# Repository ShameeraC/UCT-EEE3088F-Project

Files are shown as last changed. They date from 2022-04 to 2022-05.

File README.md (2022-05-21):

# EEE3088F Group 18 Sensing HAT (Version 1.0)
This project is a group project for the course EEE3088F at UCT. The purpose of the HAT is to detect light and move a motor or another device in the direction of the light.

# Instructions For Use (For Version 1.0)
    
    - Hardware Requirements - 

    To use this HAT, a mini-USB connector is required to interface the HAT with the STM 
    (Or whatever other microcontroller is in use). That being said, an STM32F0 discovery board, 
    or another board containing a microcontroller with read/write/ADC/memory capabilities must be used if 
    the full functionality of the HAT is to be claimed.
    The USB must be capable of data transmission.
    A 5V Li-Ion battery and battery holder are necessary for the powering of the HAT, unless some other 
    power source is to be used. Jumper cables are necessary for the current design, as it does not conform
    to the general standard of board measurements (they are needed to connect the HAT to the board in use).
   
    - Software Requirements -

    The coding of this board can be done via the STM Cube IDE (preferred) or Code Blocks. Other coding
    platforms can work as well. The terminal must be configured to drive the USB ports that connect to the
    discovery board or the HAT. 
    Programs can be uploaded to the STM or to the HAT itself, depending on which method is preferred.
    The EEPROM on the HAT must be coded via the HAT's USB port, as this sends data to and from the FTDI
    and the EEPROM on board the HAT together. 
    Currently the HAT has not been revised, and secondary versions have not yet been created. Because of this,
    the recommended approach to coding is to do so via the STM or the board in use (and not via the HAT).
    The temperature sensor which sends data to and from the HAT's EEPROM was not populated in version 1.0,
    and as such the EEPROM and the FTDI on board the HAT are not needed or useful currently.
    Thus, any code that is written should be uploaded directly to the board in use, after which wiring
    can interface the board with the HAT.

    - Initialization Instructions -

    To initialize the hardware, connect the battery to the HAT to power the STM board (if batteries 
    are not being used, find another way to connect the HAT to power). Connect each 
    pin on the STM to the corresponding pin on the HAT via jumper wires.
    To initialize the software, connect to the board via a USB, and compile and upload the desired 
    code to the board via an appropriate IDE. How to upload code to the board will vary from IDE to
    IDE. Check the IDE's online documentation for further details.

    - Running Your First Program on the HAT - 

    To run your first program on the HAT, refer to the self-explanatory code in the "main.c" file
    in the following directory:
    "Firmware/GROUP18 Microcontroler Interfacing/Core/src/main.c"
    This file can be run to toggle two user connected LEDs based on the strength of light sensed by
    the LDRs on the HAT. To set up the hardware for this basic program, two LEDs should be connected
    in series with 1k resistors which will be connected to GPIOA and GPIOB on the STM (GPIO pin 10 and
    pin 12 respectively). Alternitavely, the LEDs on the STM can be flashed based on the state of the
    LDRs if the STM LEDs are set to "HIGH" in the lightSensingInit() function (this would need to be
    added). Inside of the while loop in the code, the first statement is a call to initialize the light
    sensing sequence, and so everything is set up for ease of use.
    Have fun!! 

# Directories:
This repo has the following subfolders, which provide a useful common structure for custom electronics projects: \
    * Documentation: Project documentation (including submissions) and component datasheets are stored here.\
    * Firmware: Any software developed for the hat will be stored here.\
    * PCB: This includes all KiCad files (schematics, pcb, gerber files, footprints etc.). The main KiCad folder is here. \
    * Production: The gerber files, BOM, Budget, or anything required by JLCPCB will be stored here. \
    * Simulation: Any simulation files (eg SPICE) or design stage generated results (Eg matlab or excel) will be stored here.

# PCB Designers:
JONATHAN APPS \
SHAMEERA CASSIM \
JAHAR PERSAD 

# License
[Creative Commons Attribution 4.0 International license](https://choosealicense.com/licenses/cc-by-4.0/)

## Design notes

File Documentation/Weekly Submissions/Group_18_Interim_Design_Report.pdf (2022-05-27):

UNIVERSITY OF CAPE TOWN

EEE3088F, 2022

INTERIM DESIGN REPORT:

LIGHT TRACKING AND TEMPERATURE SENSING HAT

APRIL 4, 2022

GROUP 18

JONATHAN APPS (APPJON001)

SHAMEERA CASSIM (CSSSHA020)

JAHAR PERSAD (PRSJAH002)

### 1. Executive Summary

The following report documents the design process and current design of a Discovery board HAT intended for use as a light tracking device. For reference, PCB design files are available in the following Gitlab repository:

https://gitlab.com/g5168/eee3088f-group-18-project

The report begins by introducing the HAT concept as well as its use case, design details, and key results. A block diagram is used to overview the final design, after which the specifications for each submodule are detailed (power, microcontroller interfacing, sensing). Power budget analyses for the submodules, as well as for the entire design are then given. The design processes are then overviewed, and lastly conclusions are made.
For further details, including licensing, reusing, and deploying, see the gitlab repository.

### 2. Introduction

The HAT was designed to operate a rotating frame which is intended to sense the direction in which the light is brightest. The HAT will be programmed to rotate the frame, using 2 motors, to point its face in the direction of maximum brightness. This design can be used for many applications, although its primary use case is intended to be to efficiently generate power through solar panels. A small solar panel could be connected to the face of the frame (this will be omitted from the design however, as solar panels will be connected to the frame by the user) and the rotation of the frame will allow for optimal sunlight to be provided to the panel at all times.

The HAT uses 2 sensor types (one digital, one analog) to support this design. The digital sensor is a temperature sensor (LM75B) which monitors the temperature of the HAT to check for overheating (which causes design/solar panel inefficiencies). The analog sensor is made up of 2 photoresistors (GL5549’s), which enable the evaluation of brightness on both sides of the HAT. This in turn enables the controlling of the peripheral device’s rotation.

The HAT’s power module uses batteries to drive the operation of the sensors and the microcontroller interfacing. Under-voltage protection, battery polarity-protection, and input voltage polarity protection are some of the features that operate the HAT in a stable manner. The HAT includes microcontroller interfacing abilities, which enable the transmission of data to and from the STM32.

This design could be implemented for small-scale energy projects. Users who desire the powering of a small device (during load shedding for instance) could use the HAT to generate power for a load. It could also be used for small robots which need to track light.

For this to be a useful design, the power generated by the HAT must exceed the power consumed by the HAT. The power specifications for this design will thus be discussed later in this report. The total cost of the HAT was approximately $62.33, excluding shipping costs.

### 2.1. Project Subsystems Block Diagram

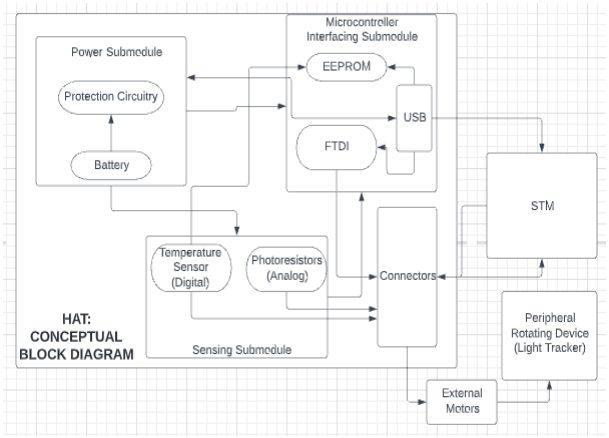
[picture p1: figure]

Figure 1: Projects Subsystem Block Diagram

### 3. Specifications

### 3.1 Power Subsystem Submodule

This submodule delivers 5V, and receives a voltage between 4.5 and 6V. The max current in the circuit is 22mA, the reason it was done this way is that anything above 30mA will blow the LED.

The circuit contains the following circuits/components:
1. A 18650 connector (DNP)
2. A Li-Ion battery charger
3. Input voltage polarity protection
4. Battery polarity protection
5. Battery Under-voltage cutout protection
6. This module will provide an output of 5V

There were 2 ICs used:
1. MT3608L - DC-DC converter, used to step up the voltage to a constant 5V to be outputted from the submodule
2. TP4054 - Used to charge the battery

Parts List
Part | LCSC | Datasheets
R1 | C4177 | https://datasheet.lcsc.com/lcsc/2110251730_UNI-ROYAL-Uniroyal-Elec-0603WAF1801T5E_C4177.pdf (https://datasheet.lcsc.com/lcsc/2110251730_UNI-ROYAL-Uniroyal-Elec-0603WAF1801T5E_C4177.pdf)
R2 | C22775 | https://datasheet.lcsc.com/lcsc/2110252030_UNI-ROYAL-Uniroyal-Elec-0603WAF1000T5E_C22775.pdf (https://datasheet.lcsc.com/lcsc/2110252030_UNI-ROYAL-Uniroyal-Elec-0603WAF1000T5E_C22775.pdf)
R3 | C22775
R4 | C22775
R5 | C22765 | https://datasheet.lcsc.com/lcsc/2110252030_UNI-ROYAL-Uniroyal-Elec-0603WAF1201T5E_C22765.pdf (https://datasheet.lcsc.com/lcsc/2110252030_UNI-ROYAL-Uniroyal-Elec-0603WAF1201T5E_C22765.pdf)
R6 | C25805 | https://datasheet.lcsc.com/lcsc/2110260030_UNI-ROYAL-Uniroyal-Elec-0603WAF1103T5E_C25805.pdf (https://datasheet.lcsc.com/lcsc/2110260030_UNI-ROYAL-Uniroyal-Elec-0603WAF1103T5E_C25805.pdf)
R7 | C22809 | https://datasheet.lcsc.com/lcsc/2110252030_UNI-ROYAL-Uniroyal-Elec-0603WAF1502T5E_C22809.pdf (https://datasheet.lcsc.com/lcsc/2110252030_UNI-ROYAL-Uniroyal-Elec-0603WAF1502T5E_C22809.pdf)
Charging IC(TP4054) | C32574 | https://datasheet.lcsc.com/lcsc/1809261814_TOPPO WER-Nanjing-Extension-Microelectronics-TP4054-42- (https://datasheet.lcsc.com/lcsc/1809261814_TOPPOWER-Nanjing-Extension-Microelectronics-TP4054-42-SOT25R_C32574.pdf)

| | SOT25R_C32574.pdf (https://datasheet.lcsc.com/lcsc/1809261814_TOPPOWER-Nanjing-Extension-Microelectronics-TP4054-42-SOT25R_C32574.pdf)
DC-DC Converter(MT3608L) | C2932326 | https://datasheet.lcsc.com/lcsc/2201121530_XI-AN-Aerosemi-Tech-MT3608L_C2932326.pdf (https://datasheet.lcsc.com/lcsc/2201121530_XI-AN-Aerosemi-Tech-MT3608L_C2932326.pdf)
C1 | C15849 | https://datasheet.lcsc.com/lcsc/1811061822_FH-Guan gdong-Fenghua-Advanced-Tech-0603CG6R0C500NT _C37474.pdf (https://datasheet.lcsc.com/lcsc/1811061822_FH-Guangdong-Fenghua-Advanced-Tech-0603CG6R0C500NT_C37474.pdf)
C2 | C45783 | https://datasheet.lcsc.com/lcsc/1811151152_Samsung-Electro-Mechanics-CL21A226MAQNNNE_C45783.p df (https://datasheet.lcsc.com/lcsc/1811151152_Samsung-Electro-Mechanics-CL21A226MAQNNNE_C45783.pdf)
D1 | C84256 | https://datasheet.lcsc.com/lcsc/1810010213_Everlight-Elec-PT17-21C-L41-TR8_C100090.pdf (https://datasheet.lcsc.com/lcsc/1810010213_Everlight-Elec-PT17-21C-L41-TR8_C100090.pdf)
D2 | C84256
D3 | C191023 | https://datasheet.lcsc.com/lcsc/1810202112_Guangdong-Hottech-1N5819WS_C191023.pdf (https://datasheet.lcsc.com/lcsc/1810202112_Guangdong-Hottech-1N5819WS_C191023.pdf)
L1 | C383376 | https://datasheet.lcsc.com/lcsc/1912111437_TDK-MLP2012V4R7MT0S1_C383376.pdf (https://datasheet.lcsc.com/lcsc/1912111437_TDK-MLP2012V4R7MT0S1_C383376.pdf)
Q1 | C118536 | https://datasheet.lcsc.com/lcsc/1912111437_Foshan-Blue-Rocket-Elec-2N2222A_C358533.pdf (https://datasheet.lcsc.com/lcsc/1912111437_Foshan-Blue-Rocket-Elec-2N2222A_C358533.pdf)

### 3.1.1 Power Subsystem Schematic

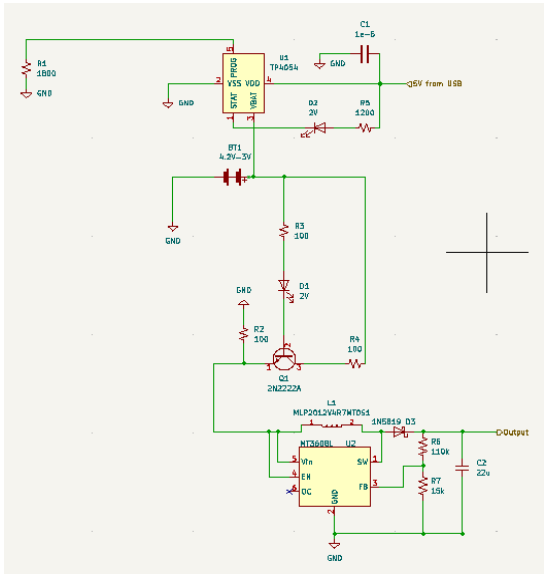
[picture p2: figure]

Figure 2: Power Subsystem Schematic

Location in git:
https://gitlab.com/g5168/eee3088f-group-18-project/-/blob/main/PCB/main/power.kicad_sch

### 3.1.2 Conclusion

This design is deemed safe, there is a bit of uncertainty when it comes to the calculations of how much current is flowing through this module, but otherwise it seems safe. It is not the most efficient design since a lot of parts that have a power dissipation associated were used. But the design should be able to perform its duties.

### 3.2 Microcontroller Interfacing Submodule

### 3.2.1 Specifications

The specifications for this submodule have been tabulated below:
Item | Requirement | Specification | Additional Notes and Documentation Links
| Memory
| This subsection includes communication protocols, both the ICs used for memory and their power specifications.
M1 | Key configuration data must be kept in a non-volatile medium and data from the temperature sensor must be time-stamped and stored alongside this throughout the operational period | EEPROM needs to be used to store configuration data and to read in and store data from the temperature sensor. The AT24C256C-SSHL-T is a 256-Kbit EEPROM chip with a SOIC-8_3.9x4.9x1.27P package. Memory can be retrieved from the line connected to the WP pin of the EEPROM. This IC operates between 1.7V and 5.5V with a maximum current of 2mA for reading data and 3mA for writing data at V=5V. | Datasheet: https://datasheet.lcsc.com/lcsc/1809151932_Microchip-Tech-AT24C256C-SSHL-T_C6482.pdf (https://datasheet.lcsc.com/lcsc/1809151932_Microchip-Tech-AT24C256C-SSHL-T_C6482.pdf)
M2 | Translate USB to UART to be written to the STM | A CH340C chip can be used to interface between the USB and memory. The chip “translates” the data from USB to USART in the form of an array. The typical operating conditions for this IC is a 5V supply voltage and a 7mA current. It has a maximum current of 20mA. | Datasheet: https://www.mpja.com/download/35227cpdata.pdf (https://www.mpja.com/download/35227cpdata.pdf)
| Clock
C1 | Measure at a minimum of 1/60 Hz which is required to be soft-configurable. | PA8 connected to the STM32F051 will be used. The pin will be programmed to output the relevant clock signal.

| USB
U1a | Transfer data and provide power. The USB provides 5V (VCC_in). | A MicroXNJ USB Surface Mount Micro-B/USB Connector is used for power and data transfer. | Datasheet: https://datasheet.lcsc.com/lcsc/2204151400_SHOU-HAN-MicroXNJ_C404969.pdf (https://datasheet.lcsc.com/lcsc/2204151400_SHOU-HAN-MicroXNJ_C404969.pdf) https://gitlab.com/g5168/eee3088f-group-18-project/-/blob/main/Documentation/Datasheets/2204151400_SHOU-HAN-MicroXNJ_C404969%20TRANSLAT ED.pdf (https://gitlab.com/g5168/eee3088f-group-18-project/-/blob/main/Documentation/Datasheets/2204151400_SHOU-HAN-MicroXNJ_C404969%20TRANSLATED.pdf) (both used in conjunction as translation is not fully clear)
U1b | | A USB-MicroB cable is needed to connect the microcontroller to the HAT. | These may be reused from the equipment given out for EEE2046F.

Parts List
Component | LCSC | Datasheet
EEPROM -AT24C256C-SSHL-T | C6482 | https://datasheet.lcsc.com/lcsc/1809151932_Microchip-Tech-AT24C256C-SSHL-T_C6482.pdf (https://datasheet.lcsc.com/lcsc/1809151932_Microchip-Tech-AT24C256C-SSHL-T_C6482.pdf)
FTDI - CH340C | C84681 | https://www.mpja.com/download/35 227cpdata.pdf (https://www.mpja.com/download/35227cpdata.pdf)
MicroXNJ | C404969 | https://datasheet.lcsc.com/lcsc/2204151400_SHOU-HAN-MicroXNJ_C 404969.pdf (https://datasheet.lcsc.com/lcsc/2204151400_SHOU-HAN-MicroXNJ_C404969.pdf)
R14 | C25804 | https://datasheet.lcsc.com/lcsc/2110260030_UNI-ROYAL-Uniroyal-Elec-0603WAF1002T5E_C25 804.pdf (https://datasheet.lcsc.com/lcsc/2110260030_UNI-ROYAL-Uniroyal-Elec-0603WAF1002T5E_C25804.pdf)
R15 | C21190 | https://datasheet.lcsc.com/lcsc/2110252030_UNI-ROYAL-Uniroyal-Elec-0603WAF1001T5E_C21 190.pdf (https://datasheet.lcsc.com/lcsc/2110252030_UNI-ROYAL-Uniroyal-Elec-0603WAF1001T5E_C21190.pdf)
R16 | C21190
R17 | C21190
R18 | C23162 | https://datasheet.lcsc.com/lcsc/2110252130_UNI-ROYAL-Uniroyal-Elec-0603WAF4701T5E_C23 162.pdf (https://datasheet.lcsc.com/lcsc/2110252130_UNI-ROYAL-Uniroyal-Elec-0603WAF4701T5E_C23162.pdf)

R19 | C21189 | https://datasheet.lcsc.com/lcsc/2 110252030_UNI-ROYAL-Uniroy al-Elec-0603WAF0000T5E_C21 189.pdf (https://datasheet.lcsc.com/lcsc/2110252030_UNI-ROYAL-Uniroyal-Elec-0603WAF0000T5E_C21189.pdf)
R20 | C21189
D4 (SS14) | C2480 | https://datasheet.lcsc.com/lcsc/2 105061432_MDD-Microdiode-El ectronics--SS14_C2480.pdf (https://datasheet.lcsc.com/lcsc/2105061432_MDD-Microdiode-Electronics--SS14_C2480.pdf)
C4 | C14663 | https://datasheet.lcsc.com/lcsc/1 809301912_YAGEO-CC0603KR X7R9BB104_C14663.pdf (https://datasheet.lcsc.com/lcsc/1809301912_YAGEO-CC0603KRX7R9BB104_C14663.pdf)

### 3.2.2 Microcontroller Interfacing Subsystem Schematic

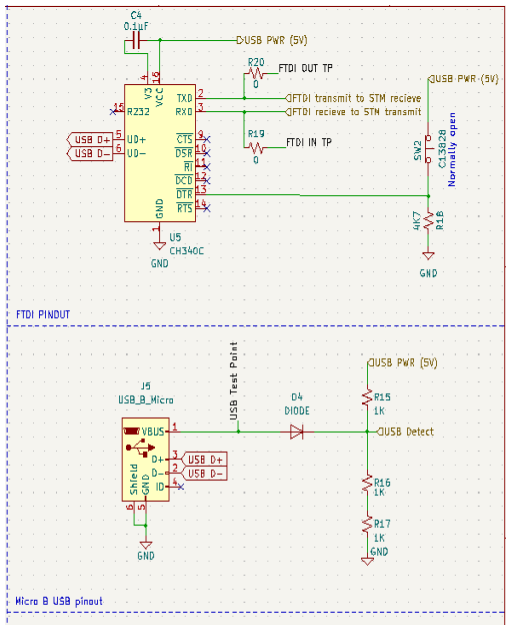
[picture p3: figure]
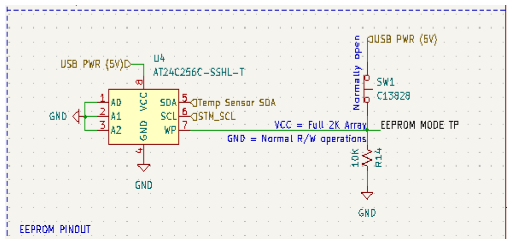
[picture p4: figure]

Figure 3: Microcontroller Interfacing Subsystem Schematic

Location in git:
https://gitlab.com/g5168/eee3088f-group-18-project/-/blob/main/PCB/main/microcontroller_interfacing.kicad_sch (https://gitlab.com/g5168/eee3088f-group-18-project/-/blob/main/PCB/main/microcontroller_interfacing.kicad_sch)

### 3.2.3 Conclusion:

The design is safe, sufficient and largely should work. An outstanding issue that was picked up after submitting the gerbers was that the output of the EEPROM is not connected to an STM pin and hence is not writing to anything. Thus, the information being stored in the EEPROM cannot be seen. Fixing this will require the soldering of a wire to the PCB and using that to connect to the STM to write the data to I2C (this will be done when the PCB is returned). It has also been noted that the schottky diode used was replaced by an LED when gerbers and assembly documentation was uploaded to jlcpcb. This will also be rectified when the PCBs are returned. The documentation in this report takes into account the schottky diode and not the LED.

### 3.3 Sensing submodules

The specifications for this submodule have been tabulated below:

### 3.3.1 Digital Sensor Specification

Item | Specifications | Additional Notes | Datasheet Links
1 | One LM75BD Temperature sensor is used. | This operates at 2.8V - 5.5V, and as such is perfect for the HAT as a digital sensor. Further operating conditions can be found in the attached datasheet. | https://datasheet.lcsc.com/lcs c/2110111830_UMW-Youtai- Semiconductor-Co---Ltd--LM 75BD_C725792.pdf (https://datasheet.lcsc.com/lcsc/2110111830_UMW-Youtai-Semiconductor-Co---Ltd--LM75BD_C725792.pdf)
2 | One red LED (BL-HUE35A-AV-TRE) is used to indicate that the temperature is outside optimal functioning conditions.

This is connected to a pin which reads the LM75. The
temperature data register
will be polled to ensure that when the temperature
exceeds a specified limit, the LED is lit up.

https://datasheet.lcsc.com/szlcsc/1809192334_BrtLed-Brig ht-LED-Elec-BL-HUE35A-AV-TRE_C138549.pdf (https://datasheet.lcsc.com/szlcsc/1809192334_BrtLed-Bright-LED-Elec-BL-HUE35A-AV-TRE_C138549.pdf)

3 | 20mA of forward current through the LED must not be exceeded. | Thus, a resistor in place to ensure correct operation (see Item 4). | N/A
4 | Items 2 and 3 necessitate the use of a 300Ω resistor. Unfortunately this was overlooked during the design process, and a 10kΩ resistor was used | Performing a KVL analysis on a 5V power supply in series with a 300Ω resistor (with a forward voltage | N/A

| instead. This will be corrected when the PCB is returned. | drop of 3V) and a 2V LED, shows that the current through the LED will be: I = V/R = 3/300 = 10mA. This is a correct operating current for the LED.
5 | One C45783 capacitor was used, to decouple the signal at the Vcc pin. | This adds safety from undesirable noise signals. | https://datasheet.lcsc.com/lcsc/1809291518_TORCH-CT4 1G-0402-2X1-16V-0-1-F-K-N _C141382.pdf (https://datasheet.lcsc.com/lcsc/1809291518_TORCH-CT41G-0402-2X1-16V-0-1-F-K-N_C141382.pdf)
6 | Three RCT0310KJLF 0.1W, 10KΩ resistors are used. No more than 0.1W is dissipated by each resistor. | These act as pull-ups for the temperature sensors. Pull-up resistors are necessary for this temperature circuit configuration at the bus output and the interrupt line. | https://datasheet.lcsc.com/lcsc/1810161330_HKR-Hong-K ong-Resistors-RCT0310KJL F_C177337.pdf (https://datasheet.lcsc.com/lcsc/1810161330_HKR-Hong-Kong-Resistors-RCT0310KJLF_C177337.pdf)

### 3.3.2 Analog Sensor Specification

Item | Specifications | Additional Notes | Datasheet Links
1 | The HAT uses 2 GL48516 photoresistors (LDRs). | These assume values of 5-10 KΩ at 10 LUX, and approximately 0.2 MΩ in the dark. | https://datasheet.lcsc.com/lcsc/2009121137_JCHL-She nzhen-Jing-Chuang-He-Li-T ech-GL48516_C779572.pdf (https://datasheet.lcsc.com/lcsc/2009121137_JCHL-Shenzhen-Jing-Chuang-He-Li-Tech-GL48516_C779572.pdf)
2 | Two RCT0310KJLF 0.1W, 10KΩ resistors were used. No more than 0.1W is dissipated by each resistor. | These were placed in series with the LDRs in 2 separate voltage divider configurations. | https://datasheet.lcsc.com/lcsc/1810161330_HKR-Hon g-Kong-Resistors-RCT0310 KJLF_C177337.pdf (https://datasheet.lcsc.com/lcsc/1810161330_HKR-Hong-Kong-Resistors-RCT0310KJLF_C177337.pdf)
3 | The LDRs were placed on opposite sides of the HAT to ensure that the light on each of them is slightly different. | The photoresistors cannot be placed very closely together on the final HAT pcb. | N/A
4 | The outputs from the voltage divider configurations operate between 2.4V and 3.6V. | GPIO pins in analog mode operate between 2.4V and 3.6V. ADC pins will be | N/A

| | needed when the software is implemented.
5 | Item 4 implies that the input voltage should lie at around 5V. Thus the input voltage to the photoresistor voltage divider configuration was connected to the STM32F0’s 5V pin. | This was an important design decision for the pcb’s routing. | N/A

### 3.3.3 Sensing Submodule Schematic

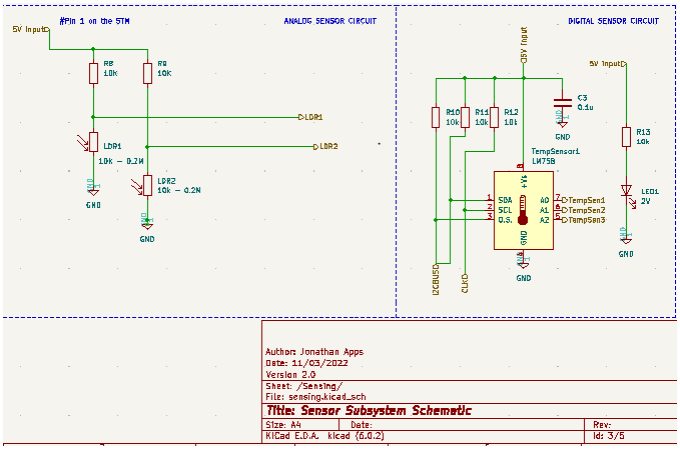
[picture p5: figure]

Figure 4: Sensing Subsystem Schematic

Location on git:
https://gitlab.com/g5168/eee3088f-group-18-project/-/blob/main/PCB/main/sensing.kicad_sch (https://gitlab.com/g5168/eee3088f-group-18-project/-/blob/main/PCB/main/sensing.kicad_sch)

### 3.3.4 Conclusion

This module relies heavily on the power and microcontroller interfacing modules to function. Provided that those modules function correctly, the sensing submodule should function correctly as it is very simple in terms of design and components. The sensors are adequately designed and thus sufficient for the purposes they are needed for. There is one clear error in the design of this module, which is the use of a 10kΩ resistor in place of the necessary 300Ω. The 10kΩ resistor will be replaced with the 300Ω resistor once the pcb is returned.

### 4. Power Budget Analysis

### 4.1 Power Submodule Budget Analysis

Component | Supply Voltage (nominal V) | Min Current (mA) | Typical Current (mA) | Max Current (mA) | Min Power (mW) | Typical Power (mW) | Max Power (mW)
TP4054 | 5 | 90 | 100 | 110 | 450 | 500 | 550
R1 | 3-4.2 | 10 | 22 | 30 | 36 | 79.2 | 108
R2 | 3-3.5 | 10 | 22 | 30 | 32.5 | 71.5 | 97.5
R3 | 3-4.2 | 10 | 22 | 30 | 36 | 79.2 | 108
R4 | 5 | 10 | 22 | 30 | 50 | 110 | 150
R5 | 5 | 10 | 22 | 30 | 50 | 110 | 150
R6 | 5 | 10 | 22 | 30 | 50 | 110 | 150
R7 | 5 | 10 | 22 | 30 | 50 | 110 | 150
C1 | 5 | 10 | 22 | 30 | 50 | 110 | 150
C2 | 5 | 10 | 22 | 30 | 50 | 110 | 150
D1 | 3-4.2 | 10 | 22 | 30 | 36 | 79.2 | 108
D2 | 5 | 10 | 22 | 30 | 50 | 110 | 150
D3 | 5 | 10 | 22 | 30 | 50 | 110 | 150
L1 | 5 | 10 | 22 | 30 | 50 | 110 | 150
MT3608L | 0.01-1.5 | - | 1.6 | 2.2 | - | 2.4 | 3.3
Total | | | | | 998.5 | 1709.1 | 2198.8

### 4.2 Microcontroller Interfacing Submodule Budget Analysis

Component | Supply Voltage (nominal V) | Min Current (mA) | Typical Current (mA) | Max Current (mA) | Min Power (mW) | Typical Power (mW) | Max Power (mW)
EEPROM -AT24C256C -SSHL-T (read/write) | 5.0 | - | 1 | 2 | - | 5 | 10
| 5.0 | - | 2 | 3 | - | 10 | 15
FTDI -CH340C | 3.3 | - | 7 | 20 | - | 23.10 | 66
R14 | 5 | 10 | 22 | 30 | 50 | 110 | 150
R15 | 5 | 10 | 22 | 30 | 50 | 110 | 150
R16 | 5 | 10 | 22 | 30 | 50 | 110 | 150
R17 | 5 | 10 | 22 | 30 | 50 | 110 | 150
R18 | 5 | 10 | 22 | 30 | 50 | 110 | 150
R19 | 5 | 10 | 22 | 30 | 50 | 110 | 150
R20 | 5 | 10 | 22 | 30 | 50 | 110 | 150
D4 (SS14) | 5 | 10 | 22 | 30 | 50 | 110 | 150
C4 | 5 | 10 | 22 | 30 | 50 | 110 | 150
Total | | | | | 450.00 | 1028.10 | 1441.00

### 4.3 Sensing Submodules Budget Analysis

Component | Supply Voltage (nominal V) | Min Current (mA) | Typical Current (mA) | Max Current (mA) | Min Power (mW) | Typical Power (mW) | Max Power (mW)
R8 | 5 | 0.025 | 0.2 | 0.25 | 0.125 | 1 | 1.25
R9 | 5 | 0.025 | 0.2 | 0.25 | 0.125 | 1 | 1.25

R10 | 5 | 0.14 | 0.2 | 0.5 | 0.7 | 1 | 2.5
R11 | 5 | 0.14 | 0.2 | 0.5 | 0.7 | 1 | 2.5
R12 | 5 | 0.14 | 0.2 | 0.5 | 0.7 | 1 | 2.5
R13 | 5 | 9 | 10 | 11 | 45 | 50 | 55
C3 | 5 | 0 | 0.2 | 0.5 | 0 | 1 | 2.5
LED1 | 2 | 9 | 10 | 11 | 18 | 20 | 22
LDR1 | 2.4-3.6 | 0.025 | 0.0476 | 0.25 | 0.06 | 0.14 | 0.216
LDR2 | 2.4-3.6 | 0.025 | | 0.25 | 0.06 | 0.14 | 0.216
LM75B | 5 | 0.004 | 0.28 | 0.4 | 0.02 | 1.4 | 2
Total | | | | | 65.49 | 77.68 | 91.932

### 4.4 System Total

Submodule | Minimum Power(mW) | Typical Power(mW) | Maximum Power(mW)
Power | 984.50 | 1678.30 | 2156.80
Sensing | 65.49 | 77.68 | 91.932
Microcontroller Interfacing | 450.00 | 1028.10 | 1441.00
Totals | 1499.99 | 2784.08 | 3689.73

### 5. Design process

The design process for this board was as follows:
Each team member developed a design for their respective submodule, after which the team met and discussed whether the designs would work well in conjunction with each other and revisions of each submodule were made. The design process was iterative, it started off with a base design which was improved each week to get the final product.

Key decisions relating to the schematics that were made include:

- The removal of the operational amplifier after the first revision as it would drain the battery even after the under voltage cut out protection kicked in (power module).
- The step down dc-dc converter was swapped out for a step up dc-dc converter as this mitigated the need to amplify the voltage after the transistor before entering the previously used step down dc-dc converter. This also resulted in the final design of the power submodule using less components overall. (power module)
- The initial EEPROM chosen was changed to match that suggested by the lecturers. This EEPROM IC matched the specifications of the project better and there are more resources available on how to use it effectively. (microcontroller interfacing module)
- The FTDI chip was chosen specifically to include an internal crystal oscillator so that one would not have to be included on the board. This allows for the design of an individual oscillator to be avoided (microcontroller interfacing module).
- Initially, there were 4 photoresistors, 2 of which enabled the HAT to rotate the peripheral module based on the light strengths on it. This, along with a push button controlling whether on-HAT or on-peripheral LDRs would be used to sense light, was removed. This removal was done to save power and remove complexity from the design (sensor module).

Key decisions that were made with regards to the PCB include:

- The GND plane was chosen to be on the front copper layer(top) and the +5V plane on the back copper layer(bottom), as this allowed for more efficient tracing (more components required ground connections than power connections)
- The LDRs were specifically chosen to be on opposite sides of the board to ensure that light could be tracked from multiple directions.
- Distance was intentionally put between the pushbuttons and the temperature sensor to avoid the user’s body heat affecting the sensor’s output.
- The MicroXNJ USB port was chosen to be on the opposite side of the board as the STM USB port to avoid the two being on top of each other and preventing the HAT and STM from connecting as they should.

### 6. Conclusion

The HAT is intended to control the rotation of an external frame based on the direction of the light detected. This could be used in several contexts but this design largely focused on the use case of rotating solar panels to optimize the amount of energy produced. The design process was iterative and in some parts components were chosen and tested via trial and error.
The iterative nature of the decisions made contributed to the simplicity of the final design. Many design paths could have been taken, but the choices made minimized the complexity and inefficiencies in the final PCB. Although some errors remain, these will be mitigated or fixed by soldering additional components to the HAT when it is returned.
Overall, the completed design was under-budget both in terms of cost (before shipping) and power. The expected power consumption of the HAT is approximately 2.8W and the price of the 5 PCBs is expected to be $62.33 excluding shipping and customs. In theory, the individual modules are all expected to work and therefore it is expected that they will work well in conjunction with each other in reality.

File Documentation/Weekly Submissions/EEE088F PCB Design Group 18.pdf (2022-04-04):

UNIVERSITY OF CAPE TOWN

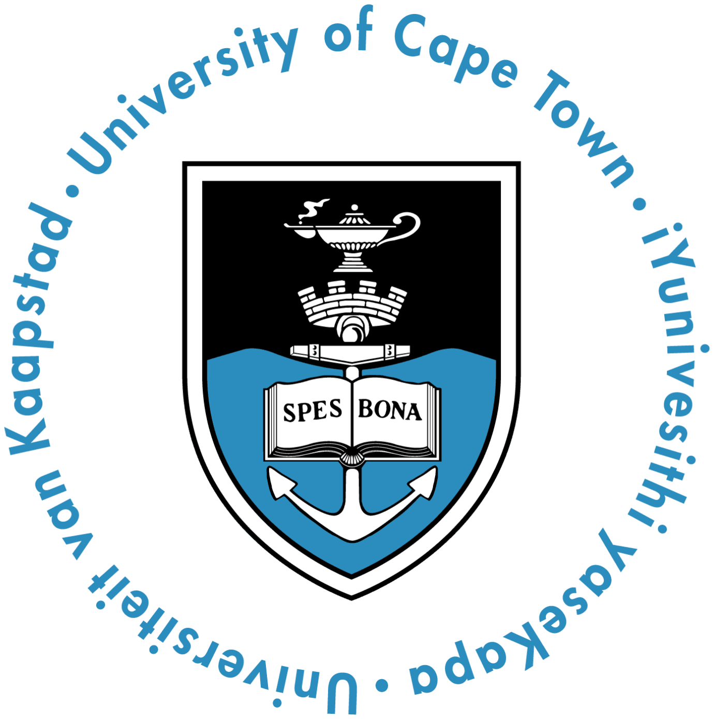
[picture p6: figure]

EEE3088F

PCB DESIGN ASSIGNMENT

MARCH 2022

GROUP 18

JONATHAN APPS (APPJON001)

SHAMEERA CASSIM (CSSSHA020)

JAHAR PERSAD (PRSJAH002)

### GIT

### 1. Github [1]

GitLab link: https://gitlab.com/g5168/eee3088f-group-project

The Gitlab branch “/Schematics Week 5” contains all relevant material for this assignment. Past versions of the design/schematics can be found in the “/main” branch.

### FAILURE MANAGEMENT

Note: All changes highlighted in red.

### 2. Power Subsystem Failure Management [2]

I have decided to order extra components and add traces in parallel to where the original components should be but leave it as an open circuit. In the event of trace damage or a component malfunction, I can utilize these traces in parallel. I have chosen multiple components (for each component) that could work if jlcpcb are out of stock at the time of ordering, then I can just use one of the alternatives. If there is an error in my circuit that I only detect post manufacture, I can make use of the parallel traces that I made to alter the values of components or even design a new circuit, I would just have to sever some of the other traces to make this work. Components that are large enough to re-solder, should one come off or break, have been chosen for this subsystem. Minimum component sizes of “0603” (metric) were chosen for this purpose. The failure management for this subsystem has not changed otherwise (since the last assignment), since it was approved and no modifications seem necessary.

### 3. Sensing Subsystem Failure Management [2]

The sensing subsystem will provide additional traces to connect to through-holes that can be used in the case of trace/component destruction. Should a component fail or be destroyed, additional components can be soldered on the through-holes of the pcb. As in the power subsystem, the traces will be connected in parallel to where the original components were set. Additional components will likely be collected from other sources that can replace the ones used in the pcb, so that component replacements can be done when/where necessary. While there are no over-voltage/power preventing mechanisms in the sensing subsystem, the module is powered directly from the discovery board which has power/voltage regulators internally.

Providing that the STM is operating properly, the sensing subsystem should be safe from failure. Components that are large enough to re-solder, should one come off or break, have been chosen for this subsystem. Minimum sizes of “0603” (metric) were chosen for this purpose. The failure management for this subsystem has not changed otherwise (since the last assignment), since it was approved and no modifications seem necessary.

### 4. Microcontroller interfacing Failure Management [2]

A diode is used to prevent surging to the USB mount from any external source the USB is connected to. Further, alternative EEPROM and FTDI chips have been considered and researched to ensure that in the event that the original component choices are unavailable at the time of PCB assembly, the schematics and gerbers can be updated for manufacturing. In the event that the AT24C256C-SSHL-T EEPROM is not available, there are M24C02-WMN6TP chips available which have the same amount of storage space and are also cheaper and will fit into the budget. In the case that the CH340C FTDI chip is unavailable, it is likely that the CH340G will be available. However, this chip would also require the addition of a clock as it has no integrated clock. There is also a decoupling capacitor to the input of the FTDI pin to ensure a stable DC supply. The microcontroller subsystem will provide additional traces to connect to through-holes that can be used in the case of trace/component destruction. Should a component fail or be destroyed, additional components can be soldered on the through-holes of the PCB. As in the other subsystems, the traces will be connected in parallel to where the original components were set. Components that are large enough to re-solder have been chosen for this subsystem. Minimum component sizes of “0603” (metric) were chosen for this purpose. If any components fail, replacements can be soldered onto the pcb easily. The code that will be uploaded onto the microcontroller will be stored on GitLab/GitHub in case the code is wiped from the microcontroller’s memory. Every time that the code for the STM is manipulated critically, it will be committed via Git. This ensures the security of code in the case of system failure.

### SCHEMATICS

### 5. Power Subsystem Schematic [2]

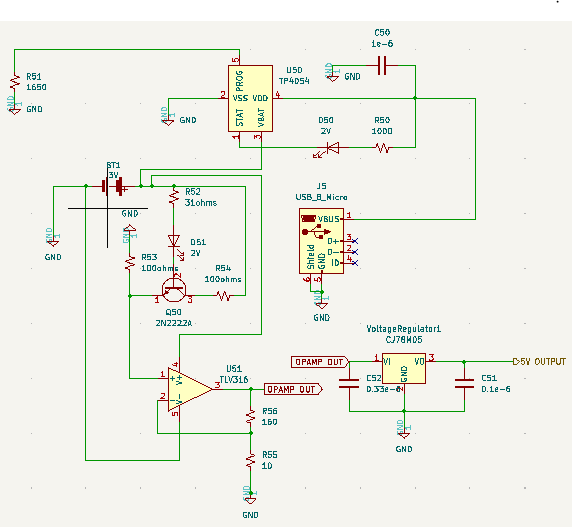
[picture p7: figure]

No changes were made from last week’s schematic, as it was approved and no inefficiencies/problems were discovered.

### 6. Sensing Subsystem Schematics [2]

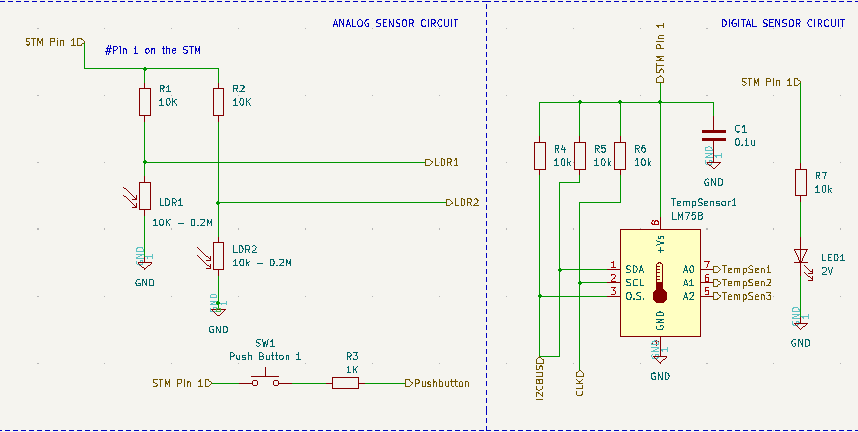
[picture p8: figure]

This schematic was changed by removing 2 LDRs and the corresponding resistors. The price of hand-soldering 4 LDRs made the BOM exceed the project budget, so only 2 LDRs were used. Jlcpcb had no non-hand-soldered photoresistors available to replace the photoresistors chosen. These adjustments mean that the peripheral system will be able to rotate in only two directions, rather than being multi-directional.

### 7. Microcontroller interfacing Schematic [2]

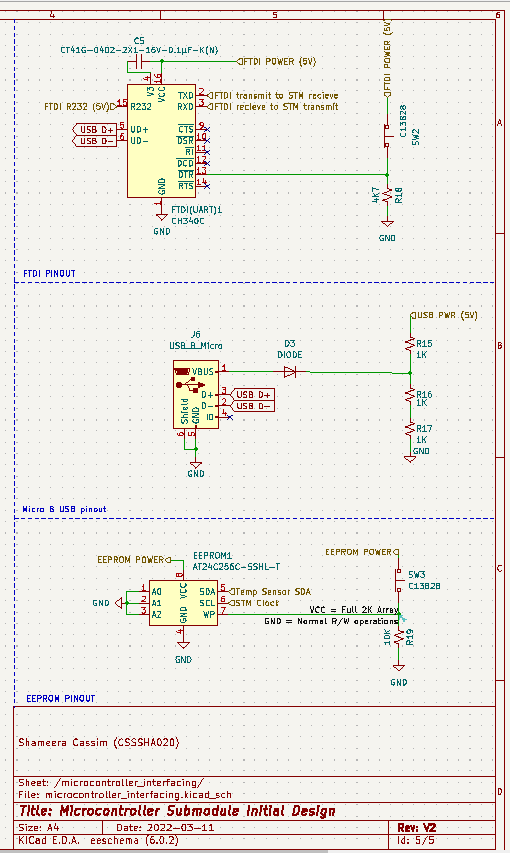
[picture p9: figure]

No changes were made from last week’s schematic, as it was approved and no inefficiencies/problems were discovered.

### ERROR CHECKING

### 8. Updated ERCs [2]

The built-in KiCad Error Report Checking function is being used for this assignment. This ERC alone is necessary to validate the schematics and circuitry.

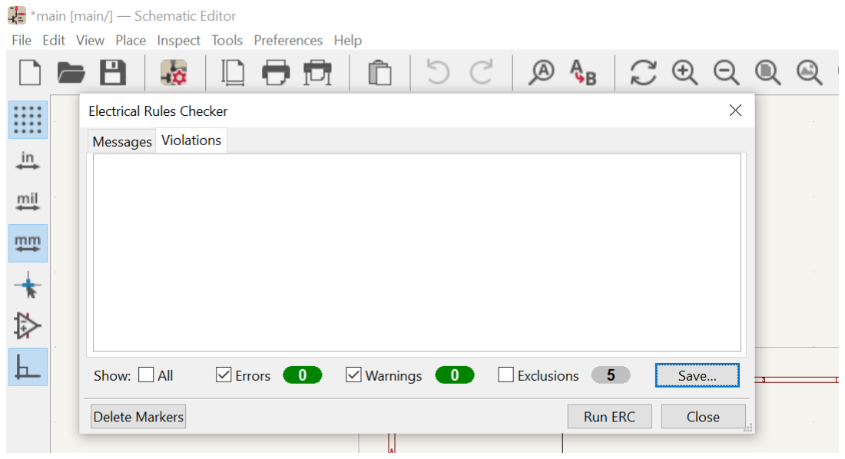
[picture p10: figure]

Five warnings and errors were excluded as they had no impact on the actual workings of the circuit.

### 9. DRCs [2]

The built-in KiCad Design Report Checking function is being used for this assignment. This DRC alone is necessary to validate the schematics and circuitry.

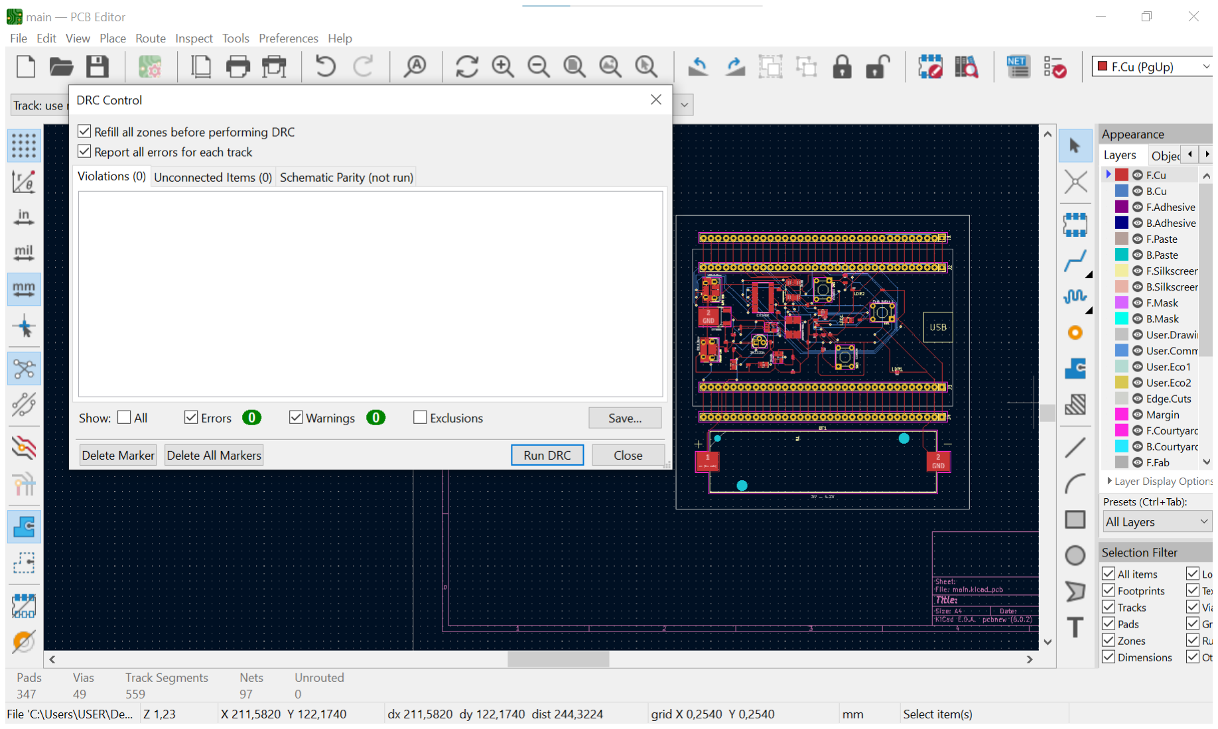
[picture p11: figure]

There were no errors or exclusions needed for the DRC.

### BILL OF MATERIALS

10.Updated BOM [5]

Link to Git documentation folder: https://gitlab.com/g5168/eee3088f-group-project/-/tree/main/Week%205%20Documentation

Both the BOM generated on KiCad and the one that was compiled on Excel are included here. Below is a complete budget for our HAT including assembly costs:

Unit | Description | Multiplier | Cost per unit ($) | Total Cost ($)

SENSOR

LM75BD | Temperature Sensor | 1 | 0,5734 | 0,5734
BL-HUE35A-AV-TRE | Red LED | 1 | 0,0234 | 0,0234
RCT02300RFLF | 300Ω Resistor | 1 | 0,0028 | 0,0028
CT41G-0402-2X1-16V-0.1μ F-K(N) | 0.1uF Capacitor | 1 | 0,0034 | 0,0034
RCT0310KJLF | 10KΩ Resistor | 7 | 0,0016 | 0,0112
GL48516 | Photoresistor | 4 | 0,0527 | 0,2108
C13828 | Push Button | 1 | 0,0382 | 0,0382

POWER

| Resistor | 7 | 0,0007 | 0,0049
| microusb in | 1 | 0,3 | 0,3
BL-HUE35A-TRE | LED | 2 | 0,1305 | 0,261
TP4054 | Charger IC | 1 | 0,2523 | 0,2523
2n2222A | NPN transistor | 1 | 0,1736 | 0,1736

78L05FS | Voltage regulator | 1 | 0,21 | 0,21
Tlv316 | op amp | 1 | 1,2 | 1,2
N/A | Capacitors | 3 | 0,001 | 0,003

MICROCONTROLLER

C404969 | Surface Mount
Micro-B SMD USB
Connector
1 | 0,048 | 0,048
CH340C | FTDI USB-to-UART
chip
1 | 0,7311 | 0,7311
M24128-BRMN6TP | EEPROM | 1 | 0,2052 | 0,2052
STM32F051 | Microcontroller chip & discovery kit | 1 | 0 | 0
USB to microB cable | USB to microB cable | 1 | 0 | 0

COMPONENT COST PER
BOARD

4,2523

TOTAL COMPONENT COSTS (5 BOARDS) | 21,2615

ASSEMBLY COSTS

Item | Multiplier | Unit Cost ($) | Cost ($)
SMT components | 36 | 0,0017 | 0,0612

Hand soldered
components
3 | 1,5 | 4,5

Extended parts [ once off
fee]
14 | 3 | 42

ASSEMBLY COST PER
BOARD

9,31224

TOTAL ASSEMBLY COST (5
BOARDS)

46,5612

TOTAL COST PER
BOARD

13,56454

TOTAL COST (5
BOARDS)

67,8227

### PCB DESIGN

11.PCB [15]

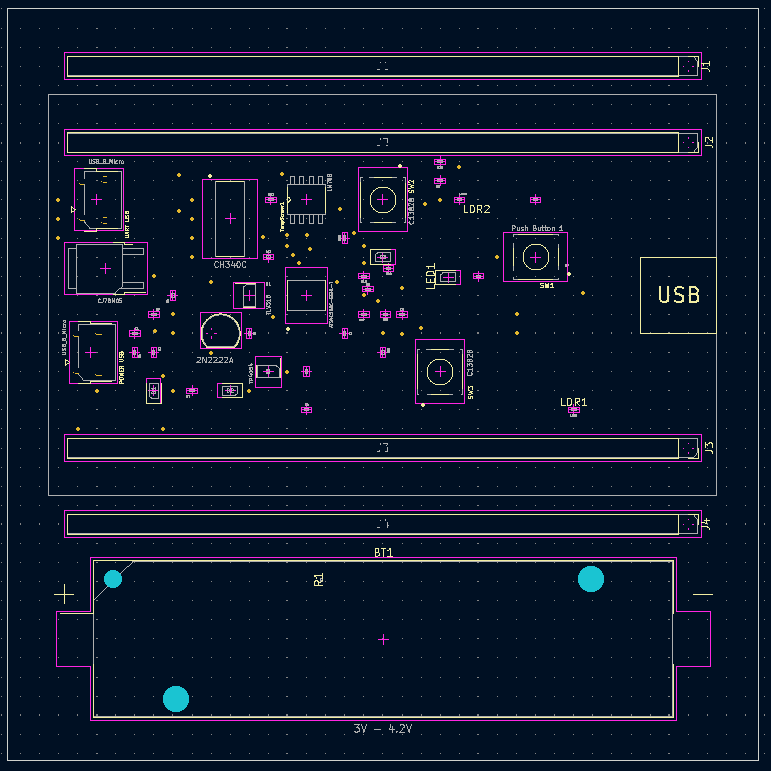
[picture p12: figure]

Edgecuts, Front: Courtyard, Fab & Silkscreen

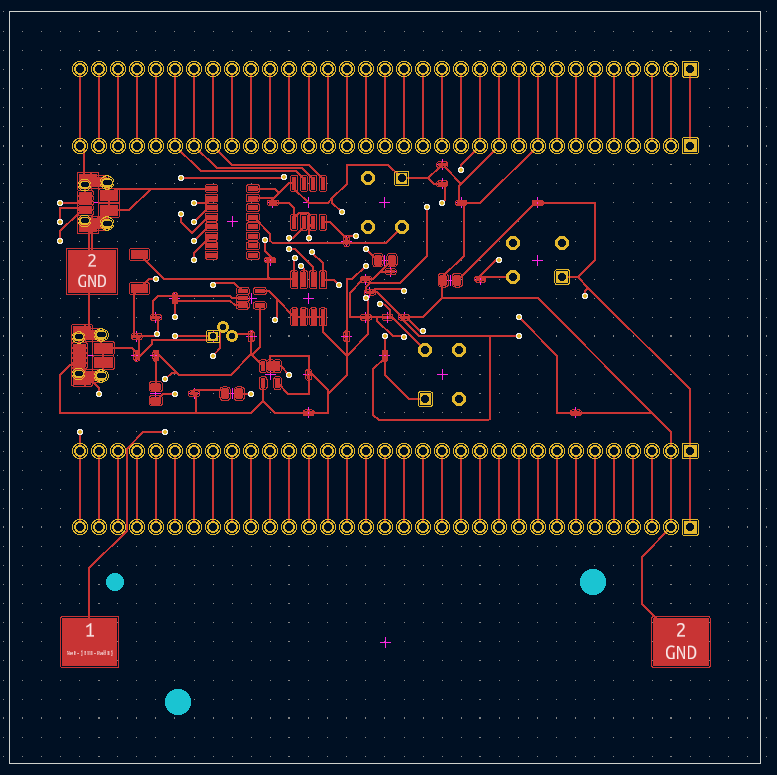
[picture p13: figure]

Front copper

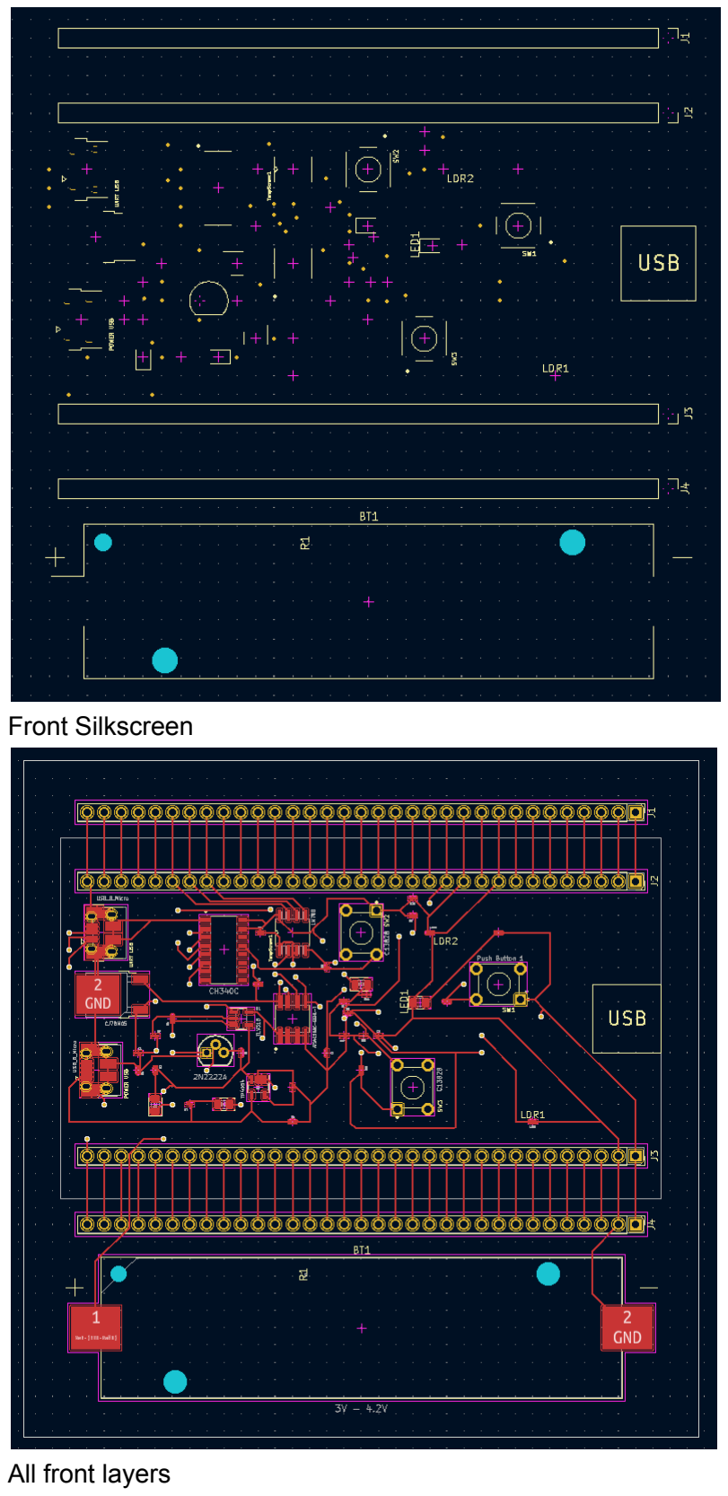
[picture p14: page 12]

Front Silkscreen

All front layers

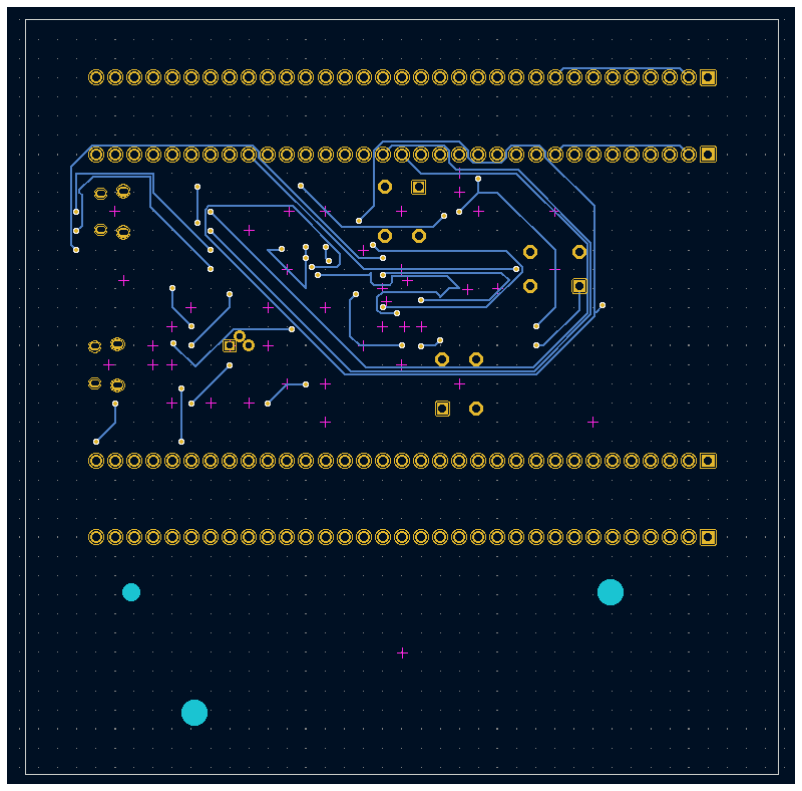
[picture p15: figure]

All back layers

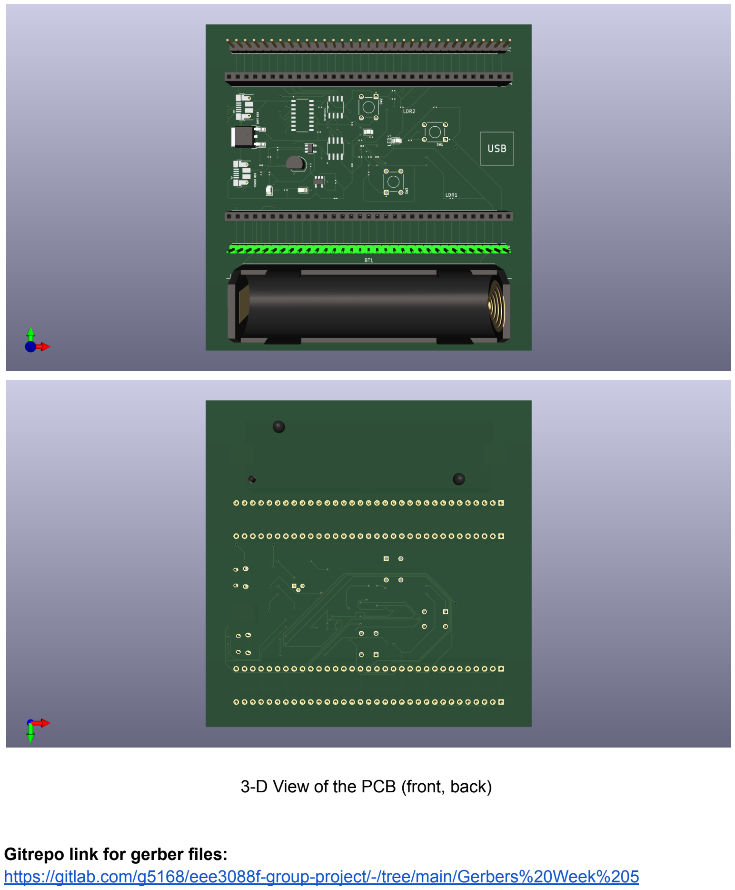
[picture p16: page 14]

3-D View of the PCB (front, back)

Gitrepo link for gerber files: https://gitlab.com/g5168/eee3088f-group-project/-/tree/main/Gerbers%20Week%205

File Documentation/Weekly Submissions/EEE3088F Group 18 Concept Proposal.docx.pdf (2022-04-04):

UNIVERSITY OF CAPE TOWN

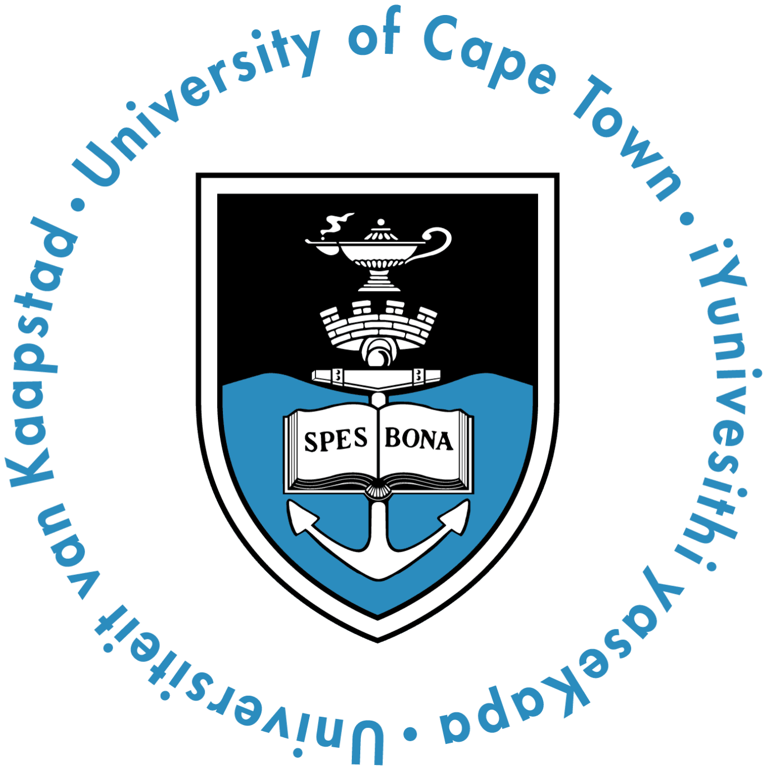
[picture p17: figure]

EEE3088F

CONCEPT PROPOSAL

FEBRUARY 2022

GROUP 18

JONATHAN APPS (APPJON001)

SHAMEERA CASSIM (CSSSHA020)

JAHAR PERSAD (PRSJAH002)

## 1. Environment Sensing HAT Concept

The HAT will be designed to operate a rotating frame which is intended to sense the direction in which the sunlight is brightest. The HAT will be programmed to rotate the frame, using 2 motors, to point its face in the direction of maximum brightness. This design is intended to be used to charge solar panels efficiently. A small solar panel would ideally be connected to the face of the frame thereby allowing for optimal sunlight to be provided to the panel at all times.

The HAT will be powered by the discovery board (STM32 series) and it will drive the operation of the rotating frame; it will thus be connected to both the discovery board and the frame.

This design could be implemented for energy projects. Those who desire efficient off-the-grid power generation could broadly replicate this design and adjust it depending on their requirements. It could also be the basis for complex light tracking systems and numerous home-automation designs.

## 2. Requirements

User Role/Scenario 1

The HAT could be scaled and used in an agricultural context. Often different plants require different amounts of sunlight and too much or too little sunlight can damage the plant. Further, temperature can also have an effect on the wellness of plants (while the system does not necessarily track temperature, the amount of sunlight can correlate to temperature and can be used in conjunction with other information to extrapolate whether any action should be taken). Thus, tracking the amount of sunlight the plant is receiving can be useful. This would allow someone to move plants if they feel the environment is not suitable or could cover plants/windows to provide shade or reduce temperature where necessary.

- R1.1: Suitable interfacing so that the HAT either triggers shading mechanisms and/or alerts the person responsible when a change needs to be made for plant health.
- R1.2: A suitable space for the system to be set up so that it is not shaded by the plant but is also receiving the same amount of sunlight as the plant.
- R1.3: The system needs to be weather-proof and sturdy for outside use.

User Role/Scenario 2

The HAT could be used to generate power for a home. Those in rural areas that lack either the infrastructure or finances to be connected to the power grid could use this HAT system to generate power efficiently. Homes in urban areas could likewise use the system for power generation purposes. Modifications would clearly need to be made to the system depending on the exact usage conditions.

- R2.1: A suitable place to install the solar panels and the (modified) HAT system.
- R2.2: Enough liquidity to be able to afford the initial system investment.
- R2.3: The infrastructure for the solar panels. This includes setting up the electrical side of things to ensure that the user benefits from the system.

User Role/Scenario 3

The HAT design could be scaled for powering shopping centres or other commercial spaces. Specifically in South Africa, where the sun is available all year round, we should be making use of alternative power generation methods like solar panels wherever possible to alleviate some of the pressure on the energy crisis.These spaces could utilise mechanisms like the HAT to directionally track the sunlight and use solar panels for energy generation. This could also increase the effectiveness of energy generation for businesses (like a Makro who uses carport solar systems at some locations) with existing renewable energy systems.

- R3.1: A suitable environment for the solar panels and (modified) HAT system
- R3.2: The system must be weather-proof and sturdy for outside use.
- R3.3: The system must be set up alongside a connection to the national power grid or an alternative energy source. While solar panels are a reliable source of energy, there may be periods of time in which there is insufficient sunlight to generate the power required for operations.

Alternative User Roles

While we understand that this project is largely centred around the functional uses of the proposed HAT, we also recognize that it could be used to make products for hobbyists and for commercial sale. These uses include:

User Role/Scenario 4

The HAT could be used to estimate the time based on the position of the sun. This would require interfacing with another device to display the time (this could be a screen or a physical clock) as well as additional coding to determine the time based on the position of the sun.

- R4.1: Interfacing with an additional device to tell the time.
- R4.2: Additional capabilities to run code to extrapolate the time from the position of the sun.
- R4.3: Given that this would be used more as decoration and enjoyment, the HAT and the discovery board should be concealed to make the “clock” visually appealing.

User Role/Scenario 5

Sensor-controlled cars and robots are popular among hobbyists. The HAT could be used as a control mechanism for such projects. For example, it could be placed on top of a pre-built car or system on wheels that is programmed to move in the direction of a light. The HAT would essentially be used as part of a larger project. This would require additional interfacing and code depending on what the project it is being used for.

- R5.1: Ability and instructions to interface with other systems.
- R5.2: An additional power source would need to be used as it would not be practical to have to be connected to a power source via a wire for moving components.

- R5.3: The HAT and its power source would need to be encased to avoid damage and to allow for compatibility with the broader system. The bottom of this casing should have clips or an adhesive for easy attachment.

## 3. Project Subsystems Block Diagram

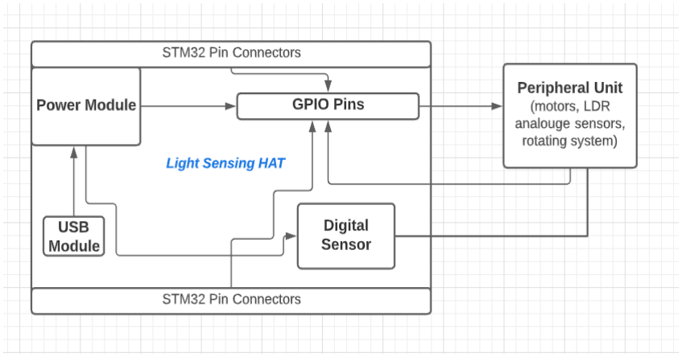
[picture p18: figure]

### 1. Power Module

Contains the following components:

- 18650 connector (DNP)
- Li-Ion battery charger
- Input voltage polarity protection
- Battery polarity protection
- Battery Under-voltage cutout protection

### 2. USB Module

Contains a USB micro connector port, an onboard FTDI, and has detect and input capabilities. Powers the power module and thus charges the batteries.

### 3. GPIO Pins

Contains pins that redirect GPIO capabilities from the STM32F051 to the HAT. These are connected to the development board via the STM32 pin connectors.

### 4. Digital Sensor

Temperature sensor included here. This monitors the temperature of the peripheral unit.

### 5. Peripheral Unit

Contains 2 DC motors which drive the rotation of the system. 4 LDR sensors will be included to monitor the direction of brightest sunlight. The system will likely be held together with a plastic/metal frame.

## 4. Link to Our Team’s Git Repository

GitHub link: https://github.com/ShameeraC4/EEE3088F-Group18

GitLab link: https://gitlab.com/g5168

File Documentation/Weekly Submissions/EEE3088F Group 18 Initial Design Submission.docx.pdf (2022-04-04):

UNIVERSITY OF CAPE TOWN


EEE3088F

Initial Design

MARCH 2022

GROUP 18

JONATHAN APPS (APPJON001)

SHAMEERA CASSIM (CSSSHA020)

JAHAR PERSAD (PRSJAH002)

## Git Repository

### 1. Github

Link to Git Repository: https://gitlab.com/g5168/eee3088f-group-project
See “Initial Design Assignment” for schematics and BOM relevant to this assignment.

## Failure Management

### 2. Power Subsystem Failure Management

I have decided to order extra components and add traces in parallel to where the original components should be but leave it as an open circuit. In the event of trace damage or a component malfunction, I can utilise these traces in parallel. I have chosen multiple components(for each component) that could work if jlcpcb are out of stock at the time of ordering, then I can just use one of the alternatives. If there is an error in my circuit that I only detect post manufacture, I can make use of the parallel traces that I made to alter the values of components or even design a new circuit, I would just have to sever some of the other traces to make this work.

### 3. Sensing Subsystem Failure Management

The sensing subsystem will provide additional traces to connect to through-holes that can be used in the case of trace/component destruction. Should a component fail or be destroyed, additional components can be soldered on the through-holes of the pcb. As in the power subsystem, the traces will be connected in parallel to where the original components were set. Additional components will likely be collected from other sources that can replace the ones used in the pcb, so that component replacements can be done when/where necessary. While there are no over-voltage/power preventing mechanisms in the sensing subsystem, the module is powered directly from the discovery board which has power/voltage regulators internally. Providing that the STM is operating properly, the sensing subsystem should be safe from failure.

### 4. Microcontroller Interfacing Failure Management

A diode is used to prevent surging to the USB mount from any external source the USB is connected to. Further, alternative EEPROM and FTDI chips have been considered and researched to ensure that in the event that the original component choices are unavailable at the time of PCB assembly, the schematics and gerbers can be updated for manufacturing. In the event that the AT24C256C-SSHL-T EEPROM is not available, there are M24C02-WMN6TP chips available which have the same amount of storage space and are also cheaper and will fit into the budget. In the case that the CH340C FTDI chip is unavailable, it is likely that the CH340G will be available. However, this chip would also require the addition of a clock as it has no integrated clock. There is also a decoupling capacitor to the input of the FTDI pin.

# Schematics

### 5. Power Subsystem Schematic

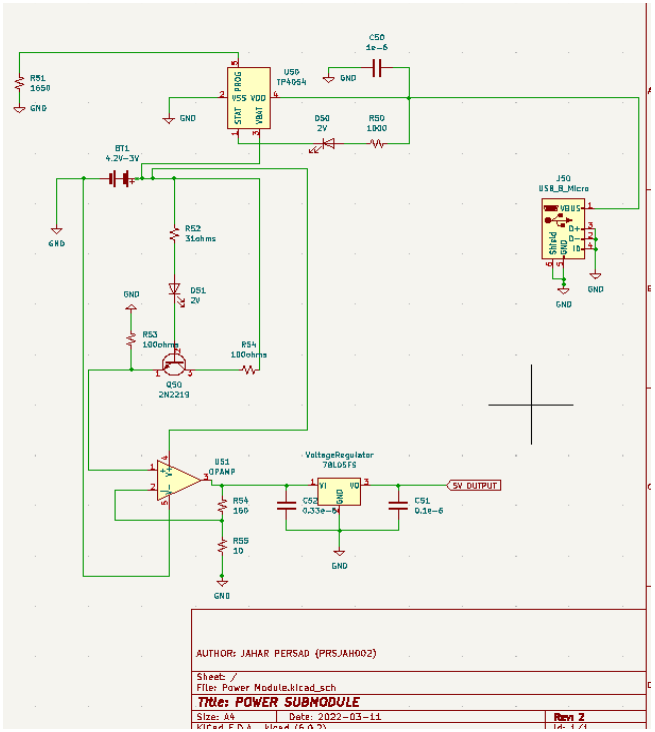
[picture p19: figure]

As you may have noticed, the power submodule circuit for this assignment is different from the last. This is because the last circuit did not have a method of charging the battery. I also changed the configuration of the voltage regulator as I decided to use a different part (voltage regulator part). The input to the power module also changed, it is now getting power from a usb input. The polarity protection is covered by the LED which only allows current to flow in one direction, And no current will flow if the battery voltage drops below 3V (which is the recommended discharge maximum), since the voltage at the base of the transistor will be equal to or less than 0.7V, therefore the voltage at the emitter will be 0V, so the output will be zero. In that way undervoltage lockout is also dealt with.

### 6. Sensing Subsystem Schematic

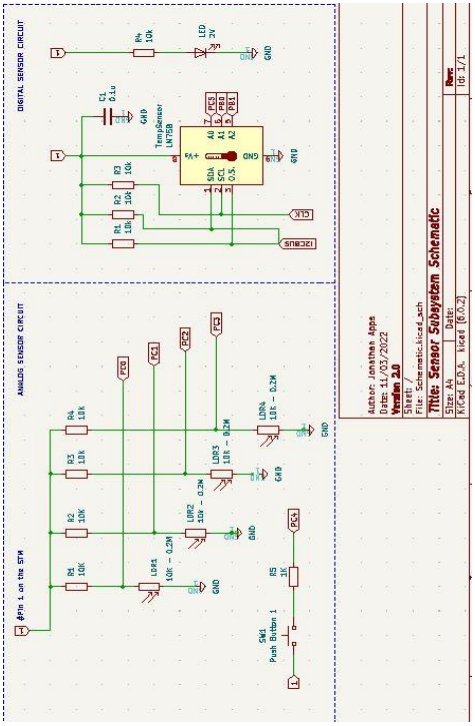
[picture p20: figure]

### 7. Microcontroller Interfacing Schematic

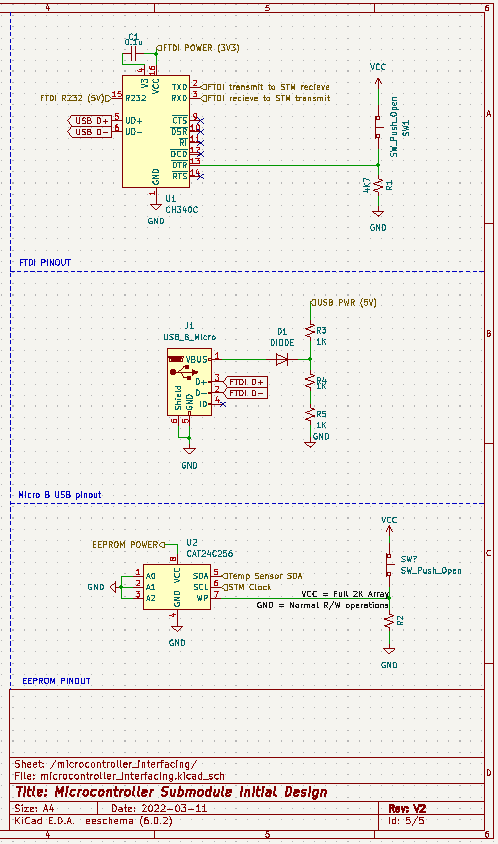
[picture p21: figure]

### 8. Planned ERCs

We plan to use KiCad’s internal ERC feature. There are additional Spice ERCs that could be useful, and thus these will be considered as well.

### 9. Updated BOM

A table of the BOM is included below for ease of reference and the generated version from KiCad is available in the git repository under the directory “Initial Design Assignment” in the zipfile ‘main’.

Unit | Description | Multiplier | Cost per unit ($) | Total Cost ($) | Notes
C404969 | Surface Mount Micro-B SMD USB Connector | 2 | 0,048 | 0,096
CH340C | FTDI
USB-to-UART
chip
1 | 0,7311 0,7311
M24128-BRMN6TP | EEPROM | 1 | 0,2052 | 0,2052
STM32F051 | Microcontroller chip & discovery kit
1 | 0 | 0 | (retained
from
EEE2046
F)
USB to microB cable | USB to microB cable
2 | 0 | 0 | (retained
from
EEE2046
F)
LM75BD | Temperature Sensor
1 | 0,5734 0,5734
BL-HUE35A-AV-TR E | Red LED | 1 | 0,0234 | 0,0234
RCT02300RFLF | 300Ω Resistor | 1 | 0,0028 0,0028

CT41G-0402-2X1-1
6V-0.1μF-K(N)

0.1uF
Capacitor
| | 1 | 0,0034 | 0,0034
RCT0310KJLF | 10KΩ Resistor | 7 | 0,0016 0,0112
GL48516 | Photoresistor | 4 | 0,0527 | 0,2108
C13828 | Push Button | 2 | 0,0382 0,0764
| Resistors | 7 | 0,0007 | 0,0049
BL-HUE35A-TRB | LED | 2 | 0,1305 0,261
TP4054 | Charger IC | 1 | 0,2523 | 0,2523
2n2222A | NPN transistor | 1 | 0,1736 0,1736
78L05FS | Voltage regulator | 1 | 0,21 | 0,21
Tlv316 | Opamp | 1 | 0,2 | 0,2
| Capacitors | 3 | 0,001 | 0,003

TOTAL (PER
BOARD)

3,0385

TOTAL (5
BOARDS)

15,1925

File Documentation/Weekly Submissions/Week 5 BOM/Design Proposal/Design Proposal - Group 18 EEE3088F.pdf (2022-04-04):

UNIVERSITY OF CAPE TOWN


EEE3088F

DESIGN PROPOSAL

MARCH 2022

GROUP 18

JONATHAN APPS (APPJON001)

SHAMEERA CASSIM (CSSSHA020)

JAHAR PERSAD (PRSJAH002)

## 1. Power Subsystem

### 1.1 Specification

This submodule must be able to receive 3-3.6V, and deliver 5 volts. It will contain the following components/circuits:

- A 18650 connector (DNP)
- A Li-Ion battery charger
- Input voltage polarity protection
- Battery polarity protection
- Battery Under-voltage cutout protection
- This module will provide an output of 5V, The current and power required havent yet been decided on, but these can easily be altered by using cheap analog components

In terms of the charger for the battery, we are still undecided as to how we wish to power it, but one of our ideas is to not power from the discovery board but from an external source, and then use this part/circuit.

https://datasheet.lcsc.com/lcsc/1809261820_TOPPOWER-Nanjing-Extension-Microelectronics-TP4056-42-ESOP8_C16581.pdf (https://datasheet.lcsc.com/lcsc/1809261820_TOPPOWER-Nanjing-Extension-Microelectronics-TP4056-42-ESOP8_C16581.pdf)

These are some of the components we are looking to use for this part of the circuit. In the next section there isn't a parts list as we haven't fully decided on the power rating, and how much current the other modules need at this point. The only point of looking at parts was to get an idea of prices.

PMOSFET:

https://datasheet.lcsc.com/lcsc/1810171817_Alpha---Omega-Semicon-AO3401A_C15127.pdf

Voltage Regulator:

https://datasheet.lcsc.com/lcsc/1810231832_Advanced-Monolithic-Systems-AMS1117-5-0_C6 187.pdf (https://datasheet.lcsc.com/lcsc/1810231832_Advanced-Monolithic-Systems-AMS1117-5-0_C6187.pdf)

LED:

https://datasheet.lcsc.com/lcsc/2006301912_TOGIALED-TJ-L3FYTGCGMCGLFLC2G-A5_C3 31056.pdf (https://datasheet.lcsc.com/lcsc/2006301912_TOGIALED-TJ-L3FYTGCGMCGLFLC2G-A5_C331056.pdf)

https://datasheet.lcsc.com/lcsc/2006301911_TOGIALED-TJ-L3FYTGCTCGSFLC2G-A5_C330 751.pdf (https://datasheet.lcsc.com/lcsc/2006301911_TOGIALED-TJ-L3FYTGCTCGSFLC2G-A5_C330751.pdf)

Resistors:

https://datasheet.lcsc.com/lcsc/2007151113_YAGEO-RC0402FR-0710R5L_C477603.pdf

https://datasheet.lcsc.com/lcsc/1810231425_YAGEO-RC0603FR-07100RL_C105588.pdf

https://datasheet.lcsc.com/lcsc/2110252130_UNI-ROYAL-Uniroyal-Elec-0603WAF332JT5E_C 23004.pdf (https://datasheet.lcsc.com/lcsc/2110252130_UNI-ROYAL-Uniroyal-Elec-0603WAF332JT5E_C23004.pdf)

https://datasheet.lcsc.com/lcsc/1810161313_HKR-Hong-Kong-Resistors-RCT0330R1FLF_C17 7931.pdf (https://datasheet.lcsc.com/lcsc/1810161313_HKR-Hong-Kong-Resistors-RCT0330R1FLF_C177931.pdf)

https://datasheet.lcsc.com/lcsc/1810241340_YAGEO-AC0402JR-0750RL_C227387.pdf

https://datasheet.lcsc.com/lcsc/1810241325_YAGEO-AC0402FR-0760R4L_C144744.pdf

NOT Gate:

https://datasheet.lcsc.com/lcsc/1809172025_Texas-Instruments-SN74HC14PWR_C6821.pdf

### 1.2 Bill Of Materials (BOM)

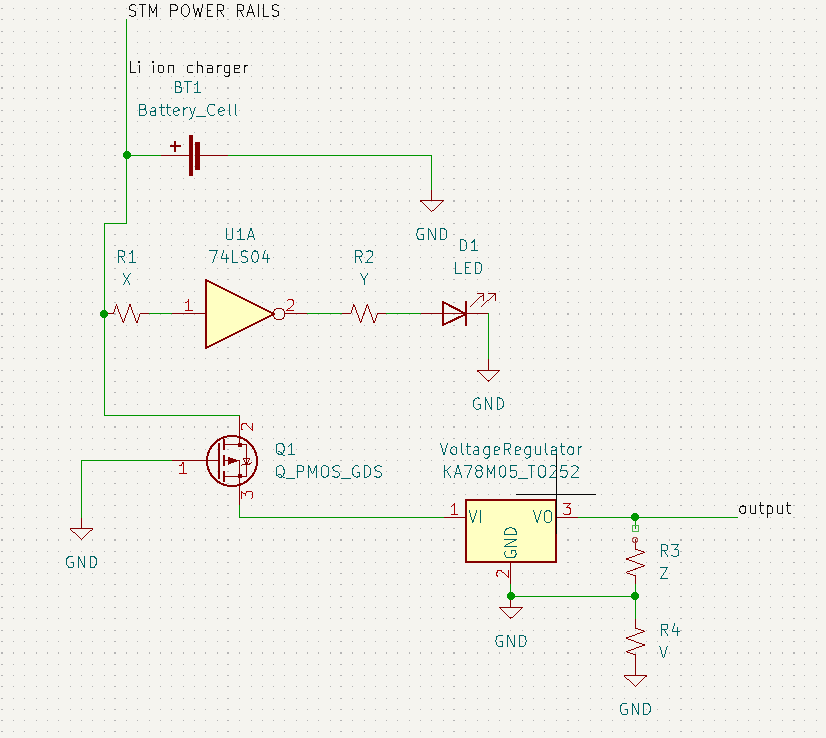
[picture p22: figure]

Figure 1: Power Module Schematic

The estimated cost of this circuit excluding the battery is 1.2$. The reason that parts weren't chosen from JLCPCB yet is that the availability of the parts will change as time passes, so an approximate cost for each part was taken from JLCPCB just to give us an idea of the cost. The battery that we are using (18650 LIPO battery) did not appear on JLCPCBs library so we excluded it from the approximate cost for now.

https://gitlab.com/g5168/eee3088f-group-project/-/blob/main/Design%20Proposal%20Assignment/Bill_Of_Materials_Power_Submodule.xlsx (https://gitlab.com/g5168/eee3088f-group-project/-/blob/main/Design%20Proposal%20Assignment/Bill_Of_Materials_Power_Submodule.xlsx)

Q1.3 Define this submodule’s interface(s) [10]

The power module is responsible for powering the microcontroller. It ensures that the correct voltage is sent to the microcontroller. The power module is protected against reverse polarity via the PMOSFET, it ensures that if the user puts the battery in the wrong way or something that current won't flow to the microcontroller, and an LED will be switched on to notify the user. The voltage regulator is the part of the power module that ensures that the required voltage is sent to the microcontroller. The power module also indirectly powers the HAT via the microcontroller.

## 2. Microcontroller interfacing

Q2.1 Specification [10]

Item | Requirement | Specification | Additional Notes and Documentation Links
| Memory
M1a | Key configuration data must be kept in a non-volatile medium and data from the temperature sensor must be time-stamped and stored alongside this throughout the operational period | EEPROM needs to be used to store configuration data and to read in and store data from the temperature sensor. The M24128-BRMN6TP is a 128Kb chip which is compatible and costs $0.2052. The 64Kb M24C64-RMN6TP and the 2Kb M24C02-WMN6TP chip cost $0.2029 and $0.1355 respectively per component.
M1b | | Pins PF6 and PF7 on the discovery board are used for I2C to connect the EEPROM.
| Clock
C1 | Measure at a minimum of 1/60 Hz which is required to be soft-configurable. | The STM32F051’s internal RTC will be used.
| USB
U1a | On USB plug-in event | A C404969 Surface Mount Micro-B SMD USB Connector that costs $0.048 is needed so that a Micro-B USB can be used. | Datasheet: https://datasheet.lcsc.com/lcsc/1912111437_SHOU-HAN-MicroXNJ_C404969.pdf (https://datasheet.lcsc.com/lcsc/1912111437_SHOU-HAN-MicroXNJ_C404969.pdf)

Datasheets:
https://datasheet.lcsc.com/lcsc/1809061818_STMicroelectronics-M24C02-WMN6TP_C7
562.pdf (https://datasheet.lcsc.com/lcsc/1809061818_STMicroelectronics-M24C02-WMN6TP_C7562.pdf)

Here it is important to note that there have been huge
fluctuations of both price and stock over the week so
multiple options have been listed but a final decision will
be | made | based | on
availability, | price | and
required usage once the
memory required to be
stored | is | more | clear.
However, the 128Kb chip is preferred as it likely has enough memory and has a
small | price | increase
compared to the 64Kb chip, it does not have large stock
currently available and an alternative may be required.

U1b | | A USB-MicroB cable is needed to connect the microcontroller to the HAT. | These may be reused from the equipment given out for EEE2046F.
U2a | Data captured by the temperature sensor should be written to EEPROM. | Pins PA2 and PA3 on the microcontroller are required for the FTDI chip. | The data needs to be transferred from the sensor to a FTDI chip via USB to be “translated” into USART which is then written to the external EEPROM in the form of an array. CH340C Datasheet: https://www.mpja.com/download/35227cpdata.pdf (https://www.mpja.com/download/35227cpdata.pdf)
U2b | | A CH340C chip can be used to interface between the sensor and memory. The chip “translates” the data from USB to USART. This chip costs $0.7311 and has a built-in clock generator so requires no external crystal source.
| Pin Interfacing
PI1 | Analog Sensors(LDRs) should output to the microcontroller | 9 GPIO pins need to be made available for the analog sensing unit. These should be configured in analog input mode.
PI2 | The microcontroller must receive power from a power module powered by a Li ion battery. | A 5V-tolerant GPIO pin on the STM32F051 Discovery Board must be used as a power input. | https://www.st.com/content/ccc/resource/technical/document/application_note/group0/13/c0/f6/6c/29/3b/47/b3/DM00315319/files/DM00315319.pdf/jcr:content/translations/e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. DM00315319.pdf (https://www.st.com/content/ccc/resource/technical/document/application_note/group0/13/c0/f6/6c/29/3b/47/b3/DM00315319/files/DM00315319.pdf/jcr:content/transla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) (section 5.2)
PI3 | The microcontroller must output 5V to HAT. | The 5V pin needs to be available to output 5V to the HAT to charge the battery.

Q2.2 Draft Bill Of Materials (BOM) [10]

- Link to spreadsheet in gitlab:

https://gitlab.com/g5168/eee3088f-group-project/-/blob/main/Design%20Proposal%20Assignment/Draft_Bill_Of_Materials_Microcontroller_Submodule.xlsx (https://gitlab.com/g5168/eee3088f-group-project/-/blob/main/Design%20Proposal%20Assignment/Draft_Bill_Of_Materials_Microcontroller_Submodule.xlsx)

- Component cost:

A single board costs $0,9843 and hence, the total cost for the 5 boards is $4,9215.

- Screenshot of draft schematic:

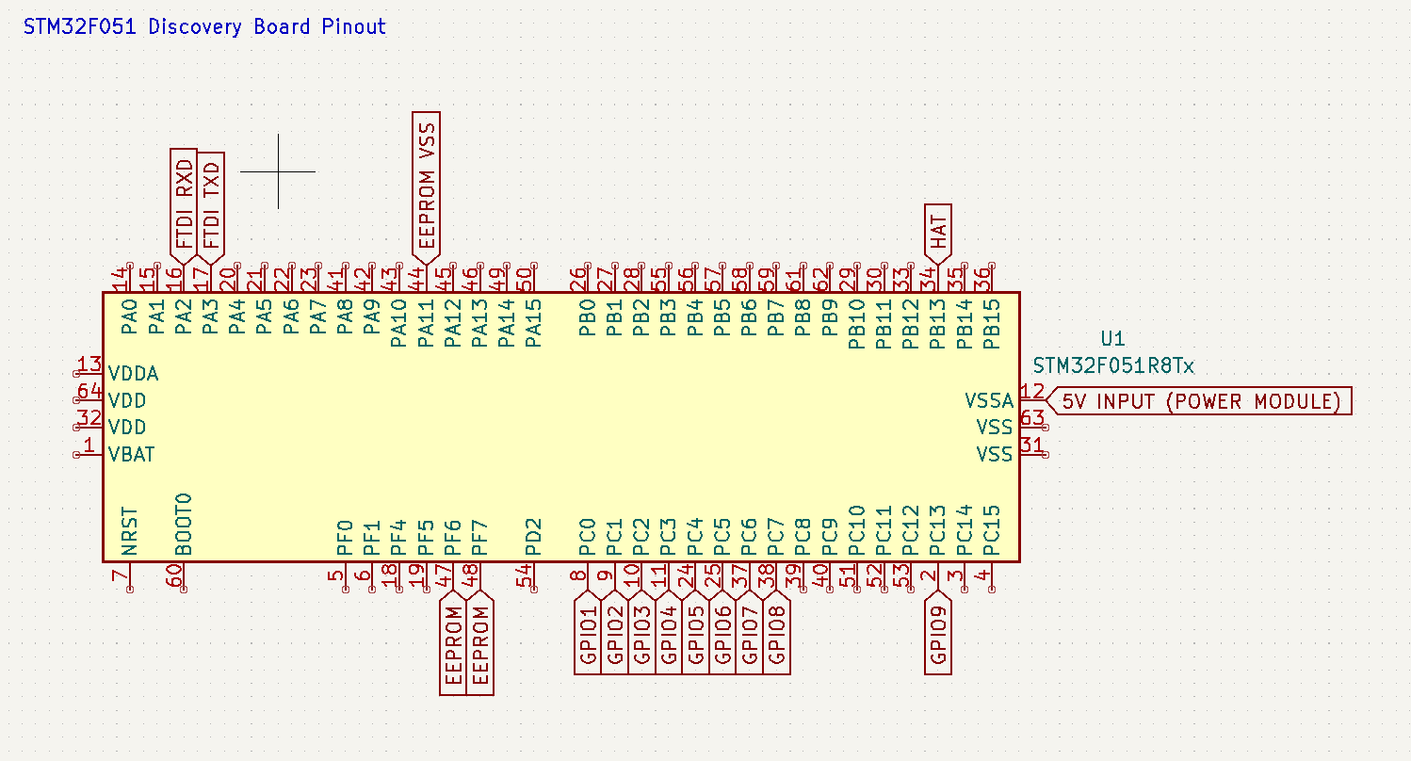
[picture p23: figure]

Figure 2: STM32F051 Microcontroller Module Pinouts

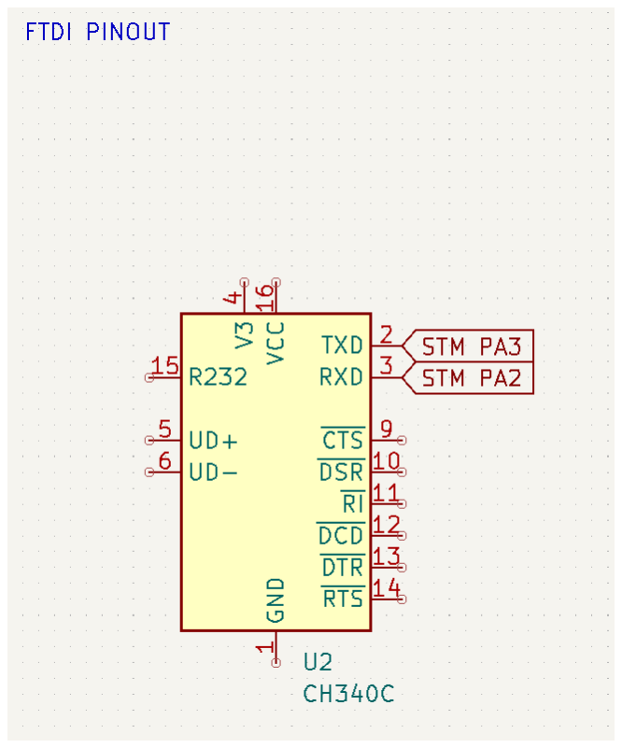
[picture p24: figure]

Figure 3: FTDI Microcontroller Module Pinouts


Figure 4: EEPROM Microcontroller Module Pinouts

Q2.3 Define this submodule’s interface(s) [10]

Interface | Description
Power Module | The power module is responsible for powering the microcontroller. These 2 submodules are interfaced via a 5V-tolerant GPIO pin.
HAT power supply | The microcontroller is responsible for providing power to the HAT. The HAT and the microcontroller are interfaced via the 5V output pin.
Analog Sensors | The 4 LDRs on the HAT as well as the 4 LDRs on the peripheral device are interfaced with the microcontroller via GPIO pins.
Digital Sensor | The digital temperature sensor is interfaced with the microcontroller module via the USB connection to the FTDI chip.
LED on microcontroller | Red LED LD1 (PWR) and LD2 (COM) light up and green LED LD3 blinks to indicate the microcontroller is powered on.

## 3. Sensing Subsystem

Q3.1 Specification

### 3.1.1 Digital Sensor Specification

Item | Specifications | Additional Notes | Datasheet Links
1 | One LM75BD Temperature sensor is required. | This operates at 2.8V - 5.5V, and as such is perfect for the HAT as a digital sensor. Further operating conditions can be found in the attached datasheet. | https://datasheet.lcsc.com/lc sc/2110111830_UMW-Youtai -Semiconductor-Co---Ltd--L M75BD_C725792.pdf (https://datasheet.lcsc.com/lcsc/2110111830_UMW-Youtai-Semiconductor-Co---Ltd--LM75BD_C725792.pdf)
2 | One red LED (BL-HUE35A-AV-TRE) to indicate that the temperature is outside optimal functioning conditions. | This will be connected to a pin which reads the LM75. The temperature data register will be polled to ensure that when the temperature exceeds a specified limit, the LED is lit up. | https://datasheet.lcsc.com/sz lcsc/1809192334_BrtLed-Bri ght-LED-Elec-BL-HUE35A-A V-TRE_C138549.pdf (https://datasheet.lcsc.com/szlcsc/1809192334_BrtLed-Bright-LED-Elec-BL-HUE35A-AV-TRE_C138549.pdf)
3 | 20mA of forward current through the LED must not be exceeded. | Put a resistor in place to ensure correct operation (see Item 4). | N/A
4 | Items 2 and 3 necessitate the use of a 300Ω resistor. The | Performing a KVL analysis on a 5V power supply in series with a 300Ω resistor (with a forward voltage drop of 3V) and a 2V LED, shows that the current through the LED will be: I = V/R = 3/300 = 10mA. This is a correct operating current for the LED. | https://datasheet.lcsc.com/lcsc/1810162030_HKR-Hong-Kong-Resistors-RCT02300RFLF_C173569.pdf (https://datasheet.lcsc.com/lcsc/1810162030_HKR-Hong-Kong-Resistors-RCT02300RFLF_C173569.pdf)

RCT02300RFLF seems to be
perfect for this use case.

5 One CT41G-0402-2X1-16V-0.1μF-K(

N) capacitor, to decouple the
| signal at the Vcc pin.

This adds safety from undesirable noise signals.

https://datasheet.lcsc.com/lcsc/1809291518_TORCH-CT
41G-0402-2X1-16V-0-1-F-K-N_C141382.pdf (https://datasheet.lcsc.com/lcsc/1809291518_TORCH-CT41G-0402-2X1-16V-0-1-F-K-N_C141382.pdf)

6 Three RCT0310KJLF 0.1W, 10KΩ resistors are required. No more than 0.1W can be dissipated by each resistor.

These act as pull-ups for the temperature sensors. Pull-up resistors are necessary for this temperature circuit configuration at the bus output and the interrupt line.

https://datasheet.lcsc.com/lcsc/1810161330_HKR-Hong-Kong-Resistors-RCT0310KJ
LF_C177337.pdf (https://datasheet.lcsc.com/lcsc/1810161330_HKR-Hong-Kong-Resistors-RCT0310KJLF_C177337.pdf)

### 3.1.2 Analog Sensor Specification

Item | Specifications | Additional Notes | Datasheet Links
1 | The HAT requires four GL48516 photoresistors (LDRs). | These assume values of 5-10 KΩ at 10 LUX, and approximately 0.2 MΩ in the dark. | https://datasheet.lcsc.com/lcsc/2009121137_JCHL-Shen zhen-Jing-Chuang-He-Li-Tec h-GL48516_C779572.pdf (https://datasheet.lcsc.com/lcsc/2009121137_JCHL-Shenzhen-Jing-Chuang-He-Li-Tech-GL48516_C779572.pdf)
2 | Four RCT0310KJLF 0.1W, 10KΩ resistors are required. No more than 0.1W can be dissipated by each resistor.

These will be placed in series with the LDRs in 4 separate voltage divider configurations.

https://datasheet.lcsc.com/lcsc/1810161330_HKR-Hong-Kong-Resistors-RCT0310KJ
LF_C177337.pdf (https://datasheet.lcsc.com/lcsc/1810161330_HKR-Hong-Kong-Resistors-RCT0310KJLF_C177337.pdf)

3 One C13828 push-button is required. It operates at ≤ 12VDC and ≤ 50mA.

This will be used to toggle the control of the rotation of the peripheral device from the photoresistors on the HAT to those on the peripheral unit.

https://datasheet.lcsc.com/szlcsc/1912111437_Dongguan
-Guangzhu-Industrial-C1382 8_C13828.pdf (https://datasheet.lcsc.com/szlcsc/1912111437_Dongguan-Guangzhu-Industrial-C13828_C13828.pdf)
4 | The photoresistors cannot be placed very closely together on the final HAT pcb. | The four photoresistors on the HAT and on the peripheral unit need to be separated using plastic slats, to separate the LUX reading on each. They thus cannot be placed too closely together. | N/A
5 | The outputs from the voltage divider configurations must operate between 2.4V and 3.6V. | GPIO pins in analog mode operate between 2.4V and 3.6V. ADC pins will likely be needed when the software is implemented. | N/A
6 | Item 5 implies that the input voltage should lie at around 5V. Thus the input voltage to the photoresistor voltage divider configuration should be connected to the STM32F0’s 5V pin. | This is very important for the pcb’s dimensions and tracks. | N/A
7 | There need to be connectors on the HAT to interface with the photoresistors/resistors on the peripheral module. Connectors should include +5V pins, and 4 GPIO pins with uninterrupted ADC capabilities. | The peripheral module is not part of the HAT system directly, but it should be allowed to operate via the pins on the HAT that can be connected to. | N/A

### 3.2 Draft Bill Of Materials (BOM)

- Link to spreadsheet in gitlab:

https://gitlab.com/g5168/eee3088f-group-project/-/blob/main/Design%20Proposal%20Assignment/Draft_Bill_of_Materials__Sensing_Submodule.xlsx (https://gitlab.com/g5168/eee3088f-group-project/-/blob/main/Design%20Proposal%20Assignment/Draft_Bill_of_Materials__Sensing_Submodule.xlsx)

- Component cost:

A single board costs $0.8632 and hence, the total cost for the 5 boards is $4.316.

- Screenshot of draft schematic:


Figure 5: Digital Sensor Schematic


Figure 6: Analog Sensor Schematic

### 3.3. Sensor Submodule Interfaces

### 3.3.1 Digital Sensor Interface

Microcontroller Interface:

The temperature sensor will need to closely interact with the microcontroller, since the sensor runs off an external CLK signal. The sensor also sends data via an I^2*C BUS. The BUS will transmit data to the HAT’s memory module, which will then send the data via the HAT’s USB module to the STM32 microcontroller. The temperature sensor will thus interact with the memory on board the hat, as well as the input and output pins (GPIO) on the STM32.

Power Interface:

The sensors will also interface with the power module, via the discovery board. The batteries will power the discovery board which will provide GPIO pins and microcontroller interface abilities to the HAT. The power module is thus crucial in the operation of the HAT.

### 3.3.2 Analog Sensor Interface

The analog sensors - the photoresistors - will interface with the following submodules:

Microcontroller Interface:

The photoresistors will be connected to the GPIO pins of the STM32, and to its 5V pin, as shown in the schematic (Figure 6) above. The pushbutton will also interface with the microcontroller on board the STM32 as its state will control whether the photoresistors are reading data from the peripheral device or from the HAT. This requires interfacing with 9 GPIO pins on the microcontroller and 1 power pin.

Power Interface:

The photoresistors and the push-button will operate from the discovery board which will be powered by the batteries on board the HAT (in the usual case). The power module will not directly interface with the sensors, but it will enable the functioning of this module.

Peripheral Unit Interface:

The exact schematic in Figure 6 will be replicated for the peripheral device. The operation of this unit will rely on the microcontroller and power submodules in precisely the same way as the on board photoresistors do. The photoresistors and circuitry connected to the peripheral device will only be activated if the pushbutton is in the correct state (every push of the pushbutton will change the mode of operation from HAT-controlled to Peripheral-controlled, and vice versa). Both the sensors on the HAT and the peripheral device will control the rotating frame (this is part of the peripheral device), one at a time of course (depending on the users preference).

ASSEMBLY COSTS/TOTAL COST

24 SMT components x 0.0017= $0.0408
4 hand soldered components= 3.5x4 =$14
4 extended parts [ once off fee] = $12

Therefore the total cost of manufacturing one board: $29.0883
Therefore the total cost of manufacturing 5 boards: $97.4415
[This is excluding the actual cost of the pcb, we didn't include this cost because we have not decided on a size or colour yet]

https://gitlab.com/g5168/eee3088f-group-project/-/blob/main/Design%20Proposal%20Assignment/Draft_ASSEMBLY_COSTS.xlsx (https://gitlab.com/g5168/eee3088f-group-project/-/blob/main/Design%20Proposal%20Assignment/Draft_ASSEMBLY_COSTS.xlsx)

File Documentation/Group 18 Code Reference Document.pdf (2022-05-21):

## Group 18 Code Reference Document

The following functions are used in the firmware for Group 18’s HAT. Please note that the bulk of this code is taken from the Coding Help slides by Jane Wyngaard[1]:

Function name | debugPrintln
Function description | General purpose Function to send a char array over the UART and to automatically send a new line character after it
Parameters | uart_handle: pointer to a UART_HandleTypeDef structure that contains the configuration information for the UART being used _out[ ] : array of characters to be sent
Return values | None
Function name | demoDataTransfer
Function description | Demonstration of sending data over UART to laptop. “Hello, this is STMF0 Discovery board” should be printed to the laptop and the blue LED should be flashed once this is completed
Parameters | None
Return values | None
Function name | checkAddress
Function description | This function checks that the correct address has been chosen
Parameters | huart: pointer to a UART_HandleTypeDef structure that contains the configuration information for the UART being used All other parameters are used to call the HAL_I2C_IsDeviceReady function. Thus, the following is copied from the HAL reference sheet[2]: hi2c: Pointer to a I2C_HandleTypeDef structure that contains the configuration information for the specified I2C. DevAddress: Target device address: The device 7 bits address value in datasheet must be shift at right before call interface Trials: Number of trials Timeout: Timeout duration
Return values | None
Function name | writeToI2C
Function description | This function is used to read data from the EEPROM
Parameters | EEPROM_DEVICE_ADDR: pointer to the address of the EEPROM device on the I2C bus madd: starting memory address for the location of memory to read from Data: starting value of data to write to memory
Return values | None
Function name | readToI2C

Function description | This function is used to write data to the EEPROM
Parameters | EEPROM_DEVICE_ADDR: pointer to the address of the EEPROM device on the I2C bus madd: starting memory address for the location of memory to read from Result: address of stored value to read back from memory in
Return values | None
Function name | lightSensingInit
Function description | Blink 2 LEDs based on the output of the LDRs from the HAT
Parameters | None
Return values | None
[1] J. Wyngaard, Coding Help. 2022, pp. 1-16.
[2] STMicroelectronics, Description of STM32F0 HAL and low-layer drivers. STMicroelectronics, 2022, pp. 217-218.

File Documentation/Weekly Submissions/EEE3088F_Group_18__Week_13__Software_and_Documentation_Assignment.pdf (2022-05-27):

### UNIVERSITY OF CAPE TOWN


### EEE3088F

### SOFTWARE AND DOCUMENTATION ASSIGNMENT

### MAY, 2022

### GROUP 18

### JONATHAN APPS (APPJON001)

### SHAMEERA CASSIM (CSSSHA020)

### JAHAR PERSAD (PRSJAH002)

### SECTION 1: SOFTWARE

### 1.1. Code Structure


### Figure 1: Code Basic Structure

### The basic structure of the code for the HAT is outlined in the block diagram above. A

simple set of functions initialize the different modules needed in the code (labeled “unit

initializations” in the diagram above). The main method calls the functions when necessary, as it runs the main logic of the program. The lightSensinginit() function is a one that can be run to display the light sensing functionality of the LDRs on board the HAT. All the other functions deal with data transfer from the HAT to the STM and vice

versa.

### 1.2. Code Reference

### Link: https://gitlab.com/g5168/eee3088f-group-18-project/-/blob/main/README.md

## Group 18 Code Reference Document

The following functions are used in the firmware for Group 18’s HAT. Please note that the bulk of this code is taken from the Coding Help slides by Jane Wyngaard [1]:

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

Function description | This function is used to read data from the EEPROM
Parameters | EEPROM_DEVICE_ADDR: pointer to the address of the EEPROM device on the I2C bus madd: starting memory address for the location of memory to read from Data: starting value of data to write to memory
Return values | None
Function name | readToI2C
Function description | This function is used to write data to the EEPROM
Parameters | EEPROM_DEVICE_ADDR: pointer to the address of the EEPROM device on the I2C bus madd: starting memory address for the location of memory to read from Result: address of stored value to read back from memory in
Return values | None
Function name | lightSensingInit
Function description | Blink 2 LEDs based on the output of the LDRs from the HAT
Parameters | None
Return values | None
[1] J. Wyngaard, Coding Help. 2022, pp. 1-16.
[2] STMicroelectronics, Description of STM32F0 HAL and low-layer drivers. STMicroelectronics, 2022, pp. 217-218.

### SECTION 2: LEARNING DOCUMENTATION

### 2.1. PCB Getting Started README

### Link: https://gitlab.com/g5168/eee3088f-group-18-project/-/blob/main/README.md

## EEE3088F Group 18 Sensing HAT (Version 1.0)

This project is a group project for the course EEE3088F at UCT. The purpose of the HAT is to detect light and move a motor or another device in the direction of the light.

## Instructions For Use (For Version 1.0)

### - Hardware Requirements -

To use this HAT, a mini-USB connector is required to interface the HAT with the STM (Or whatever other microcontroller is in use).The USB must be capable of data transmission. That being said, an STM32F0 discovery board, or another board containing a microcontroller with read/write/ADC/memory capabilities must be used if the full functionality of the HAT is to be claimed. The USB must be capable of data transmission.

A 5V Li-Ion battery and battery holder are necessary for the powering of the HAT, unless some other power source is to be used. Jumper cables are necessary for the current design, as it does not conform to the general standard of board measurements (the wires are needed to connect the HAT to the board in use).

### - Software Requirements -

The coding of this board can be done via the STM Cube IDE (preferred) or Code Blocks. Other coding platforms can work as well. The terminal must be configured to drive the USB ports that connect to the discovery board or the HAT.

Programs can be uploaded to the STM or to the HAT itself, depending on which method is preferred.

The EEPROM on the HAT must be coded via the HAT's USB port, as this sends data to and from the FTDI and the EEPROM on board the HAT together.

Currently the HAT has not been revised, and secondary versions have not yet been created. Because of this, the recommended approach to coding is to do so via the STM or the board in use (and not via the HAT).

The temperature sensor which sends data to and from the HAT's EEPROM was not populated in version 1.0, and as such the EEPROM and the FTDI on board the HAT are not needed or useful currently.

Thus, any code that is written should be uploaded directly to the board in use, after which wiring can interface the board with the HAT.

### - Initialization Instructions -

To initialize the hardware, connect the battery to the HAT to power the STM board (if batteries are not being used, find another way to connect the HAT to power). Connect each pin on the STM to the corresponding pin on the HAT via jumper wires.

To initialize the software, connect to the board via a USB, and compile and upload the desired code to the board via an appropriate IDE. How to upload code to the board will vary from IDE to IDE. Check the IDE's online documentation for further details.

### - Running Your First Program on the HAT -

To run your first program on the HAT, refer to the self-explanatory code in the "main.c" file in the following directory:

"Firmware/GROUP18 Microcontroller Interfacing/Core/src/main.c"

This file can be run to toggle two user connected LEDs based on the strength of light sensed by the LDRs on the HAT. To set up the hardware for this basic program, two LEDs should be connected in series with 1k resistors which will be connected to GPIOA and GPIOB on the STM (GPIO pin 10 and pin 12 respectively).

Alternatively, the LEDs on the STM can be flashed based on the state of the LDRs if the STM LEDs are set to "HIGH" in the lightSensingInit() function (this would need to be added). Inside of the while loop in the code, the first statement is a call to initialize the light sensing sequence, and so everything is set up for ease of use.

Have fun!!

### 2.2. CONTRIBUTING How-To Guide

Contribute To Group 18’s HAT

DESIGNERS:

Shameera Cassim (CSSSHA020@myuct.ac.za)

Jonathan Apps (APPJON001@myuct.ac.za)

Jahar Persad (PRSJAH002@myuct.ac.za)

All contributions to this project are welcome, however, the guide below must be read and adhered to.

- How To Contribute

First, email one of the designers ( Shameera Cassim, Jonathan Apps or Jahar Persad), detailing what is wished to change/contribute. Once approval has been received from one of the designers, submit a pull request. A branch will be created in GitLab where contributions and changes can be worked on,once the changes/contributions are complete, submit a merge request and the contributions will be evaluated and either used or discarded.

- Finding Issues (Repository, Documentation, PCB)

If issues are found in the GitLab repository, be it to do with the PCB, Documentation or even just the way the repository is structured, please raise an issue on GitLab or email one of the designers so that they can take a look at the problem.

- Extending Repository, Contributing to the PCB/Code

When contributing to the repository, please ensure that all contributions are in well-written English, that is in a well set out document format.

When contributing to the PCB, onlyKiCAD software may be used, alongside KiCADs standard library. If there is a footprint or anything that is missing from the KiCAD library, please seek approval by emailing one of the designers, detailing what you would like to use and from which library you will use it from.

When contributing to the code please ensure that it is well commented and follows the same format that the original code was written in. The code compiler/editer that must be used is STM32CubeIDE.

- Lastly, ensure that all changes are well documented and easy to understand.

### The GitLab repository link: https://gitlab.com/g5168/eee3088f-group-18-project/-/blob/main/Documentation/CONTR

IBUTING_HOW-TO_GUIDE.pdf (https://gitlab.com/g5168/eee3088f-group-18-project/-/blob/main/Documentation/CONTRIBUTING_HOW-TO_GUIDE.pdf)

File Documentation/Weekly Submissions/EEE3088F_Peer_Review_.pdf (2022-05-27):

UNIVERSITY OF CAPE TOWN


EEE3088F

PEER REVIEW OF GROUP 19’S PCB DISCOVERY HAT

MARCH 2022

GROUP 18

JONATHAN APPS (APPJON001)

SHAMEERA CASSIM (CSSSHA020)

JAHAR PERSAD (PRSJAH002)

### 1. Adherence to Mr. Pead’s Basic Requirements

Unacceptable 1 | Ok attempt 2 | Reasonable 3 | Good 4 | Excellent 5
| | | 4.8

Comment:

Requirement | Met?
1. (at least) 1x digital sensor (some communication port) | Yes
2. (at least) 1x analog sensor (ADC input) | Yes
3. An 18650 connector (Do Not Populate - Link provided on Padlet) | Yes
4. A Li-Ion battery charger | Yes
5. Input voltage polarity protection | Yes
6. Battery polarity protection | Yes

7. Battery Under-voltage cutout protection | Yes
8. (Soft requirement) Modularity between perceived elements to allow for bypassing to ensure you meet partial mark requirements in the event of module failure. | Yes, the 3 modules are connected by a single wire and can be disconnected. They also have several 0 ohm resistors.
9. USB micro connector, detect and input and have an onboard FTDI -USB connector LCSC number provided on Padlet | Yes
10. Working in teams of 3 each team will have a budget of R1500 for all components, manufacture, assembly and shipping. Currently, this is approximately $100 (useful to think in USD as the part prices are listed in such) | The BOM appears to be accurate and the team comes in under budget for the total including extended parts. It was assumed that the $24 for the extended parts is not included in the $26.999 for the 5 boards and that assembly costs will be added at a later stage.

(costs of assembling SMT parts need to be added).

11. Each team member must take the lead in 1 submodule:
- Power management
- Microcontroller interfacing
- Sensing

Yes

Comment: The team has met the requirements well and their documentation is good.

2. ￼Adherence to Mr Pead’s Debugger Requirements
Unacceptable 1 | Ok attempt 2 | Reasonable 3 | Good 4 | Excellent 5
| | | 4.6

Comment:

Requirement | Met?
1. Input 5V - This is to provide high level power to your board. | No test point
2. Analog Data - This is to both see what your sensor outputs and to push a signal into your board. If we are to push an analog voltage you need to ensure we don't destroy your sensor (So maybe a jumper to disconnect) | Yes
3. Depending on what digital communication port you chose, I allowed for 4 pins. | Yes
4. Plug Detect is your USB detect line - which we can control and monitor to change your devices operation | Yes

5. The data the device is sending out. (will need to disconnect the FTDI -Think Jumpers) | Yes
6. GND | Yes

### 3. Schematic

Unacceptable 1 | Ok attempt 2 | Reasonable 3 | Good 4 | Excellent 5
| | | | 5

Comment:

The schematic was well laid out and had clear explanations for each part of each submodule. It’s easy to follow and very well labeled.

### 4. PCB Layout

Is the PCB neatly laid out, does it appear care has been taken regarding trace location, routing, and thickness?

Unacceptable 1 | Ok attempt 2 | Reasonable 3 | Good 4 | Excellent 5
| | | 4.5

Comment:

Overall, the pcb looks good. There are long traces that could be shortened. Shortening the traces would have provided the design with enhanced predictability, since power losses are minimized with short traces. It is clear that the thickness of the tracks have been considered, and that the routing is done in such a way as to simplify the HAT layout.

### 5. Silk Screen

Unacceptable 1 | Ok attempt 2 | Reasonable 3 | Good 4 | Excellent 5
| | 3

Comment:

There is a silkscreen that would make an engineer’s life easier, since it includes annotation of components and test points that can be compared to the schematic. However, it will not be very useful for a user without technical knowledge of the circuit. A few of the labels are also underneath traces which will be an issue.

### 6. Low Voltage Protection Circuit

Unacceptable 1 | Ok attempt 2 | Reasonable 3 | Good 4 | Excellent 5
| | | | 5

Comment:

Nicely done!

### 7. Physical Board Design

Unacceptable 1 | Ok attempt 2 | Reasonable 3 | Good 4 | Excellent 5
| | | 4

Comment:

Space could’ve been used more efficiently!

### 8. Test Points and Recovery Approaches

Unacceptable 1 | Ok attempt 2 | Reasonable 3 | Good 4 | Excellent 5
| | | 4.8

Comment:

There are sufficient test points which give access to important parts of the circuit for debugging. It would be valuable to have an additional test point to monitor the 5V line out of the voltage regulator (power submodule).

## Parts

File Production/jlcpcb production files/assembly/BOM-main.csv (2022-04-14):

Comment | Designator | Footprint | LCSC
2N2222A | Q1 | TO-92 | C118536
C13828 | SW1,SW2 | SW_1825910-6-4 | C13828
0.1u | C3,C4 | C_0201_0603Metric | C141382
1e-6 | C1 | C_0201_0603Metric | C15849
1N5819 | D3 | D_SOD-323 | C191023
0 | R19,R20 | R_0603_1608Metric | C21189
1K | R15,R16,R17 | R_0603_1608Metric | C21190
1200 | R5 | R_0603_1608Metric | C22765
100 | R2,R3,R4 | R_0603_1608Metric | C22775
15k | R7 | R_0603_1608Metric | C22809
4K7 | R18 | R_0603_1608Metric | C23162
DIODE | D4 | LED_0805_2012Metric | C2480
10k | R10,R11,R12,R13,R14,R8,R9 | R_0603_1608Metric | C25804
110k | R6 | R_0603_1608Metric | C25805
LM75B | U3 | SOIC127P600X175-8N | C2837470
MT3608L | U2 | SOT-23-6 | C2932326
TP4054 | U1 | SOT-23-5 | C32574
MLP2012V4R7MT0S1 | L1 | L_0805_2012Metric | C383376
USB_B_Micro | J5 | USB_Micro-B_Amphenol_10103594-0001LF_Horizontal | C404969
1800 | R1 | R_0603_1608Metric | C4177
22u | C2 | C_0805_2012Metric | C45783
AT24C256C-SSHL-T | U4 | EEPROM | C6482
10K - 0.2M | LDR1,LDR2 | R_Axial_DIN0204_L3.6mm_D1.6mm_P1.90mm_Vertical | C779572
2V | D1,D2,LED1 | LED_0805_2012Metric | C84256
CH340C | U5 | SOP-16_3.9x9.9mm_P1.27mm | C84681
4.2V-3V | BT1 | BatteryHolder_Keystone_1042_1x18650
Conn_01x33_Female | J2 | PinSocket_1x33_P2.54mm_Vertical
Conn_01x33_Female | J1 | PinHeader_1x33_P2.54mm_Vertical
Conn_01x33_Female | J4 | PinHeader_1x33_P2.54mm_Vertical
Conn_01x33_Female | J3 | PinSocket_1x33_P2.54mm_Vertical

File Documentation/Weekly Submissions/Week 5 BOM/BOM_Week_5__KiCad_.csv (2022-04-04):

Source: | C:\Users\USER\Desktop\eee3088f-group-project\Schematics\main\main.kicad_sch
Date: | 2022/03/18 20:51:39
Tool: | Eeschema (6.0.2)
Generator: | C:\Program Files\KiCad\6.0\bin\scripting\plugins/bom_csv_grouped_by_value_with_fp.py
Component Count: | 47
Ref | Qnty | Value | Cmp name | Footprint | Description | Vendor
BT1, | 1 | 3V | Battery | Battery:BatteryHolder_Keystone_1042_1x18650 | Multiple-cell battery
C1, | 1 | 0.33e-6 | C | Capacitor_SMD:C_0201_0603Metric | Unpolarized capacitor
C2, | 1 | 1e-6 | C | Capacitor_SMD:C_0201_0603Metric | Unpolarized capacitor
C3, | 1 | 0.1e-6 | C | Capacitor_SMD:C_0201_0603Metric | Unpolarized capacitor
C4, | 1 | 0.1u | C | Capacitor_SMD:C_0201_0603Metric | Unpolarized capacitor
C5, | 1 | CT41G-0402-2X1-16V-0.1Î¼F-K(N) | C_Small | Capacitor_SMD:C_0201_0603Metric | Unpolarized capacitor, small symbol
D1, D2, | 2 | 2V | LED | LED_SMD:LED_0805_2012Metric | Light emitting diode
D3, | 1 | DIODE | DIODE | LED_SMD:LED_0805_2012Metric | Diode, anode on pin 1, for simulation only!
EEPROM1, | 1 | AT24C256C-SSHL-T | CAT24C256 | SOIC127P600X175-8N:EEPROM | 256 kb CMOS Serial EEPROM, DIP-8/SOIC-8/TSSOP-8/DFN-8
FTDI(UART)1, | 1 | CH340C | CH340C | CH340C:SOIC127P600X180-16N | USB serial converter, UART, SOIC-16
J1, J4, | 2 | Conn_01x33_Female | Conn_01x33_Female | Connector_PinHeader_2.54mm:PinHeader_1x33_P2.54mm_Vertical | Generic connector, single row, 01x33, script generated (kicad-library-utils/schlib/autogen/connector/)
J2, J3, | 2 | Conn_01x33_Female | Conn_01x33_Female | Connector_PinSocket_2.54mm:PinSocket_1x33_P2.54mm_Vertical | Generic connector, single row, 01x33, script generated (kicad-library-utils/schlib/autogen/connector/)
J5, J6, | 2 | USB_B_Micro | USB_B_Micro | Connector_USB:USB_Micro-B_Amphenol_10103594-0001LF_Horizontal | USB Micro Type B connector
LDR1, | 1 | 10K - 0.2M | R_Photo | Resistor_SMD:R_0201_0603Metric | Photoresistor
LDR2, | 1 | 10k - 0.2M | R_Photo | Resistor_SMD:R_0201_0603Metric | Photoresistor
LED1, | 1 | 2V | LED | LED_SMD:LED_0805_2012Metric | Light emitting diode
Q1, | 1 | 2N2222A | 2N2219 | Package_TO_SOT_THT:TO-92 | 800mA Ic, 50V Vce, NPN Transistor, TO-39
R1, | 1 | 1650 | R_Small_US | Resistor_SMD:R_0201_0603Metric | Resistor, small US symbol
R2, R6, | 2 | 100ohms | R_Small_US | Resistor_SMD:R_0201_0603Metric | Resistor, small US symbol
R3, | 1 | 31ohms | R_Small_US | Resistor_SMD:R_0201_0603Metric | Resistor, small US symbol
R4, | 1 | 160 | R_Small_US | Resistor_SMD:R_0201_0603Metric | Resistor, small US symbol
R5, | 1 | 10 | R_Small_US | Resistor_SMD:R_0201_0603Metric | Resistor, small US symbol
R7, | 1 | 1000 | R_Small_US | Resistor_SMD:R_0201_0603Metric | Resistor, small US symbol
R8, R10, R19, | 3 | 10K | R_Small_US | Resistor_SMD:R_0201_0603Metric | Resistor, small US symbol
R9, R15, R16, R17, | 4 | 1K | R_Small_US | Resistor_SMD:R_0201_0603Metric | Resistor, small US symbol
R11, R12, R13, R14, | 4 | 10k | R | Resistor_SMD:R_0201_0603Metric | Resistor
R18, | 1 | 4K7 | R_Small_US | Resistor_SMD:R_0201_0603Metric | Resistor, small US symbol
SW1, | 1 | Push Button 1 | SW_Push | 1825910-6:SW_1825910-6-4 | Push button switch, generic, two pins
SW2, SW3, | 2 | C13828 | SW_Push_Open | 1825910-6:SW_1825910-6-4 | Push button switch, push-to-open, generic, two pins
TempSensor1, | 1 | LM75B | LM75B | LM75BD:SOIC127P600X175-8N | Digital Temperature Sensor & Thermal Watchdog with LP on I2C and bus fault timeout, SOIC-8 and VSSOP-8
U1, | 1 | TLV316 | OPAMP | Package_TO_SOT_SMD:SOT-23-5 | OPAmp symbol for simulation only
U2, | 1 | TP4054 | MCP73831-2-OT | Package_TO_SOT_SMD:SOT-23-5 | Single cell, Li-Ion/Li-Po charge management controller, 4.20V, Tri-State Status Output, in SOT23-5 package
VoltageRegulator1, | 1 | CJ78M05 | KA78M05_TO252 | Package_TO_SOT_SMD:TO-252-2 | Positive 500mA 35V Linear Regulator, Fixed Output 5V, TO-252 (D-PAK)

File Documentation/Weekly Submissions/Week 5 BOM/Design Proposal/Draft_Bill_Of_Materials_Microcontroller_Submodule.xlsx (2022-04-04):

Unit | Description | Multiplier | Cost per unit ($) | Total Cost ($) | Notes
C404969 | Surface Mount Micro-B SMD USB Connector | x1 | 0.048 | 0.048
CH340C | FTDI USB-to-UART chip | x1 | 0.7311 | 0.7311
M24128-BRMN6TP | EEPROM | x1 | 0.2052 | 0.2052
STM32F051 | Microcontroller chip & discovery kit | x1 | 0 | 0 | (retained from EEE2046F)
USB to microB cable | USB to microB cable | x1 | 0 | 0 | (retained from EEE2046F)
Total Cost: |  |  |  | 0.9843

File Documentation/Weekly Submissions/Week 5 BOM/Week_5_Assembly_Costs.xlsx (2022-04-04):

ASSEMBLY COSTS
Item | Multiplier | Unit Cost ($) | Cost ($)
SMT components | 36 | 0.0017 | 0.0612
Hand soldered components | 3 | 1.5 | 4.5
Extended parts [ once off fee] | 14 | 3 | 42
TOTAL COST PER BOARD |  |  | 9.31224
TOTAL COST (5 BOARDS) |  |  | 46.5612

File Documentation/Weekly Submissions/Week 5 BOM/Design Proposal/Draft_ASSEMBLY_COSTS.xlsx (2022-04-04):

ASSEMBLY COSTS
Item | Multiplier | Unit Cost ($) | Cost ($)
SMT components | 24 | 0.0017 | 0.0408
Hand soldered components | 4 | 1.5 | 14
Extended parts [ once off fee] | 4 | 3 | 12
TOTAL COST PER BOARD |  |  | 29.0883
TOTAL COST (5 BOARDS) |  |  | 97.4415

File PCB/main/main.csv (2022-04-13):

Source: | C:\Users\USER\Desktop\eee3088f-group-18-project\PCB\main\main.kicad_sch
Date: | 2022/04/12 22:40:36
Tool: | Eeschema (6.0.2)
Generator: | C:\Program Files\KiCad\6.0\bin\scripting\plugins/bom_csv_grouped_by_value.py
Component Count: | 51
Individual Components:
Item | Qty | Reference(s) | Value | LibPart | Footprint | Datasheet | Alt_LCSC | LCSC | Populate | Price | Spice_Netlist_Enabled | Spice_Primitive
 |  | BT1 | 4.2V-3V | Device:Battery | Battery:BatteryHolder_Keystone_1042_1x18650 | ~ |  |  | DNP
 |  | C1 | 1e-6 | Device:C | Capacitor_SMD:C_0201_0603Metric | ~ |  | C15849 | P | 0.0055
 |  | C2 | 22u | Device:C_Small | Capacitor_SMD:C_0805_2012Metric | https://datasheet.lcsc.com/lcsc/1811151152_Samsung-Electro-Mechanics-CL21A226MAQNNNE_C45783.pdf |  | C45783 | P | 0.0361
 |  | C3 | 0.1u | Device:C | Capacitor_SMD:C_0201_0603Metric | ~ |  | C141382 | P | 0.0032
 |  | C4 | 0.1μF | Device:C_Small | Capacitor_SMD:C_0201_0603Metric | https://datasheet.lcsc.com/lcsc/1809291616_TORCH-CT41-0603-2X1-25V-0-1-F-K-N_C139738.pdf |  | C141382 | P | 0.0032
 |  | D1 | 2V | Device:LED | LED_SMD:LED_0805_2012Metric | ~https://datasheet.lcsc.com/lcsc/2008201032_Foshan-NationStar-Optoelectronics-NCD0805R1_C84256.pdf |  | C84256 | P | 0.0136
 |  | D2 | 2V | Device:LED | LED_SMD:LED_0805_2012Metric | ~ |  | C84256 | P | 0.0136
 |  | D3 | 1N5819 | Diode:1N5819 | Diode_SMD:D_SOD-323 | https://datasheet.lcsc.com/lcsc/1810202112_Guangdong-Hottech-1N5819WS_C191023.pdf |  | C191023 | P | 0.0279
 |  | D4 | DIODE | Simulation_SPICE:DIODE | LED_SMD:LED_0805_2012Metric | https://datasheet.lcsc.com/lcsc/2105061432_MDD-Microdiode-Electronics--SS14_C2480.pdf |  | C2480 | P | 0.0179 | Y | D
 |  | EEPROM1 | AT24C256C-SSHL-T | Memory_EEPROM:CAT24C256 | SOIC127P600X175-8N:EEPROM | https://www.onsemi.cn/PowerSolutions/document/CAT24C256-D.PDF |  | C6482 | P | 1.4287
 |  | FTDI(UART)1 | CH340C | Interface_USB:CH340C | CH340C:SOIC127P600X180-16N | https://datasheet.lcsc.com/szlcsc/Jiangsu-Qin-Heng-CH340C_C84681.pdf |  | C84681 | P | 0.5589 | Center | Center
 |  | J1 | Conn_01x33_Female | Connector:Conn_01x33_Female | Connector_PinHeader_2.54mm:PinHeader_1x33_P2.54mm_Vertical | ~ |  |  | DNP | 0
 |  | J2 | Conn_01x33_Female | Connector:Conn_01x33_Female | Connector_PinSocket_2.54mm:PinSocket_1x33_P2.54mm_Vertical | ~ |  |  | DNP | 0
 |  | J3 | Conn_01x33_Female | Connector:Conn_01x33_Female | Connector_PinSocket_2.54mm:PinSocket_1x33_P2.54mm_Vertical | ~ |  |  | DNP | 0
 |  | J4 | Conn_01x33_Female | Connector:Conn_01x33_Female | Connector_PinHeader_2.54mm:PinHeader_1x33_P2.54mm_Vertical | ~ |  |  | DNP | 0
 |  | J5 | USB_B_Micro | Connector:USB_B_Micro | Connector_USB:USB_Micro-B_Amphenol_10103594-0001LF_Horizontal | ~ |  | C404969 | P | 0.047
 |  | L1 | MLP2012V4R7MT0S1 | Custom:MLP2012V4R7MT0S1 | 3088HAT:INDC2012X87N | https://datasheet.lcsc.com/lcsc/1912111437_TDK-MLP2012V4R7MT0S1_C383376.pdf |  | C383376 | P | 0.0425
 |  | LDR1 | 10K - 0.2M | Device:R_Photo | Resistor_SMD:R_0201_0603Metric | ~ |  | C779572 | P | 0.0503
 |  | LDR2 | 10k - 0.2M | Device:R_Photo | Resistor_SMD:R_0201_0603Metric | ~ |  | C779572 | P | 0.0503
 |  | LED1 | 2V | Device:LED | LED_SMD:LED_0805_2012Metric | ~ |  | C84256 | P | 0.0136
 |  | Q1 | 2N2222A | Transistor_BJT:2N2219 | Package_TO_SOT_THT:TO-92 | http://www.onsemi.com/pub_link/Collateral/2N2219-D.PDF |  | C118536 | P | 0.0214
 |  | R1 | 1800 | Device:R_Small_US | Resistor_SMD:R_0201_0603Metric | ~ |  | C4177 | P | 0.0013
 |  | R2 | 100ohms | Device:R_Small_US | Resistor_SMD:R_0201_0603Metric | ~ |  | C22775 | P | 0.0012
 |  | R3 | 100ohms | Device:R_Small_US | Resistor_SMD:R_0201_0603Metric | ~ |  | C22775 | P | 0.0012
 |  | R4 | 100ohms | Device:R_Small_US | Resistor_SMD:R_0201_0603Metric | ~ |  | C22775 | P | 0.0012
 |  | R5 | 1200 | Device:R_Small_US | Resistor_SMD:R_0201_0603Metric | ~ |  | C22765 | P | 0.0013
 |  | R6 | 110k | Device:R_US | Resistor_SMD:R_0201_0603Metric | https://datasheet.lcsc.com/lcsc/2110260030_UNI-ROYAL-Uniroyal-Elec-0603WAF1103T5E_C25805.pdf |  | C25805 | P | 0.0014
 |  | R7 | 15k | Device:R_US | Resistor_SMD:R_0201_0603Metric | https://datasheet.lcsc.com/lcsc/2110252030_UNI-ROYAL-Uniroyal-Elec-0603WAF1502T5E_C22809.pdf |  | C22809 | P | 0.0013
 |  | R8 | 10K | Device:R | Resistor_SMD:R_0201_0603Metric | https://datasheet.lcsc.com/lcsc/2110260030_UNI-ROYAL-Uniroyal-Elec-0603WAF1002T5E_C25804.pdf |  | C25804 | P | 0.0012
 |  | R9 | 10K | Device:R | Resistor_SMD:R_0201_0603Metric | https://datasheet.lcsc.com/lcsc/2110260030_UNI-ROYAL-Uniroyal-Elec-0603WAF1002T5E_C25804.pdf |  | C25804 | P | 0.0012
 |  | R10 | 10k | Device:R | Resistor_SMD:R_0201_0603Metric | https://datasheet.lcsc.com/lcsc/2110260030_UNI-ROYAL-Uniroyal-Elec-0603WAF1002T5E_C25804.pdf |  | C25804 | P | 0.0012
 |  | R11 | 10k | Device:R | Resistor_SMD:R_0201_0603Metric | https://datasheet.lcsc.com/lcsc/2110260030_UNI-ROYAL-Uniroyal-Elec-0603WAF1002T5E_C25804.pdf |  | C25804 | P | 0.0012
 |  | R12 | 10k | Device:R | Resistor_SMD:R_0201_0603Metric | https://datasheet.lcsc.com/lcsc/2110260030_UNI-ROYAL-Uniroyal-Elec-0603WAF1002T5E_C25804.pdf |  | C25804 | P | 0.0012
 |  | R13 | 10k | Device:R | Resistor_SMD:R_0201_0603Metric | https://datasheet.lcsc.com/lcsc/2110260030_UNI-ROYAL-Uniroyal-Elec-0603WAF1002T5E_C25804.pdf |  | C25804 | P | 0.0012
 |  | R14 | 10K | Device:R_Small_US | Resistor_SMD:R_0201_0603Metric | https://datasheet.lcsc.com/lcsc/2110260030_UNI-ROYAL-Uniroyal-Elec-0603WAF1002T5E_C25804.pdf |  | C25804 | P | 0.0012
 |  | R15 | 1K | Device:R_Small_US | Resistor_SMD:R_0201_0603Metric | https://datasheet.lcsc.com/lcsc/2110252030_UNI-ROYAL-Uniroyal-Elec-0603WAF1001T5E_C21190.pdf |  | C21190 | P | 0.0012
 |  | R16 | 1K | Device:R_Small_US | Resistor_SMD:R_0201_0603Metric | https://datasheet.lcsc.com/lcsc/2110252030_UNI-ROYAL-Uniroyal-Elec-0603WAF1001T5E_C21190.pdf |  | C21190 | P | 0.0012
 |  | R17 | 1K | Device:R_Small_US | Resistor_SMD:R_0201_0603Metric | https://datasheet.lcsc.com/lcsc/2110252030_UNI-ROYAL-Uniroyal-Elec-0603WAF1001T5E_C21190.pdf |  | C21190 | P | 0.0012
 |  | R18 | 4K7 | Device:R_Small_US | Resistor_SMD:R_0201_0603Metric | https://datasheet.lcsc.com/lcsc/2110252130_UNI-ROYAL-Uniroyal-Elec-0603WAF4701T5E_C23162.pdf |  | C23162 | P | 0.0012
 |  | R19 | 0 | Device:R_Small_US | Resistor_SMD:R_0201_0603Metric | https://datasheet.lcsc.com/lcsc/2110252030_UNI-ROYAL-Uniroyal-Elec-0603WAF0000T5E_C21189.pdf |  | C21189 | P | 0.0012
 |  | R20 | 0 | Device:R_Small_US | Resistor_SMD:R_0201_0603Metric | https://datasheet.lcsc.com/lcsc/2110252030_UNI-ROYAL-Uniroyal-Elec-0603WAF0000T5E_C21189.pdf |  | C21189 | P | 0.0012
 |  | SW1 | C13828 | Switch:SW_Push_Open | 1825910-6:SW_1825910-6-4 | https://datasheet.lcsc.com/szlcsc/1912111437_Dongguan-Guangzhu-Industrial-C13828_C13828.pdf |  | C13828 | P | 0.0394
 |  | SW2 | C13828 | Switch:SW_Push_Open | 1825910-6:SW_1825910-6-4 | https://datasheet.lcsc.com/szlcsc/1912111437_Dongguan-Guangzhu-Industrial-C13828_C13828.pdf |  | C13828 | P | 0.0394
 |  | TempSensor1 | LM75B | Sensor_Temperature:LM75B | LM75BD:SOIC127P600X175-8N | http://www.ti.com/lit/ds/symlink/lm75b.pdf | C2837470 | C2837470 | P | 0.4002
 |  | TP1 | CLK TestPoint | Connector:TestPoint | TestPoint:TestPoint_2Pads_Pitch2.54mm_Drill0.8mm | ~ |  |  | DNP
 |  | TP2 | USB TestPoint | Connector:TestPoint | TestPoint:TestPoint_2Pads_Pitch2.54mm_Drill0.8mm | ~ |  |  | DNP
 |  | TP3 | TestPoint | Connector:TestPoint | TestPoint:TestPoint_2Pads_Pitch2.54mm_Drill0.8mm | ~ |  |  | DNP
 |  | TP4 | TestPoint | Connector:TestPoint | TestPoint:TestPoint_2Pads_Pitch2.54mm_Drill0.8mm | ~ |  |  | DNP
 |  | TP5 | TestPoint | Connector:TestPoint | TestPoint:TestPoint_2Pads_Pitch2.54mm_Drill0.8mm | ~ |  |  | DNP
 |  | U1 | TP4054 | Battery_Management:MCP73831-2-OT | Package_TO_SOT_SMD:SOT-23-5 | http://ww1.microchip.com/downloads/en/DeviceDoc/20001984g.pdf |  | C32574 | P | 0.1555
 |  | U2 | MT3608L | Custom:MT3608L | Package_TO_SOT_SMD:SOT-23-6 | https://datasheet.lcsc.com/lcsc/2201121530_XI-AN-Aerosemi-Tech-MT3608L_C2932326.pdf |  | C2932326 | P | 0.0693
Collated Components:
Item | Qty | Reference(s) | Value | LibPart | Footprint | Datasheet | Alt_LCSC | LCSC | Populate | Price | Spice_Netlist_Enabled | Spice_Primitive
1 | 1 | BT1 | 4.2V-3V | Device:Battery | Battery:BatteryHolder_Keystone_1042_1x18650 | ~ |  |  | DNP
2 | 1 | C1 | 1e-6 | Device:C | Capacitor_SMD:C_0201_0603Metric | ~ |  | C15849 | P | 0.0055
3 | 1 | C2 | 22u | Device:C_Small | Capacitor_SMD:C_0805_2012Metric | https://datasheet.lcsc.com/lcsc/1811151152_Samsung-Electro-Mechanics-CL21A226MAQNNNE_C45783.pdf |  | C45783 | P | 0.0361
4 | 1 | C3 | 0.1u | Device:C | Capacitor_SMD:C_0201_0603Metric | ~ |  | C141382 | P | 0.0032
5 | 1 | C4 | 0.1μF | Device:C_Small | Capacitor_SMD:C_0201_0603Metric | https://datasheet.lcsc.com/lcsc/1809291616_TORCH-CT41-0603-2X1-25V-0-1-F-K-N_C139738.pdf |  | C141382 | P | 0.0032
6 | 3 | D1, D2, LED1 | 2V | Device:LED | LED_SMD:LED_0805_2012Metric | ~https://datasheet.lcsc.com/lcsc/2008201032_Foshan-NationStar-Optoelectronics-NCD0805R1_C84256.pdf |  | C84256 | P | 0.0136
7 | 1 | D3 | 1N5819 | Diode:1N5819 | Diode_SMD:D_SOD-323 | https://datasheet.lcsc.com/lcsc/1810202112_Guangdong-Hottech-1N5819WS_C191023.pdf |  | C191023 | P | 0.0279
8 | 1 | D4 | DIODE | Simulation_SPICE:DIODE | LED_SMD:LED_0805_2012Metric | https://datasheet.lcsc.com/lcsc/2105061432_MDD-Microdiode-Electronics--SS14_C2480.pdf |  | C2480 | P | 0.0179 | Y | D
9 | 1 | EEPROM1 | AT24C256C-SSHL-T | Memory_EEPROM:CAT24C256 | SOIC127P600X175-8N:EEPROM | https://www.onsemi.cn/PowerSolutions/document/CAT24C256-D.PDF |  | C6482 | P | 1.4287
10 | 1 | FTDI(UART)1 | CH340C | Interface_USB:CH340C | CH340C:SOIC127P600X180-16N | https://datasheet.lcsc.com/szlcsc/Jiangsu-Qin-Heng-CH340C_C84681.pdf |  | C84681 | P | 0.5589 | Center | Center
11 | 2 | J1, J4 | Conn_01x33_Female | Connector:Conn_01x33_Female | Connector_PinHeader_2.54mm:PinHeader_1x33_P2.54mm_Vertical | ~ |  |  | DNP | 0
12 | 2 | J2, J3 | Conn_01x33_Female | Connector:Conn_01x33_Female | Connector_PinSocket_2.54mm:PinSocket_1x33_P2.54mm_Vertical | ~ |  |  | DNP | 0
13 | 1 | J5 | USB_B_Micro | Connector:USB_B_Micro | Connector_USB:USB_Micro-B_Amphenol_10103594-0001LF_Horizontal | ~ |  | C404969 | P | 0.047
14 | 1 | L1 | MLP2012V4R7MT0S1 | Custom:MLP2012V4R7MT0S1 | 3088HAT:INDC2012X87N | https://datasheet.lcsc.com/lcsc/1912111437_TDK-MLP2012V4R7MT0S1_C383376.pdf |  | C383376 | P | 0.0425
15 | 1 | LDR1 | 10K - 0.2M | Device:R_Photo | Resistor_SMD:R_0201_0603Metric | ~ |  | C779572 | P | 0.0503
16 | 1 | LDR2 | 10k - 0.2M | Device:R_Photo | Resistor_SMD:R_0201_0603Metric | ~ |  | C779572 | P | 0.0503
17 | 1 | Q1 | 2N2222A | Transistor_BJT:2N2219 | Package_TO_SOT_THT:TO-92 | http://www.onsemi.com/pub_link/Collateral/2N2219-D.PDF |  | C118536 | P | 0.0214
18 | 1 | R1 | 1800 | Device:R_Small_US | Resistor_SMD:R_0201_0603Metric | ~ |  | C4177 | P | 0.0013
19 | 3 | R2, R3, R4 | 100ohms | Device:R_Small_US | Resistor_SMD:R_0201_0603Metric | ~ |  | C22775 | P | 0.0012
20 | 1 | R5 | 1200 | Device:R_Small_US | Resistor_SMD:R_0201_0603Metric | ~ |  | C22765 | P | 0.0013
21 | 1 | R6 | 110k | Device:R_US | Resistor_SMD:R_0201_0603Metric | https://datasheet.lcsc.com/lcsc/2110260030_UNI-ROYAL-Uniroyal-Elec-0603WAF1103T5E_C25805.pdf |  | C25805 | P | 0.0014
22 | 1 | R7 | 15k | Device:R_US | Resistor_SMD:R_0201_0603Metric | https://datasheet.lcsc.com/lcsc/2110252030_UNI-ROYAL-Uniroyal-Elec-0603WAF1502T5E_C22809.pdf |  | C22809 | P | 0.0013
23 | 2 | R8, R9 | 10K | Device:R | Resistor_SMD:R_0201_0603Metric | https://datasheet.lcsc.com/lcsc/2110260030_UNI-ROYAL-Uniroyal-Elec-0603WAF1002T5E_C25804.pdf |  | C25804 | P | 0.0012
24 | 4 | R10, R11, R12, R13 | 10k | Device:R | Resistor_SMD:R_0201_0603Metric | https://datasheet.lcsc.com/lcsc/2110260030_UNI-ROYAL-Uniroyal-Elec-0603WAF1002T5E_C25804.pdf |  | C25804 | P | 0.0012
25 | 1 | R14 | 10K | Device:R_Small_US | Resistor_SMD:R_0201_0603Metric | https://datasheet.lcsc.com/lcsc/2110260030_UNI-ROYAL-Uniroyal-Elec-0603WAF1002T5E_C25804.pdf |  | C25804 | P | 0.0012
26 | 3 | R15, R16, R17 | 1K | Device:R_Small_US | Resistor_SMD:R_0201_0603Metric | https://datasheet.lcsc.com/lcsc/2110252030_UNI-ROYAL-Uniroyal-Elec-0603WAF1001T5E_C21190.pdf |  | C21190 | P | 0.0012
27 | 1 | R18 | 4K7 | Device:R_Small_US | Resistor_SMD:R_0201_0603Metric | https://datasheet.lcsc.com/lcsc/2110252130_UNI-ROYAL-Uniroyal-Elec-0603WAF4701T5E_C23162.pdf |  | C23162 | P | 0.0012
28 | 2 | R19, R20 | 0 | Device:R_Small_US | Resistor_SMD:R_0201_0603Metric | https://datasheet.lcsc.com/lcsc/2110252030_UNI-ROYAL-Uniroyal-Elec-0603WAF0000T5E_C21189.pdf |  | C21189 | P | 0.0012
29 | 2 | SW1, SW2 | C13828 | Switch:SW_Push_Open | 1825910-6:SW_1825910-6-4 | https://datasheet.lcsc.com/szlcsc/1912111437_Dongguan-Guangzhu-Industrial-C13828_C13828.pdf |  | C13828 | P | 0.0394
30 | 1 | TempSensor1 | LM75B | Sensor_Temperature:LM75B | LM75BD:SOIC127P600X175-8N | http://www.ti.com/lit/ds/symlink/lm75b.pdf | C2837470 | C2837470 | P | 0.4002
31 | 1 | TP1 | CLK TestPoint | Connector:TestPoint | TestPoint:TestPoint_2Pads_Pitch2.54mm_Drill0.8mm | ~ |  |  | DNP
32 | 1 | TP2 | USB TestPoint | Connector:TestPoint | TestPoint:TestPoint_2Pads_Pitch2.54mm_Drill0.8mm | ~ |  |  | DNP
33 | 3 | TP3, TP4, TP5 | TestPoint | Connector:TestPoint | TestPoint:TestPoint_2Pads_Pitch2.54mm_Drill0.8mm | ~ |  |  | DNP
34 | 1 | U1 | TP4054 | Battery_Management:MCP73831-2-OT | Package_TO_SOT_SMD:SOT-23-5 | http://ww1.microchip.com/downloads/en/DeviceDoc/20001984g.pdf |  | C32574 | P | 0.1555
35 | 1 | U2 | MT3608L | Custom:MT3608L | Package_TO_SOT_SMD:SOT-23-6 | https://datasheet.lcsc.com/lcsc/2201121530_XI-AN-Aerosemi-Tech-MT3608L_C2932326.pdf |  | C2932326 | P | 0.0693

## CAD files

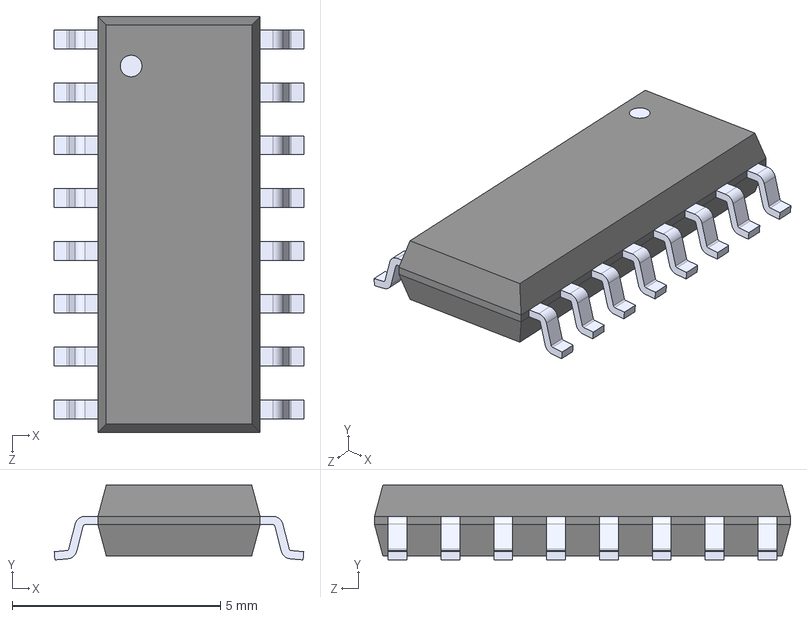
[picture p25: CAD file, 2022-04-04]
PCB/Footprints/Footprints/PCB/Footprints/CH340C/CH340C.step
6.00 x 1.80 x 10.0 mm

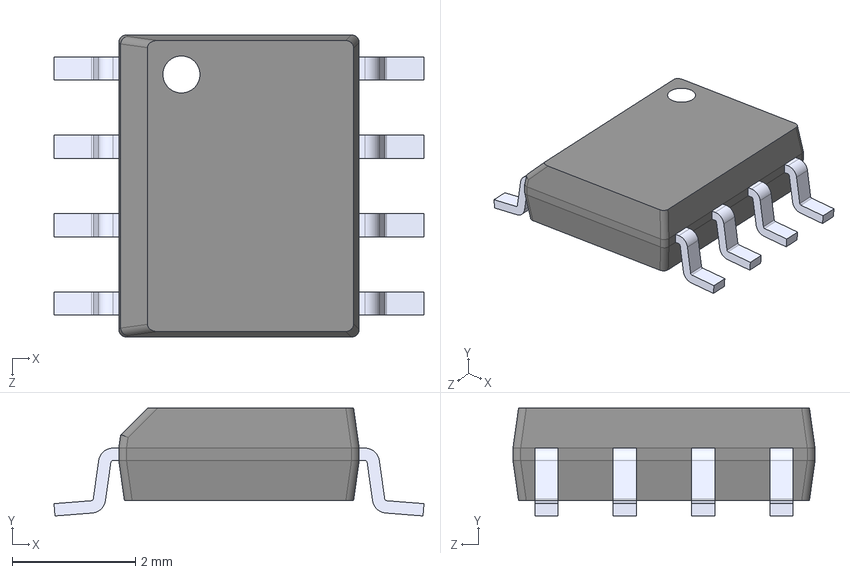
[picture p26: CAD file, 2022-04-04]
PCB/Footprints/Footprints/PCB/Footprints/SOIC127P600X175-8N/SOIC127P600X175-8N.step
6.00 x 1.75 x 4.90 mm

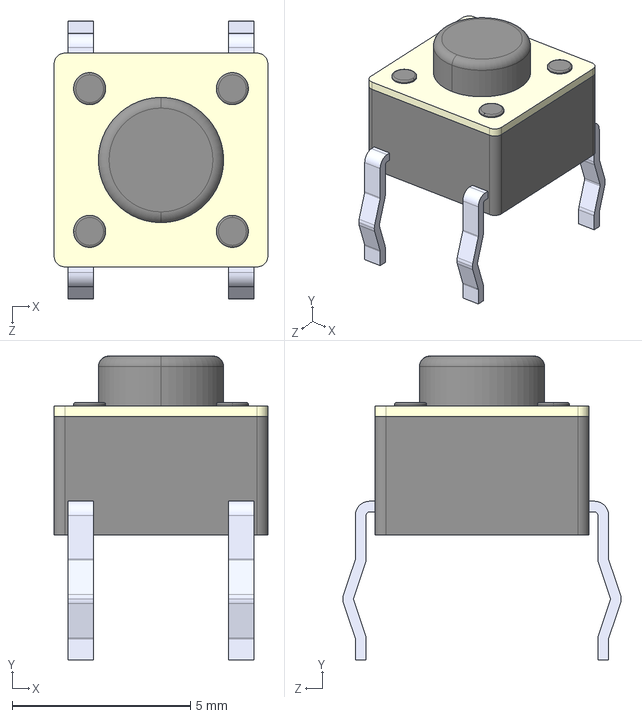
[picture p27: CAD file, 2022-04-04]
PCB/Footprints/Footprints/PCB/Footprints/1825910-6/1825910-6.step
5.99 x 8.52 x 7.80 mm

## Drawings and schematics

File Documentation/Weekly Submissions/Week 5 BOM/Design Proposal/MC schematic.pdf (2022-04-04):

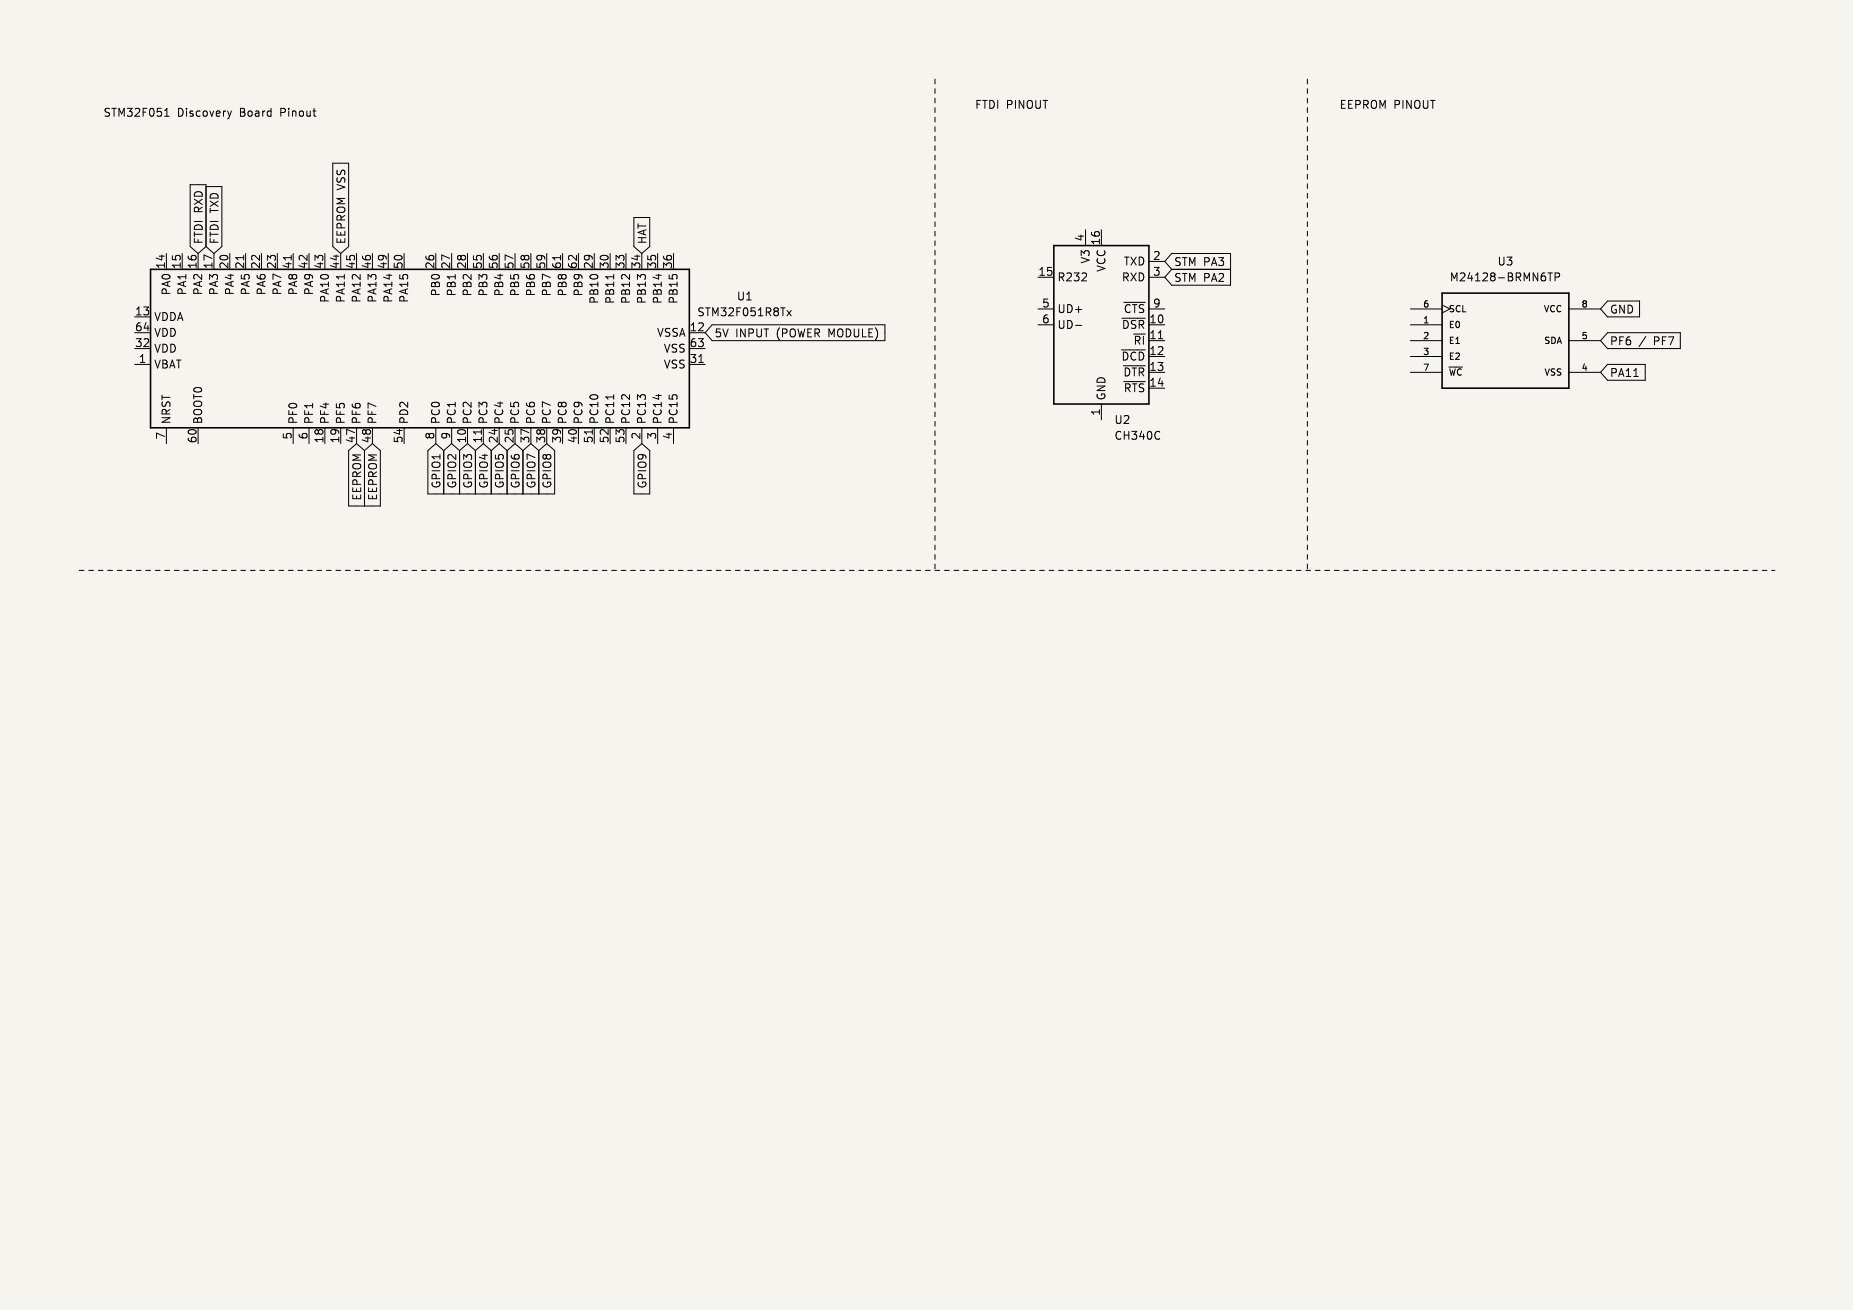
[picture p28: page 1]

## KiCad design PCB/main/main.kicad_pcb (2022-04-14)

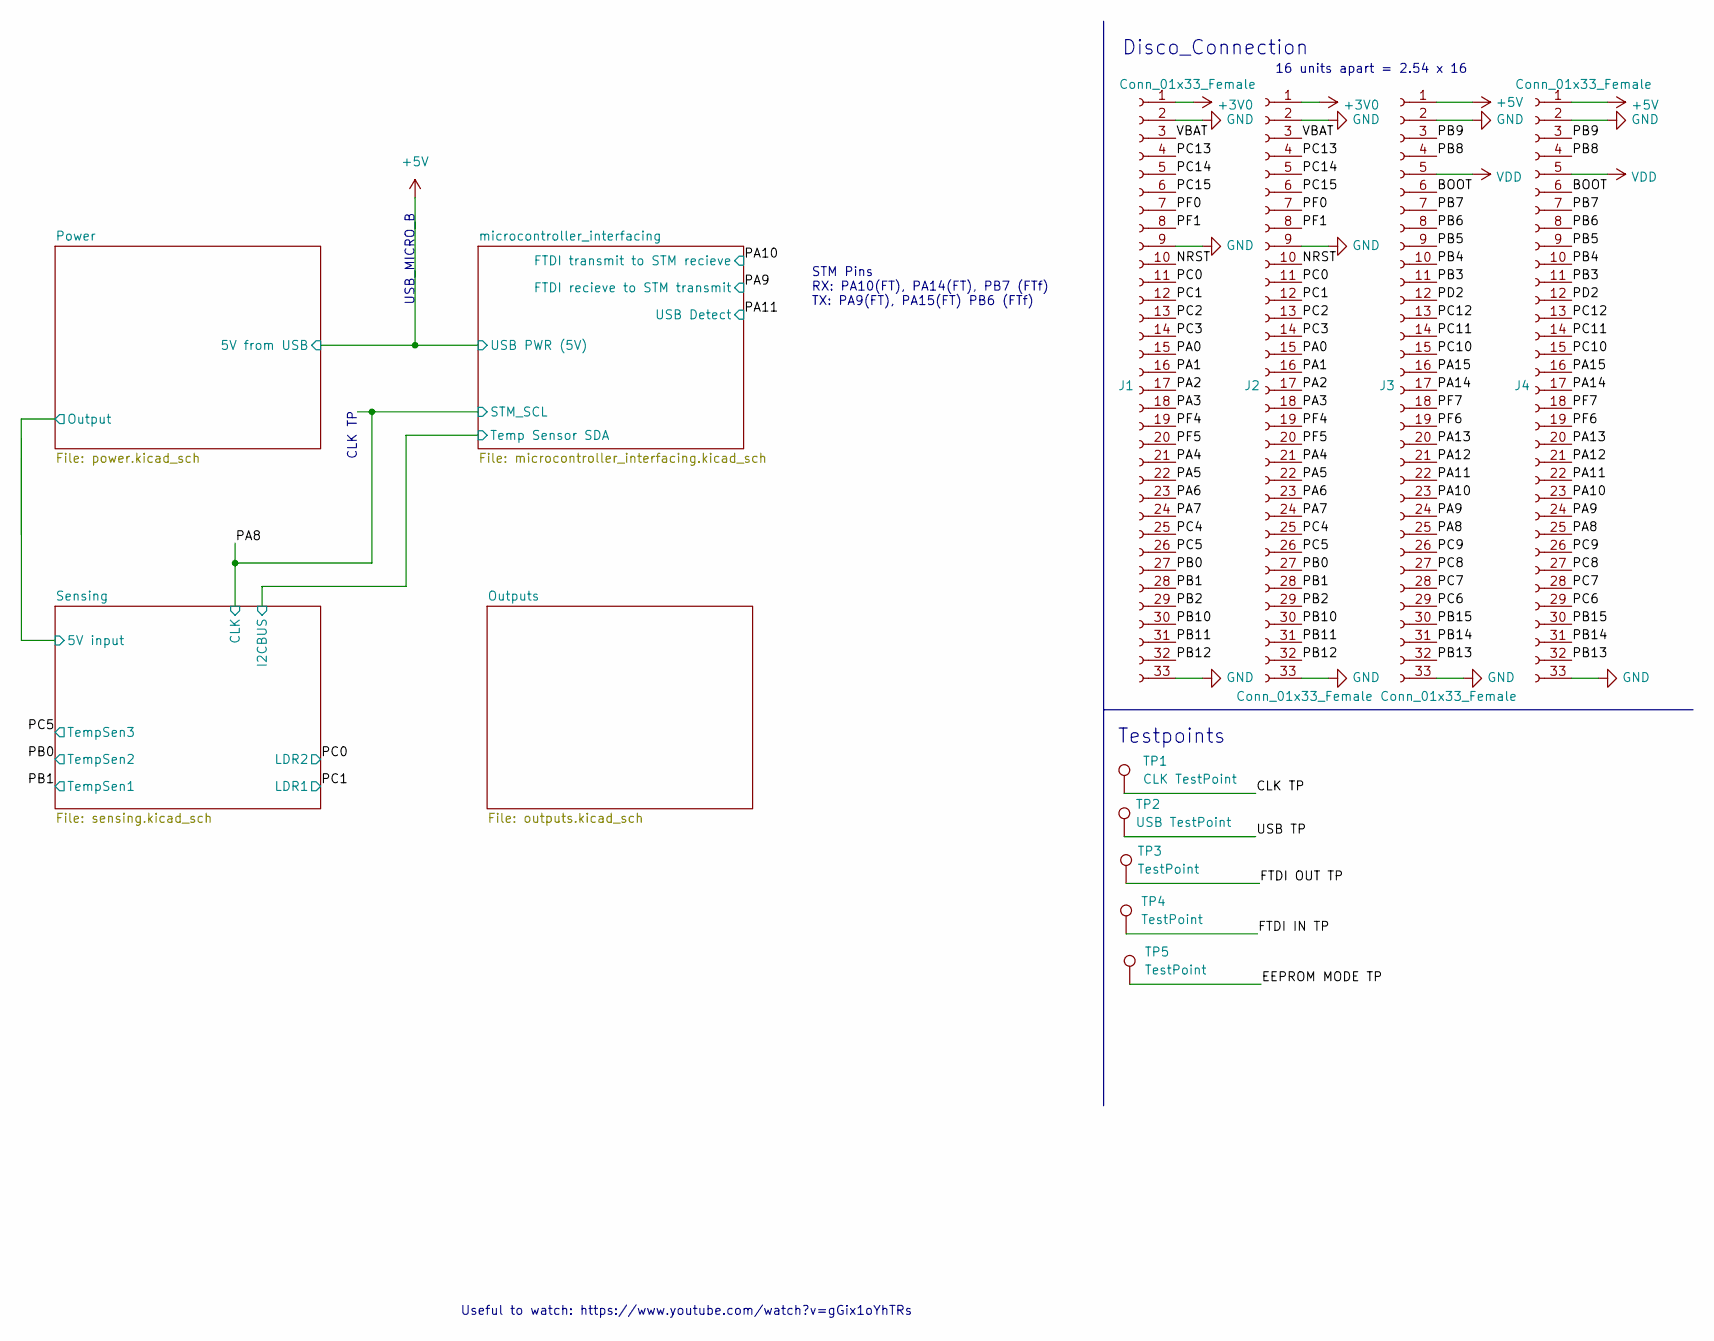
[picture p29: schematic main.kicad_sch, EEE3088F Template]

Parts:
J1, J4: Conn_01x33_Female; PinHeader_1x33_P2.54mm_Vertical
J2, J3: Conn_01x33_Female; PinSocket_1x33_P2.54mm_Vertical
TP1: CLK TestPoint; TestPoint_2Pads_Pitch2.54mm_Drill0.8mm
TP2: USB TestPoint; TestPoint_2Pads_Pitch2.54mm_Drill0.8mm
TP3, TP4, TP5: TestPoint; TestPoint_2Pads_Pitch2.54mm_Drill0.8mm

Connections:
+3V0: J1.1, J2.1
+5V: J3.1, J4.1; also elsewhere on the board
/BOOT: J3.6, J4.6
/NRST: J1.10, J2.10
/PA0: J1.15, J2.15
/PA1: J1.16, J2.16
/PA2: J1.17, J2.17
/PA3: J1.18, J2.18
/PA4: J1.21, J2.21
/PA5: J1.22, J2.22
/PA6: J1.23, J2.23
/PA7: J1.24, J2.24
/PA8: J3.25, J4.25; also elsewhere on the board
/PA9: J3.24, J4.24; also elsewhere on the board
/PA10: J3.23, J4.23; also elsewhere on the board
/PA11: J3.22, J4.22; also elsewhere on the board
/PA12: J3.21, J4.21
/PA13: J3.20, J4.20
/PA14: J3.17, J4.17
/PA15: J3.16, J4.16
/PB0: J1.27, J2.27; also elsewhere on the board
/PB1: J1.28, J2.28; also elsewhere on the board
/PB2: J1.29, J2.29
/PB3: J3.11, J4.11
/PB4: J3.10, J4.10
/PB5: J3.9, J4.9
/PB6: J3.8, J4.8
/PB7: J3.7, J4.7
/PB8: J3.4, J4.4
/PB9: J3.3, J4.3
/PB10: J1.30, J2.30
/PB11: J1.31, J2.31
/PB12: J1.32, J2.32
/PB13: J3.32, J4.32
/PB14: J3.31, J4.31
/PB15: J3.30, J4.30
/PC0: J1.11, J2.11; also elsewhere on the board
/PC1: J1.12, J2.12; also elsewhere on the board
/PC2: J1.13, J2.13
/PC3: J1.14, J2.14
/PC4: J1.25, J2.25
/PC5: J1.26, J2.26; also elsewhere on the board
/PC6: J3.29, J4.29
/PC7: J3.28, J4.28
/PC8: J3.27, J4.27
/PC9: J3.26, J4.26
/PC10: J3.15, J4.15
/PC11: J3.14, J4.14
/PC12: J3.13, J4.13
/PC13: J1.4, J2.4
/PC14: J1.5, J2.5
/PC15: J1.6, J2.6
/PD2: J3.12, J4.12
/PF0: J1.7, J2.7
/PF1: J1.8, J2.8
/PF4: J1.19, J2.19
/PF5: J1.20, J2.20
/PF6: J3.19, J4.19
/PF7: J3.18, J4.18
/VBAT: J1.3, J2.3
GND: J1.2, J1.9, J1.33, J2.2, J2.9, J2.33, J3.2, J3.33, J4.2, J4.33; also elsewhere on the board
VDD: J3.5, J4.5

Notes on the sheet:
Useful to watch: https://www.youtube.com/watch?v=gGix1oYhTRs
CLK TP
STM Pins RX: PA10(FT), PA14(FT), PB7 (FTf) TX: PA9(FT), PA15(FT) PB6 (FTf)
USB_MICRO_B
16 units apart = 2.54 x 16
Disco_Connection
Testpoints

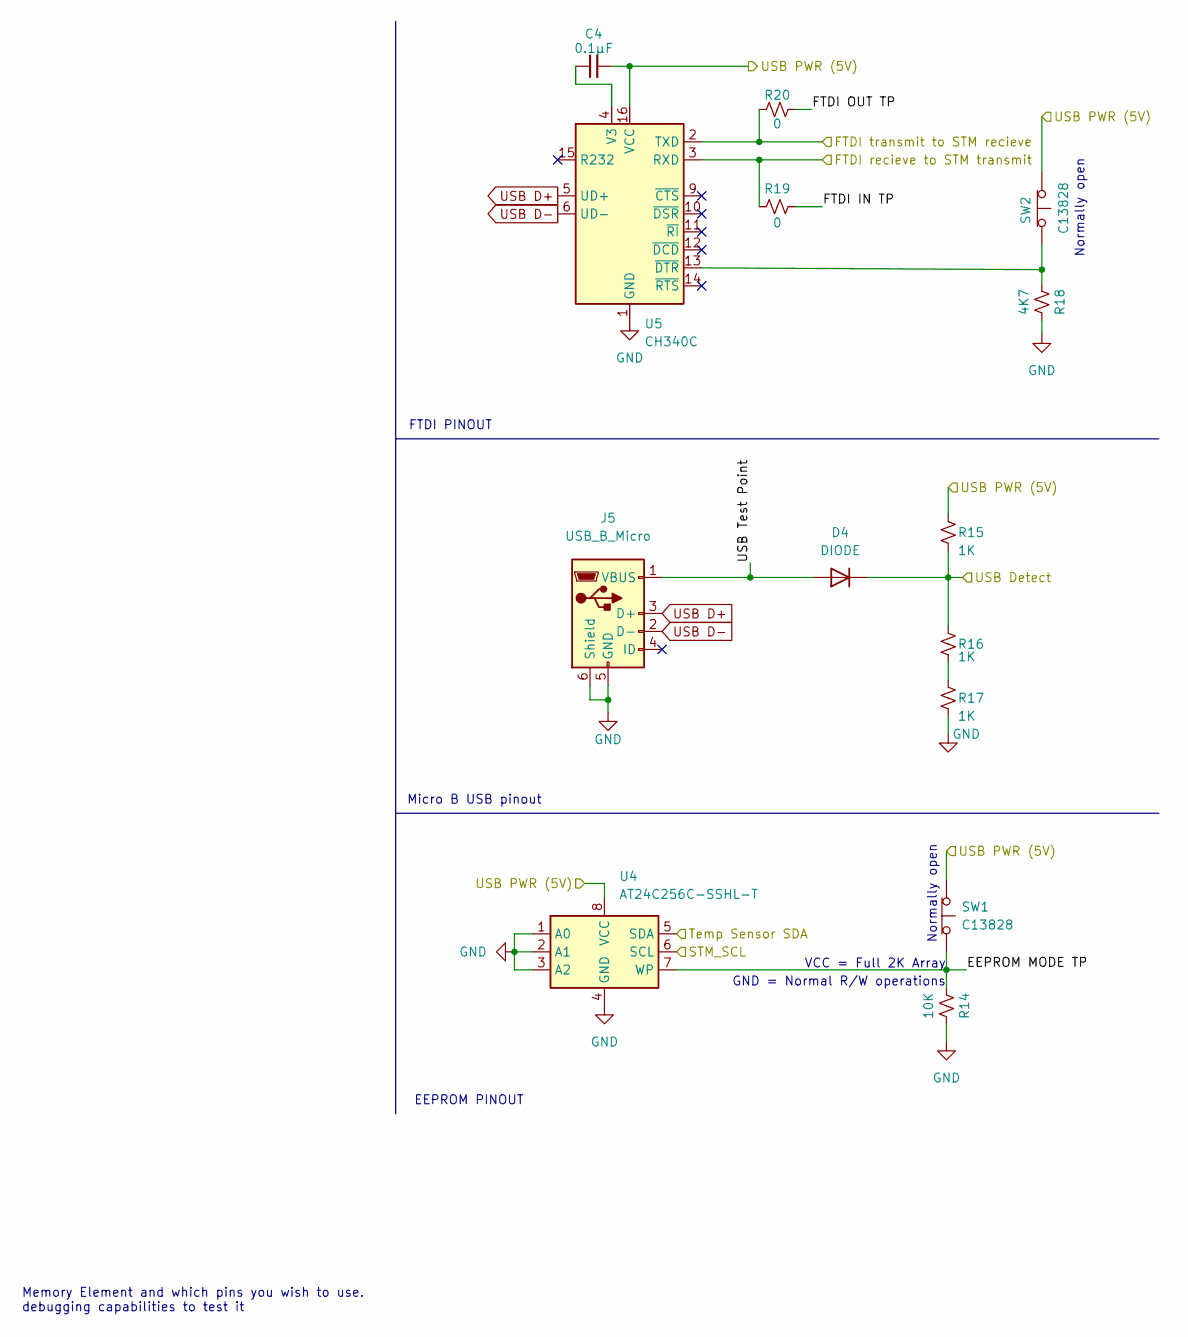
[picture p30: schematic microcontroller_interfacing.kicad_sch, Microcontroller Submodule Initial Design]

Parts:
C4: 0.1μF; C_0201_0603Metric; LCSC C141382
D4: DIODE; LED_0805_2012Metric; LCSC C2480
J5: USB_B_Micro; USB_Micro-B_Amphenol_10103594-0001LF_Horizontal; LCSC C404969
R14: 10K; R_0603_1608Metric; LCSC C25804
R15, R16, R17: 1K; R_0603_1608Metric; LCSC C21190
R18: 4K7; R_0603_1608Metric; LCSC C23162
R19, R20: 0; R_0603_1608Metric; LCSC C21189
SW1, SW2: C13828; SW_1825910-6-4; LCSC C13828
U4: AT24C256C-SSHL-T; EEPROM; LCSC C6482
U5: CH340C; SOP-16_3.9x9.9mm_P1.27mm; LCSC C84681

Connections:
+5V: C4.2, R15.1, SW1.1 (A), SW2.1 (A), U4.8 (VCC), U5.16 (VCC); also elsewhere on the board
/PA8: U4.6 (SCL); also elsewhere on the board
/PA9: R19.1, U5.3 (RXD); also elsewhere on the board
/PA10: R20.1, U5.2 (TXD); also elsewhere on the board
/PA11: D4.2 (K), R15.2, R16.1; also elsewhere on the board
/Sensing/I2CBUS: U4.5 (SDA); also elsewhere on the board
/microcontroller_interfacing/EEPROM MODE TP: R14.1, SW1.2 (B), U4.7 (WP)
/microcontroller_interfacing/FTDI IN TP: R19.2
/microcontroller_interfacing/FTDI OUT TP: R20.2
/microcontroller_interfacing/USB Test Point: D4.1 (A), J5.1 (VBUS)
GND: J5.5 (GND), J5.6 (Shield), R14.2, R17.2, R18.2, U4.1 (A0), U4.2 (A1), U4.3 (A2), U4.4 (GND), U5.1 (GND); also elsewhere on the board
unnamed: C4.1, U5.4 (V3)
unnamed: R16.2, R17.1
unnamed: R18.1, SW2.2 (B), U5.13 (~DTR)
USB D+: J5.3 (D+), U5.5 (UD+)
USB D-: J5.2 (D-), U5.6 (UD-)

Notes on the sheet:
EEPROM PINOUT
VCC = Full 2K Array
Micro B USB pinout
Normally open
Memory Element and which pins you wish to use. debugging capabilities to test it
GND = Normal R/W operations
FTDI PINOUT

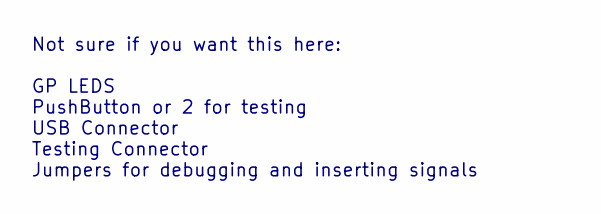
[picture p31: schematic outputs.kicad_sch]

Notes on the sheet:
Not sure if you want this here: GP LEDS PushButton or 2 for testing USB Connector Testing Connector Jumpers for debugging and inserting signals

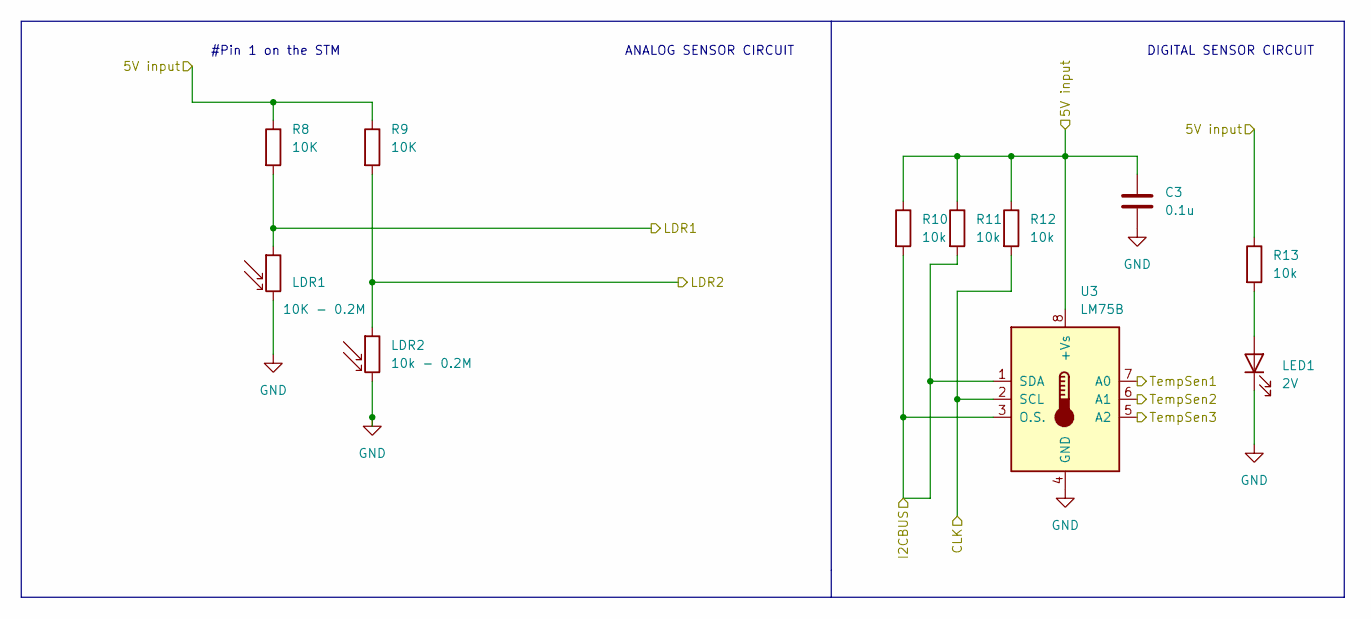
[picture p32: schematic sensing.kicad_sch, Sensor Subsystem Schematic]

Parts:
C3: 0.1u; C_0201_0603Metric; LCSC C141382
LDR1: 10K - 0.2M; R_Axial_DIN0204_L3.6mm_D1.6mm_P1.90mm_Vertical; LCSC C779572
LDR2: 10k - 0.2M; R_Axial_DIN0204_L3.6mm_D1.6mm_P1.90mm_Vertical; LCSC C779572
LED1: 2V; LED_0805_2012Metric; LCSC C84256
R8, R9: 10K; R_0603_1608Metric; LCSC C25804
R10, R11, R12, R13: 10k; R_0603_1608Metric; LCSC C25804
U3: LM75B; SOIC127P600X175-8N; LCSC C34565

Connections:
/PA8: R12.2, U3.2 (SCL); also elsewhere on the board
/PB0: U3.6 (A1); also elsewhere on the board
/PB1: U3.7 (A0); also elsewhere on the board
/PC0: LDR2.1, R9.2; also elsewhere on the board
/PC1: LDR1.1, R8.2; also elsewhere on the board
/PC5: U3.5 (A2); also elsewhere on the board
/Power/Output: C3.1, R8.1, R9.1, R10.1, R11.1, R12.1, R13.1, U3.8 (+Vs); also elsewhere on the board
/Sensing/I2CBUS: R10.2, R11.2, U3.1 (SDA), U3.3 (O.S.); also elsewhere on the board
GND: C3.2, LDR1.2, LDR2.2, LED1.1 (K), U3.4 (GND); also elsewhere on the board
unnamed: LED1.2 (A), R13.2

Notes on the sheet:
DIGITAL SENSOR CIRCUIT
#Pin 1 on the STM
ANALOG SENSOR CIRCUIT

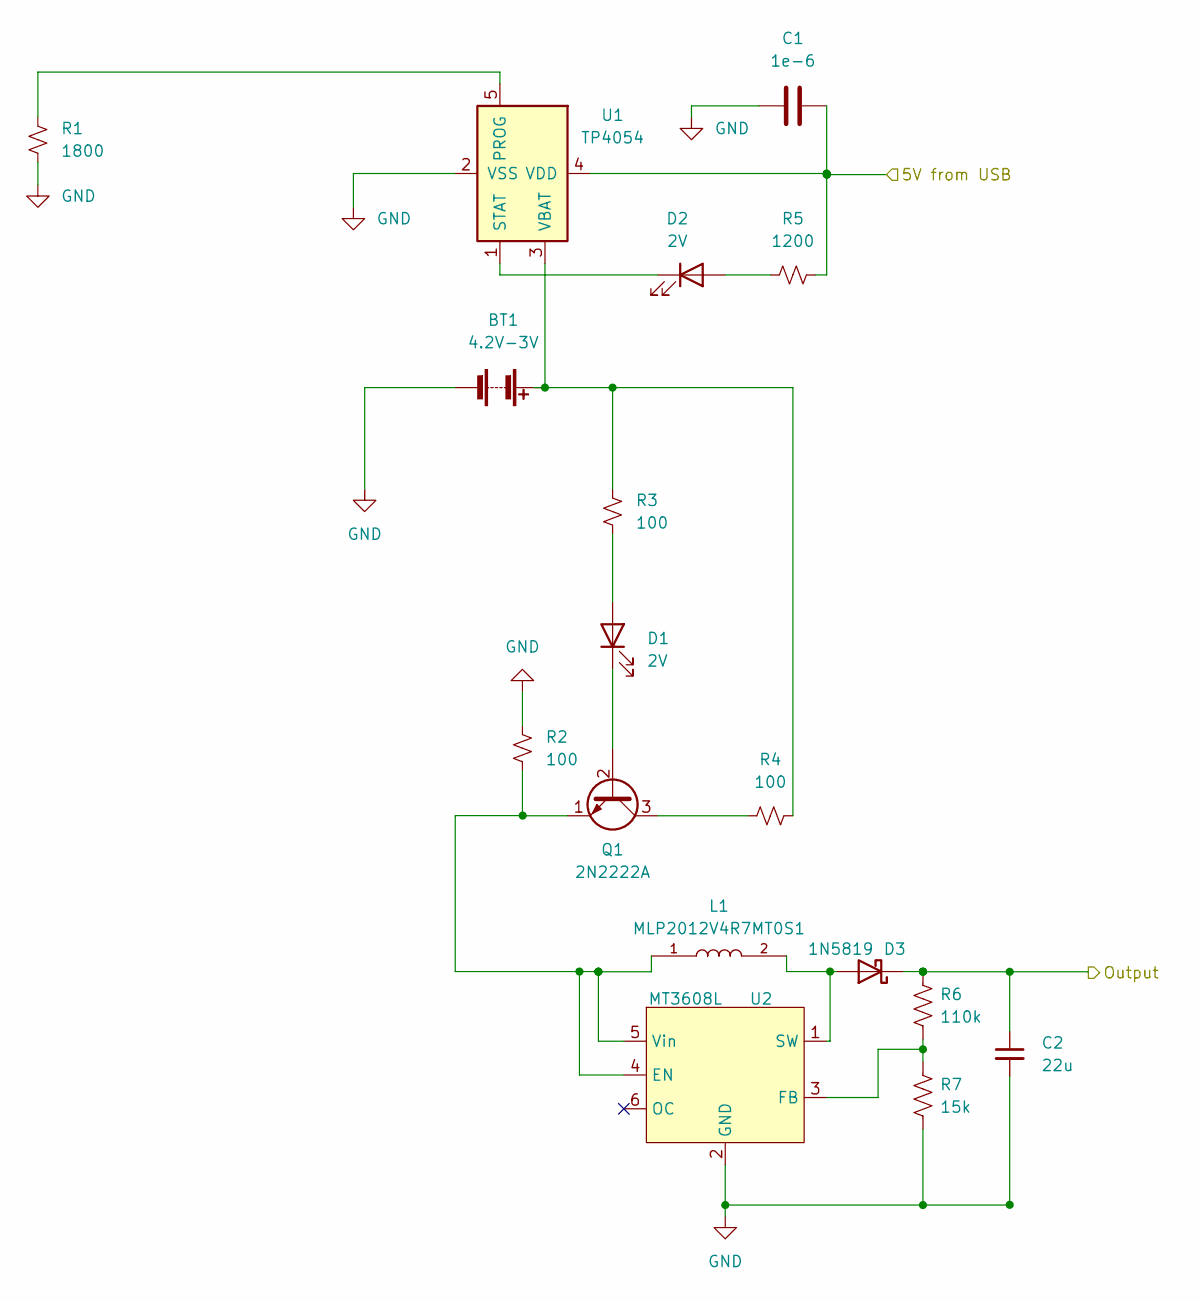
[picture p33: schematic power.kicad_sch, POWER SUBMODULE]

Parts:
BT1: 4.2V-3V; BatteryHolder_Keystone_1042_1x18650
C1: 1e-6; C_0201_0603Metric; LCSC C15849
C2: 22u; C_0805_2012Metric; LCSC C45783
D1, D2: 2V; LED_0805_2012Metric; LCSC C84256
D3: 1N5819; D_SOD-323; LCSC C191023
L1: MLP2012V4R7MT0S1; INDC2012X87N; LCSC C383376
Q1: 2N2222A; TO-92; LCSC C118536
R1: 1800; R_0201_0603Metric; LCSC C4177
R2, R3, R4: 100; R_0201_0603Metric; LCSC C22775
R5: 1200; R_0201_0603Metric; LCSC C22765
R6: 110k; R_0201_0603Metric; LCSC C25805
R7: 15k; R_0201_0603Metric; LCSC C22809
U1: TP4054; SOT-23-5; LCSC C32574
U2: MT3608L; SOT-23-6; LCSC C2932326

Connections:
/Power/Output: C2.1, D3.1 (K), R6.1; also elsewhere on the board
GND: BT1.2 (-), C1.2, C2.2, R1.2, R2.1, R7.2, U1.2 (VSS), U2.2 (GND); also elsewhere on the board
unnamed: BT1.1 (+), R3.1, R4.2, U1.3 (VBAT)
unnamed: C1.1, R5.2, U1.4 (VDD)
unnamed: D1.1 (K), Q1.2 (B)
unnamed: D1.2 (A), R3.2
unnamed: D2.1 (K), U1.1 (STAT)
unnamed: D2.2 (A), R5.1
unnamed: D3.2 (A), L1.2, U2.1 (SW)
unnamed: L1.1, U2.4 (EN), U2.5 (Vin)
unnamed: Q1.1 (E), R2.2
unnamed: Q1.3 (C), R4.1
unnamed: R1.1, U1.5 (PROG)
unnamed: R6.2, R7.1, U2.3 (FB)

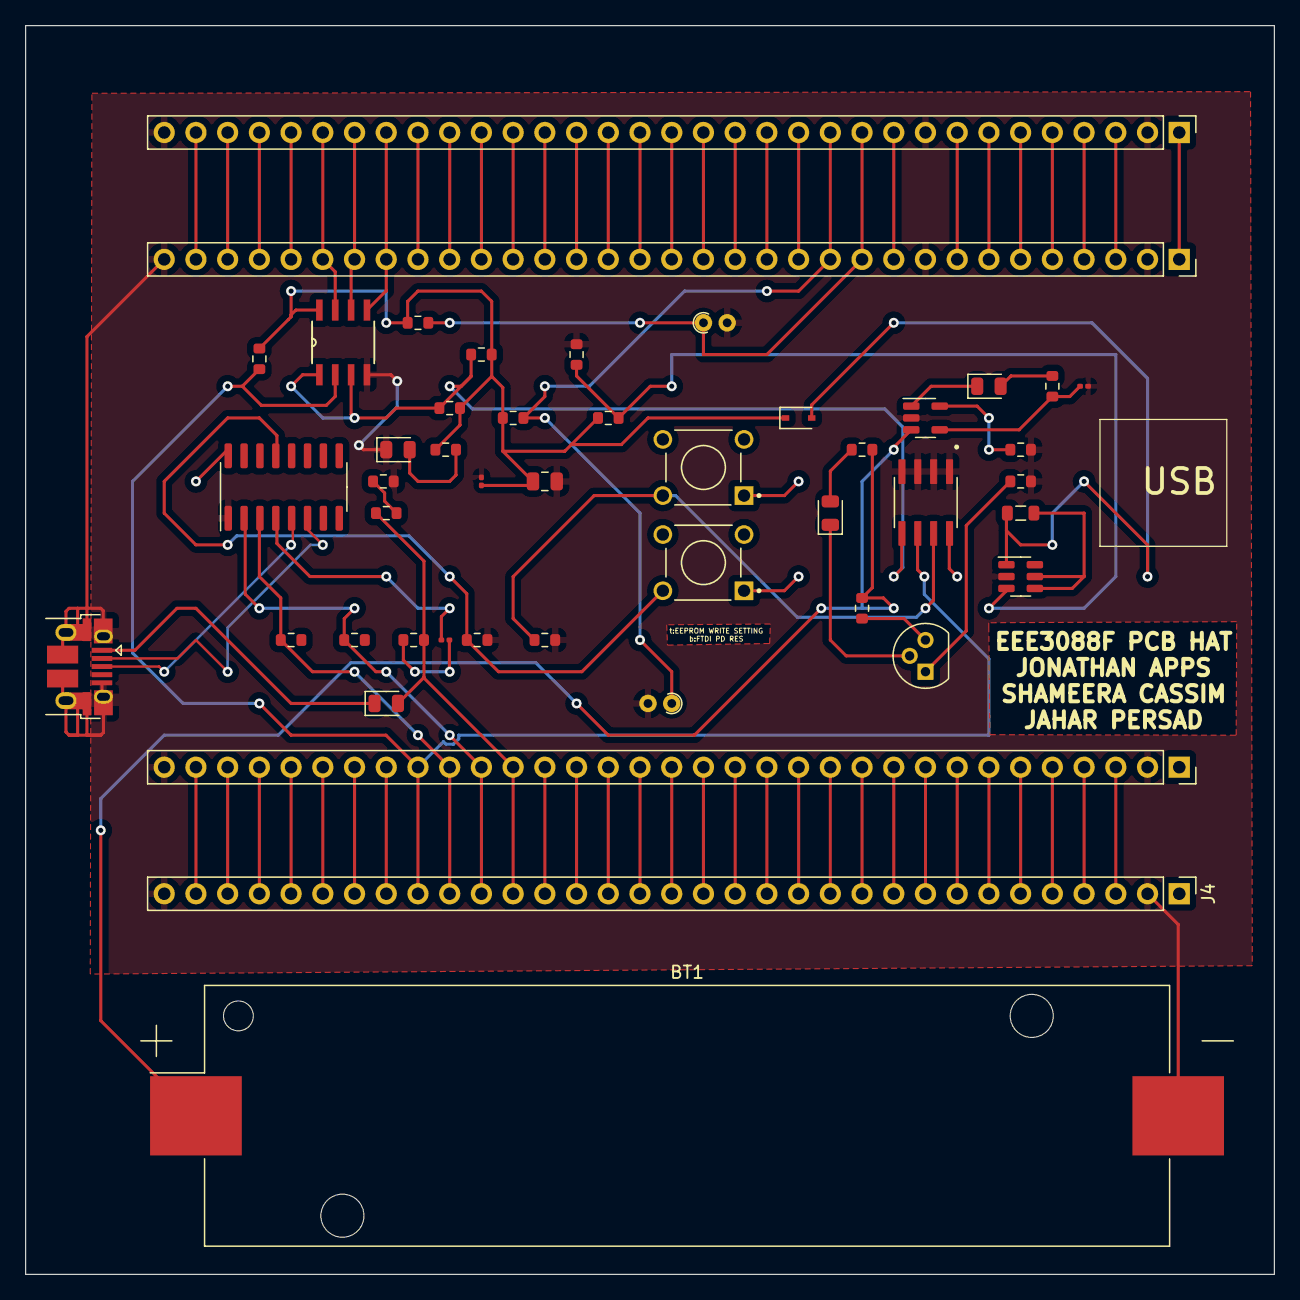
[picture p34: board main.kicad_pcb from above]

Board: 2 copper layers, 100.0 x 100.0 mm, 46 parts (0 on the bottom side), 84 nets.

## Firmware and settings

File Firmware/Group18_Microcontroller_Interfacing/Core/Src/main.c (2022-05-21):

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
/* Includes ------------------------------------------------------------------*/
#include "main.h"

/* USER CODE BEGIN Includes */
#include "string.h"

/* USER CODE END Includes */

 ADC_HandleTypeDef hadc;

I2C_HandleTypeDef hi2c2;

UART_HandleTypeDef huart1;

void SystemClock_Config(void);
static void MX_GPIO_Init(void);
static void MX_ADC_Init(void);
static void MX_I2C2_Init(void);
static void MX_USART1_UART_Init(void);
void debugPrintln(UART_HandleTypeDef *uart_handle, char _out[]);
void demoDataTransfer();
void checkAddress(UART_HandleTypeDef * huart, I2C_HandleTypeDef * hi2c, uint16_t DevAddress, uint32_t Num_Trials, uint32_t Timeout);
void writeToI2C(uint16_t EEPROM_DEVICE_ADDR, uint8_t madd, uint8_t Data, uint8_t Result);
void readFromI2C(uint16_t EEPROM_DEVICE_ADDR, uint8_t madd, uint8_t Data, uint8_t Result);
void lightSensingInit();

/* USER CODE BEGIN 0 */
	//General purpose Function to send a char array over
	//the UART and to automatically send a new line
	//character after it
	void debugPrintln(UART_HandleTypeDef *uart_handle, char _out[]){
		HAL_UART_Transmit(uart_handle, (uint8_t *) _out, strlen(_out), 60);
		char newline[2] = "\r\n";
		HAL_UART_Transmit(uart_handle, (uint8_t *) newline, 2, 10);
	}

	//Demo sending data over UART to laptop
	void demoDataTransfer(){
	debugPrintln(&huart1, "Hello, this is STMF0 Discovery board"); // print full line
	//Flash Blue LED
	HAL_GPIO_TogglePin(GPIOC, GPIO_PIN_8);
	HAL_Delay(1000);
	}

	void checkAddress(UART_HandleTypeDef * huart, I2C_HandleTypeDef * hi2c, uint16_t DevAddress, uint32_t Num_Trials, uint32_t Timeout){
		uint8_t i = 0, I2Creturn;
		uint8_t strbuf[40] = { 0 };

		for (i = 1; i < 128; i++) {
			I2Creturn = HAL_I2C_IsDeviceReady(&hi2c,DevAddress, Num_Trials, Timeout);
			if (I2Creturn != HAL_OK){ //No ACK Received At That Address
				debugPrintln(&huart, "No ACK recieved");
			}

			else if (I2Creturn == HAL_OK) { //ACK Received At That Address
				sprintf(strbuf, "ACK received on address: 0x%X", i);
				debugPrintln(&huart, strbuf);
			}

			HAL_Delay(100);
		}

		debugPrintln(&huart, "#######Scanning done######");
	}

	void writeToI2C(uint16_t EEPROM_DEVICE_ADDR, uint8_t madd, uint8_t Data, uint8_t Result) {
		uint8_t *sData = &Data;
		uint8_t *rData = &Result;
		memset(str, 0, sizeof(str));
		sprintf(str, "Writing 0x%X to EEPROM address 0x%X", Data, madd);
		debugPrintln(&huart2, str);
		I2CReturn = HAL_I2C_Mem_Write(&hi2c1, EEPROM_DEVICE_ADDR, madd, 2, sData, 1, HAL_MAX_DELAY);
		if (I2CReturn != HAL_OK) {
		debugPrintln(&huart2, "Write to address FAILED");
		}

	}

	void readFromI2C(uint16_t EEPROM_DEVICE_ADDR, uint8_t madd, uint8_t Data, uint8_t Result) {
		uint8_t *sData = &Data;
		uint8_t *rData = &Result;
		memset(str, 0, sizeof(str));
		sprintf(str, "Reading from EEPROM address 0x%X ", madd);
		debugPrintln(&huart2, str);
		I2CReturn = HAL_I2C_Mem_Read(&hi2c1, EEPROM_DEVICE_ADDR, madd, 2, rData, 1, HAL_MAX_DELAY);
		if (I2CReturn != HAL_OK) {
		debugPrintln(&huart2, "Read from address FAILED");
	}

    void lightSensingInit(){
        // Test case: Set GPIO pin high.
        //HAL_GPIO_WritePin(GPIOA, GPIO_PIN_10, GPIO_PIN_SET);

        // Get ADC values for 2 pins that the LDRS are connected to.
        HAL_ADC_Start(&hadc1); //Start HAL_ADC for first ADC pin.
        HAL_ADC_Start(&hadc2); //Start HAL_ADC for second ADC pin.
        HAL_ADC_PollForConversion(&hadc1, HAL_MAX_DELAY); //Poll ADC pin 1 for conversion (of the first LDR).
        raw = HAL_ADC_GetValue(&hadc1); //Get digital value
        HAL_ADC_PollForConversion(&hadc2, HAL_MAX_DELAY); //Poll ADC pin 2 for conversion (of the second LDR).
        raw2 = HAL_ADC_GetValue(&hadc2); //Get digital value.

        // Test: Set GPIO pin low
        //HAL_GPIO_WritePin(GPIOA, GPIO_PIN_10, GPIO_PIN_RESET);
        if (raw>raw2){ //if LDR1 has more light on it than LDR2:
            HAL_GPIO_WritePin(GPIOB, GPIO_PIN_12, GPIO_PIN_RESET); //Turn LDR2 off.
            HAL_GPIO_WritePin(GPIOA, GPIO_PIN_10, GPIO_PIN_SET); //Turn LDR1 on.
        }
        else if (raw2>raw){ //else, if LDR2 has more light on it than LDR1:
            HAL_GPIO_WritePin(GPIOA, GPIO_PIN_10, GPIO_PIN_RESET); //Turn LDR1 off.
            HAL_GPIO_WritePin(GPIOB, GPIO_PIN_12, GPIO_PIN_SET); //Turn LDR2 on.
        }
        // Convert to string and print
        sprintf(msg, "%hu\r\n", raw);
        HAL_UART_Transmit(&huart2, (uint8_t*)msg, strlen(msg), HAL_MAX_DELAY);
        sprintf(msg, "%hu\r\n", raw2);
        HAL_UART_Transmit(&huart2, (uint8_t*)msg, strlen(msg), HAL_MAX_DELAY);
        // Pretend we have to do something else for a while
        HAL_Delay(1);
    }

/* USER CODE END 0 */

/**
  * @brief  The application entry point.
  * @retval int
  */
int main(void)
{
  /* MCU Configuration--------------------------------------------------------*/

  /* Reset of all peripherals, Initializes the Flash interface and the Systick. */
  HAL_Init();

  /* Configure the system clock */
  SystemClock_Config();

  /* Initialize all configured peripherals */
  MX_GPIO_Init();
  MX_ADC_Init();
  MX_I2C2_Init();
  MX_USART1_UART_Init();
  /* USER CODE BEGIN 2 */
  checkAddress(&huart1, &hi2c1,(uint16_t) (i << 1), 3, 5);

  char str[60] = { 0 }; //Useful buffer for printing to UART
  uint8_t I2CReturn = 0; //Status var to indicate if HAL_I2C operation has succeeded (1) or failed (0);
  uint8_t i, j, Loop = 0; //Loop counters

  //Setup variables for reading and writing
  uint16_t EEPROM_DEVICE_ADDR = 0x55 << 1; //Address of EEPROM device on I2C bus
  uint16_t madd = 0x00; //Memory address variable containing a starting memory address for a location of memory in the EEPROM
  uint8_t Data = 0x10;//Data variable containing sStarting value to write to memory, could be any 8bit value
  uint8_t *sData = &Data; //Pointer to sending Data variable
  uint8_t Result = 0x00; //Variable to stored value read back from memory in
  uint8_t *rData = &Result; //Pointer to result data variable
  //Say hello over UART
  debugPrintln(&huart1, "Hello, this is STMF0 Discovery board: ");

  /* USER CODE END 2 */

  /* Infinite loop */
  /* USER CODE BEGIN WHILE */
  while (1)
  {
      //LDR TESTING FUNCTION CALL:
      lightSensingInit(); //This toggles the connected LEDs depending on the light on the LDRS on the HAT.

    /* USER CODE END WHILE */
	  //Demo sending data over UART to laptop
	  //uncomment out the following line and comment all other loop code out to test sending data over UART to laptop
	  //demoDataTransfer();

	  //Print and increment a loop counter for visual tracking/debugging purposes only
	  memset(str, 0, sizeof(str)); //Reset str to zeros
	  sprintf(str, "\rLoop count %d\n", Loop);//Format string to include the loop counter variable
	  debugPrintln(&huart2, str);
	  Loop = Loop + 1;

	  //Write and read back 5 different values to 5 different memory locations
	  for (i = 0; i < 5; i++) {
		  writeToI2C(EEPROM_DEVICE_ADDR, madd, Data, Result);
		  readFromI2C(EEPROM_DEVICE_ADDR, madd, Data, Result);
		  //PRINT READ VALUE
		  memset(str, 0, sizeof(str));
		  sprintf(str, "Received data: 0x%X \n", Result);
		  debugPrintln(&huart2, str);
		  //Increment address and data values and clear Result holder
		  madd = madd + 1;
		  Data = Data + 1;
		  Result = 0x00;
		  HAL_Delay(1000); //Pause
		  } //End for loop of reading and writing 5 addresses

	  //Read back last 5 values again:
	  madd = madd - 5;
	  for (j = 0; j < 5; j++) {
		  I2CReturn = HAL_I2C_Mem_Read(&hi2c1, EEPROM_DEVICE_ADDR, madd, 2, rData, 1, HAL_MAX_DELAY);
	  if (I2CReturn != HAL_OK) {
		  debugPrintln(&huart2, "Read from address FAILED");
	  }

	  //PRINT READ VALUE
	  memset(str, 0, sizeof(str));
	  sprintf(str, "Address 0x%X contains: 0x%X ", madd, Result);
	  debugPrintln(&huart2, str);
	  madd = madd + 1;
	  }

	  debugPrintln(&huart2, "-------------"); //Draw a line under a series of 5 before next while loop begins
	  //Flash Blue LED as visual check code is running
	  HAL_GPIO_TogglePin(GPIOC, GPIO_PIN_8);
	  HAL_Delay(DELAY);

	  }

    /* USER CODE BEGIN 3 */
  }
  /* USER CODE END 3 */
}

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


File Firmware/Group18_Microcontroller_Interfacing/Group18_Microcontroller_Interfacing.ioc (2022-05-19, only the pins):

Mcu.UserName=STM32F051R8Tx
PA10.Signal=USART1_RX
PA8.Signal=GPIO_Output
PA9.Signal=USART1_TX
PB0.Signal=ADC_IN8
PB1.Signal=ADC_IN9
PB10.Signal=I2C2_SCL
PB11.Signal=I2C2_SDA
PC0.Signal=ADC_IN10
PC1.Signal=ADC_IN11
PC5.Signal=ADC_IN15

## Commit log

2022-04-04 All kiCad files to be stored here
2022-04-04 All updated schematics, gerbers and error checking reports from old git organized and added
    [main-B_Cu.gbr, main-B_Mask.gbr, main-B_Paste.gbr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]
2022-04-04 updated microcontroller schematic and added documentation
    [1825910-6.step, CH340C.step, Draft_ASSEMBLY_COSTS.xlsx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]
2022-04-04 Week 5 BOMs added to documentation
    [BOM_Week_5__KiCad_.csv, Week_5_Assembly_Costs.xlsx, Week_5_BOM_Combined.xlsx]
2022-04-05 new power module
    [power.kicad_sch]
2022-04-05 Replace main.kicad_pcb
    [main.kicad_pcb]
2022-04-05 Replace sensing.kicad_sch
    [sensing.kicad_sch]
2022-04-05 Replace power.kicad_sch
    [power.kicad_sch]
2022-04-05 Replace outputs.kicad_sch
2022-04-05 Replace microcontroller_interfacing.kicad_sch
    [microcontroller_interfacing.kicad_sch]
2022-04-05 Replace main.kicad_sch
    [main.kicad_sch]
2022-04-05 Replace main.kicad_pro
2022-04-05 Replace main.kicad_prl
2022-04-05 updated microcontroller submodule
    [main.kicad_pcb, main.kicad_sch, microcontroller_interfacing.kicad_sch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]
2022-04-08 Replace main.kicad_pcb - FINALLLLLLLLL
    [main.kicad_pcb]
2022-04-08 updated gerbers and finalized PCB
    [main-B_Cu.gbr, main-B_Mask.gbr, main-B_Paste.gbr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]
2022-04-08 gerbers, BOM and CPL(pos) files added
    [Group 18 BOM.csv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]
2022-04-08 finalized gerbers and fabrication files
    [Group 18 BOM.csv, Group 18 BOM.xlsx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]
2022-04-12 Footprint folder updated
    [1825910-6.step, CH340C.step, MicroXNJ footprint.kicad_pcb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]
2022-04-12 added new jlcpcb files. other group members to double check
    [BOM-main.csv, Group 18 BOM.xlsx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]
2022-04-13 updated PCB & Assembly file
    [BOM-main.csv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]
2022-04-14 Updated PCB
    [main.kicad_pcb]
2022-04-14 Updated schematic (correct footprints)
    [main.kicad_sch]
2022-04-14 rewired PCB and changed relevant footprints. production files regenerated
    [BOM-main.csv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]
2022-05-21 EEPROM and UART code
2022-05-21 Documentation folder reorganized and code reference document uploaded
    [BOM_Week_5__KiCad_.csv, Draft_ASSEMBLY_COSTS.xlsx, Draft_Bill_Of_Materials_Microcontroller_Submodule.xlsx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]
2022-05-21 updates to read and write to I2C functions
2022-05-21 spelling error ron folder name corrected
    [Group18_Microcontroller_Interfacing.ioc, main.c]

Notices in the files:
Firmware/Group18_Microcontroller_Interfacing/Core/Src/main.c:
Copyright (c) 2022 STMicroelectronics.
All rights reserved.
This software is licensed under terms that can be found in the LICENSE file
